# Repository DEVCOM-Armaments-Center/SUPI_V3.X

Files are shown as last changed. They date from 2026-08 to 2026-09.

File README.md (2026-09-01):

# sUPI — Small Universal Payload Interface

**Technical Data Package, Version 3.3**

> **DISTRIBUTION STATEMENT A. APPROVED FOR PUBLIC RELEASE; DISTRIBUTION IS UNLIMITED.**

---

## Overview

sUPI is an interchangeable mechanical and electrical interface for attaching payloads to uncrewed
systems, primarily small UAS. It is a one-to-one peripheral interface: one platform, one payload, no
network.

sUPI was developed under U.S. Army Special Operations Command and has since been transitioned to
DEVCOM Armaments Center. The **CLIK Lite** adaptation in Appendix A of the Picatinny Common
Lethality Integration Kit (CLIK) Design Standard is modeled on sUPI. CLIK Lite exists for platforms
constrained in size, weight, and power — Short Range Reconnaissance and Purpose Built Attritable
System aircraft — where the full CLIK rail-and-network interface does not fit.

The standard is not redistributed here; request the current revision from the design activity.

sUPI is a **reference design**, intended to evolve. See `MFR_Reference_Design.md` for how to submit
recommendations.

### The Two Halves

| Half | Mounts to | Role |
| --- | --- | --- |
| **Platform side** | The vehicle | Gates and monitors payload power, switches USB, hosts the interface MCU |
| **Payload side** | The payload | Regulates platform battery to payload rails, carries the payload ID device |

Start with [`sUPI_Platform_Brief.md`](sUPI_Platform_Brief.md) or
[`sUPI_Payload_Brief.md`](sUPI_Payload_Brief.md) depending on which side you are integrating.

### Circuit Cards

| Card | Project | Assembly | Layers | Notes |
| --- | --- | --- | --- | --- |
| Platform | `PB-F-0213` | `PB-F-0210` A.6 (`100064667`) | 8 | The only platform-side card |
| Payload — Fusion | `PB-F-0212` | `PB-F-0209` A.3 (`100068622-001`) | 4 | Full-capability payload card |
| Payload — Medium R2 | `PB-F-0230` | `PB-F-0230` A.6 | 2 | Compact option, adds USB-to-UART |

---

## Electrical Interface

### Platform → Platform-Side Card

| Signal | Range |
| --- | --- |
| `VBATT` / `VBATT_RET` | 13 – 25.2 VDC (4S–6S pack) |
| `GPIO` | Typically PWM, ±5 VDC |
| `USB` | 0 – 3.3 VDC |

### Payload-Side Card → Payload

| Signal | Range |
| --- | --- |
| `VBATT` / `VBATT_RET` | 13 – 25.2 VDC, passed through |
| `V1` | Regulated **3.3 or 5 VDC** — set by solder bridge |
| `V2` | Regulated **5, 7.4, or 12 VDC** — set by solder bridge |
| `GPIO` | Typically PWM, ±3.3 VDC |
| `USB` | 0 – 3.3 VDC |

> **V1 and V2 are hardware-selected.** The rails are set by solder-bridge placement
> at build time. Verify the bridges match the payload before first power-on.

Both cards use solder pads for field wiring: 18–22 AWG for power, 24–30 AWG for signals.

### Board Markings

- **Platform pads:** `VBATT`, `GND`, `GPIO 0`, `GPIO 1`, `+USB−`, `AUX`
- **Platform jumpers:** `DETECT PAYLOAD`, `SELECT`, `FORCE ON`, `LO BATT CUTOFF`
- **Payload pads:** `VBATT`, `GND`, `V1`, `V1 OK`, `V2`, `V2 OK`, `USB DP`, `USB DM`, `GPIO 0`, `GPIO 1`
- **Payload selectors:** `V1SEL` (`3V3` / `5V`), `V2SEL` (`5V` / `7V4` / `12V`)

`FORCE ON` overrides the detect gate — confirm its state before flight.

### Mating Connection

A **9-contact, 0.100"-pitch right-angle spring-pin interface.** The payload side carries the spring
pins (Mill-Max 829 series); the platform side carries the mating targets (Mill-Max 399 series).
Power crosses on separate, larger single-pin contacts.

---

## Platform Card — `PB-F-0210` A.6

8-layer FR4, 0.5 oz outer / 1 oz inner copper, 0.0586 in finished thickness, ENIG per IPC-4552,
green mask. Controlled impedance: 90 Ω ±10 % differential on layer 5, referenced to layers 4 and 6.
Fabrication and inspection per MIL-PRF-31032/1 Type 3.

| Function | Device |
| --- | --- |
| Interface MCU | STM32C011F6 (Arm Cortex-M0+) |
| Payload power switch | MPQ5069, 7 mΩ protection switch with current monitor |
| Current sense | ACS711, ±15 A bidirectional Hall-effect with overcurrent fault output |
| Ideal-diode / reverse-polarity control | NCV68261 driving an NTTFS2D1N04HL N-channel MOSFET |
| Undervoltage supervisor | LTC2965 |
| Supply supervisor | MAX821, 2.78 V |
| Detect / enable logic | SN74LVC1G08 AND gate, SN74AUP2G04 inverter |
| Logic 3.3 V rail | NCP730 LDO, 150 mA |
| USB routing | TC7USB40MU dual SPDT, MAX20336 DPST |
| Transient protection | SMF26A 26 V TVS on `VBATT`, SMF3.3 on signals, PESD5V0C2UM on USB |

---

## Payload Cards

Two payload-side cards are released. Both present the same interface to the platform and both carry
the DS2431 1-Wire EEPROM that the platform MCU reads to identify an attached payload, so a payload
built to this interface inherits its identity device from the card.

### Fusion Payload — `PB-F-0209` A.3

The full-capability card. 4-layer FR4, 1 oz copper, 0.0442 in finished thickness, ENIG, green mask.
Controlled impedance 100 Ω ±10 % differential. Fabrication per MIL-PRF-31032/1 Type 3.

| Function | Device |
| --- | --- |
| V1 / V2 regulation | MAX25254, dual 36 V input / 0.8–14 V output synchronous buck, XEL4030 0.47 µH inductors |
| Payload ID / detect | DS2431 1-Wire EEPROM, 1 kbit |
| Input protection | NCV68261 + NTTFS2D1N04HL N-channel MOSFET, DMP610DL P-channel blocking FET |
| Logic 3.3 V rail | NCP730 LDO, 150 mA |
| Supply supervisor | MAX821, 2.78 V |
| USB routing | TC7USB40MU dual SPDT, MAX20336 DPST |
| Transient protection | SMF26A 26 V TVS on `VBATT`, SMF3.3 on signals, PESD5V0C2UM on USB |

### Medium R2 Payload — `PB-F-0230` A.6

A compact alternative for payloads that do not need the dual selectable rails. 2-layer 370HR FR4,
1 oz copper, ENIG, green mask, vias unfilled, no board-manufacturer markings, assembly serial
number silkscreened. Assembly to IPC J-STD-001 Class 3 and IPC-A-610 Class 3.

**Tested against all sUPI v3.X releases.**

| Function | Device |
| --- | --- |
| Regulation | MCP16361, 48 V 2 MHz buck, 2.2 µH inductor |
| Payload power switch | NCP380, fixed current-limiting power distribution switch |
| Supply supervisor | TPS389030 |
| Payload ID / detect | DS2431 1-Wire EEPROM, 1 kbit |
| **USB-to-UART bridge** | **FT232RN** — converts the interface USB link to a serial port on the payload |
| Wire-to-board connectors | 2× JST SM04B-SRSS-TB, 4-position 1.25 mm |
| Status indication | 2× red 625 nm LEDs |
| Mating contacts | 9-contact right-angle spring-pin header |
| Transient protection | SMF26A 26 V TVS, P4FL3.3A on signals, SS3060HE Schottky |

The USB-to-UART bridge is the substantive difference: a payload using the Medium card gets a serial
interface without implementing USB itself.

**Variant.** One variant assembly is released, `PB-F-0230` A.4. It is identical to A.6 except that
`R6` and `R7` — two 0 Ω links — are not populated. Check which assembly you have before assuming a
link is present.

---

## Mechanical Interface

Both halves mount with **M3 × 0.5 mm thread, 8 mm long, black-oxide stainless steel Phillips
flat-head screws.**

| Half | Screws | Controlling drawing |
| --- | --- | --- |
| Platform side | 3X M3 | `19200_13122518` |
| Payload side | 4X M3 | `19200_13122514` |

Two accepted installation methods, either half:

1. **Direct mount** — drill and tap the sUPI hole pattern into the host structure.
2. **Adapter** — fabricate an adapter carrying the sUPI hole pattern on one face and mating to an
   existing interface on the other. Preferred where the host structure cannot be modified.

The payload-side pattern carries a CG reference callout. Position the interface so the center of
gravity lands as close to that point as the installation allows.

### Part Tree

Assembly **13122513**, one each of:

| Part No. | Nomenclature | Material | Process / Finish |
| --- | --- | --- | --- |
| `13122514` | V-Mount Base | 6061-T6 per ASTM B209, or polymer powder bed fusion | Bead blast; hard anodize per MIL-A-8625F Type III Class 2, black, sealed |
| `13122515` | Short Button | 6061-T6 per ASTM B209 | Bead blast; hard anodize per MIL-A-8625F Type III Class 2, black, sealed |
| `13122516` | Small Button Cover | PA12 or PA6 | Polymer powder bed fusion (MJF, SLS, or SAF); depowder, media blast, optional black dye |
| `13122517` | Connector Cover | 6061-T6 per ASTM B209, or polymer powder bed fusion | Bead blast; hard anodize per MIL-A-8625F Type III Class 2, black, sealed |
| `13122518` | V-Mount | 6061-T6 per ASTM B209 | Mask/plug threaded holes, then bead blast and hard anodize per MIL-A-8625F Type III Class 2, black, sealed |

Threaded and clearance features:

- `13122514` — 4× M3 clearance, 90° countersunk; 2× M2 × 0.4 tapped
- `13122517` — 2× M2 × 0.4 clearance
- `13122518` — 3× M3 clearance, 90° countersunk; 3× M1.6 × 0.35 tapped, through

Dimensions are in inches; interpret per ANSI/ASME Y14.5M-2009. **The drawings are the authority** —
each detail sheet names a design model required to complete the product definition, and
undimensioned features are taken from that model. Do not machine from the PDFs alone.

---

## Before You Fabricate Boards

| Note | Direction |
| --- | --- |
| [`MFR_DNP.md`](sUPI%20Electrical/MFR_DNP.md) | Do not populate platform `U3`, `R1`–`R4`, `C2`, `JP1` — the undervoltage cutoff is still in development and can block power to the payload |
| [`MFR_Rework.md`](sUPI%20Electrical/MFR_Rework.md) | Remove platform `U11` and `U12` and bridge pin 2 to pin 4 on each footprint. The bridge is the workaround; removal alone leaves the net open |
| [`MFR_Capacitors.md`](sUPI%20Electrical/MFR_Capacitors.md) | Superseded — its alternates are already in the released BOMs and no Murata parts remain. Build from the BOM. |

All three components named by the do-not-populate and rework notes are still present in the released
platform BOM, so both notes remain live direction.

With that direction applied, the platform card has **no undervoltage supervision and no supply
supervisor**, and its detect/enable gate is strapped to a permanent pass-through. If your
application depends on brownout protection or supervised power sequencing, treat that as an open
engineering item.

The Medium R2 assembly carries its own do-not-populate list on the assembly drawing. For the base
A.6 assembly that list is empty; for the A.4 variant it is `R6`, `R7`.

---

## Firmware

`supi_firmware.hex` is the platform MCU image: 20,440 bytes, load address `0x08000000`, targeting
the STM32C011 (Arm Cortex-M0+). Intel HEX format.

---

## Revision History

See [`CHANGELOG.md`](CHANGELOG.md). Known documentation defects are listed in
[`KNOWN_ISSUES.md`](KNOWN_ISSUES.md).

v3.3 is a manufacturability and fit release on the mechanical side — it removes special tooling from
the machining plan and takes slop out of the mating stack. On the electrical side it adds the
Medium R2 payload card and re-releases all three boards with updated component sourcing.

**v3.3 hardware is physically marked.** Check the engraved version number before mating
mixed-vintage halves: earlier parts have looser fit, and earlier `13122515` buttons have the taller
profile that was prone to bending.

---

## Package Contents

```
.
├── CHANGELOG.md                     Mechanical design change history, v3.1 → v3.3
├── KNOWN_ISSUES.md                  Errata — read before fabricating or machining
├── MFR_Reference_Design.md          Scope of the reference design; how to submit feedback
├── sUPI_Platform_Brief.md           Platform-side integration brief
├── sUPI_Payload_Brief.md            Payload-side integration brief
├── assets/                          Figures for the briefs and changelog
│
├── sUPI Mechanicals/
│   ├── 19200_13122513_v3-3.pdf      Assembly drawing
│   ├── 19200_1312251[4-8]_v3-3.pdf  Detail drawings
│   └── 19200_*_v3-3.stp             Solid models (STEP)
│
├── sUPI Electrical/
│   ├── MFR_DNP.md                   Do-not-populate direction
│   ├── MFR_Rework.md                Platform rework work instructions
│   ├── MFR_Capacitors.md            Capacitor sourcing history
│   ├── Platform/PB-F-0213 …/        Altium project: SRC (schematics, PCB), FAB, ASM
│   └── Payload/
│       ├── PB-F-0212 …/             Fusion payload: SRC, FAB, ASM
│       └── PB-F-0230 …/             Medium R2: SRC, FAB, ASM (base and variant)
│
└── sUPI Firmware/
    └── supi_firmware.hex            Platform MCU image
```

Each board's `FAB-` folder carries the fabrication drawing, GerberX2, IPC2581, ODB++, and NC Drill
data. Each `ASM-` folder carries the assembly drawing and the bill of materials with pick-and-place.

### Where to Start

| You are | Read, in order |
| --- | --- |
| **Platform integrator** | Platform brief → assembly drawing → platform schematics |
| **Payload integrator** | Payload brief → assembly drawing → pick a payload card → its schematics |
| **Fabricating boards** | `MFR_*.md` notes → fabrication drawing → Gerbers / ODB++ → BOM |
| **Machining parts** | Detail drawing + its matching STEP model |
| **Bringing up firmware** | Platform schematics, MCU section → `supi_firmware.hex` |
| **Writing a compliant payload** | Picatinny CLIK Design Standard, Appendix A (request from the design activity), then the payload brief |

---

## Conventions

- **Mechanical part numbers** are 8-digit design-activity numbers, prefixed in filenames with CAGE
  code `19200` and suffixed with the TDP version (`_v3-3`).
- **Circuit card part numbers** are `PB-F-####`. Project folders carry the project number; the
  fabrication and assembly folders inside carry their own numbers and an `A.n` revision.
- **Dimensions** are in inches unless otherwise specified; mechanical tolerances per
  ANSI/ASME Y14.5M-2009, board drawings per ASME Y14.5M-1994 and IPC-2221/2222.
- **Mechanical files:** `.pdf` released drawing, `.stp` neutral solid model.
- **Electrical files:** `.PDF` fabrication and assembly drawings, `.SchDoc` / `.PcbDoc` Altium
  source, GerberX2, `.cvg` IPC2581, ODB++ archives, NC Drill, `.xlsx` BOM and pick-and-place.
- **Packaging and marking** per MIL-STD-2073-1 Method 10 and MIL-STD-130.

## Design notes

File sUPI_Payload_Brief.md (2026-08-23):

# Small Universal Payload Interface (sUPI) — Payload Side Brief

**sUPI v3.3**

> **DISTRIBUTION STATEMENT A. APPROVED FOR PUBLIC RELEASE; DISTRIBUTION IS UNLIMITED.**

---

## Overview

The sUPI interface provides an interchangeable interface to connect payloads to UxS platforms such
as drones. The interface is a subset of the Picatinny Common Lethality Interface Kit (CLIK) Design
Standard. The interface supports a detect mechanism in which the payload signals are controlled by
the platform's interface board. The payload interface board provides power to the payload and
connectivity for USB and GPIOs passed through the physical / electrical interface.

---

## Electrical Interface for Payload

The sUPI payload side electronics board has solder pads for connecting wires to the payload
interfaces. Connections should be made with 18–22 AWG wire for power (`VBATT`, `VBATT_RET`) and
24–30 AWG for signals, as indicated in the wiring diagram (Figure 1).

The payload board will provide regulated power based upon solder bridge placement over the `V1SEL`
and `V2SEL` selections.

| Signal | Range |
| --- | --- |
| `VBATT` | Platform battery, 13 to 25.2 VDC |
| `VBATT_RET` | Battery return |
| `V1` | Regulated power, 3.3 or 5 VDC |
| `V2` | Regulated power, 5, 7.4 or 12 VDC |
| `GPIO` | Typically PWM, ±5 VDC |
| `USB` | 0 to 3.3 VDC |

### Rail Selection

`V1` and `V2` are set by solder bridge at build time; there is no runtime negotiation. Verify the
bridges match the payload's requirements before first power-on.

| Selector | Options |
| --- | --- |
| `V1SEL` | `3V3` or `5V` |
| `V2SEL` | `5V`, `7V4` (7.4 V), or `12V` |

### Solder Pads

The payload board silkscreen labels its wiring pads directly: `VBATT`, `GND`, `V1`, `V1 OK`, `V2`,
`V2 OK`, `USB DP`, `USB DM`, `GPIO 0`, `GPIO 1`.

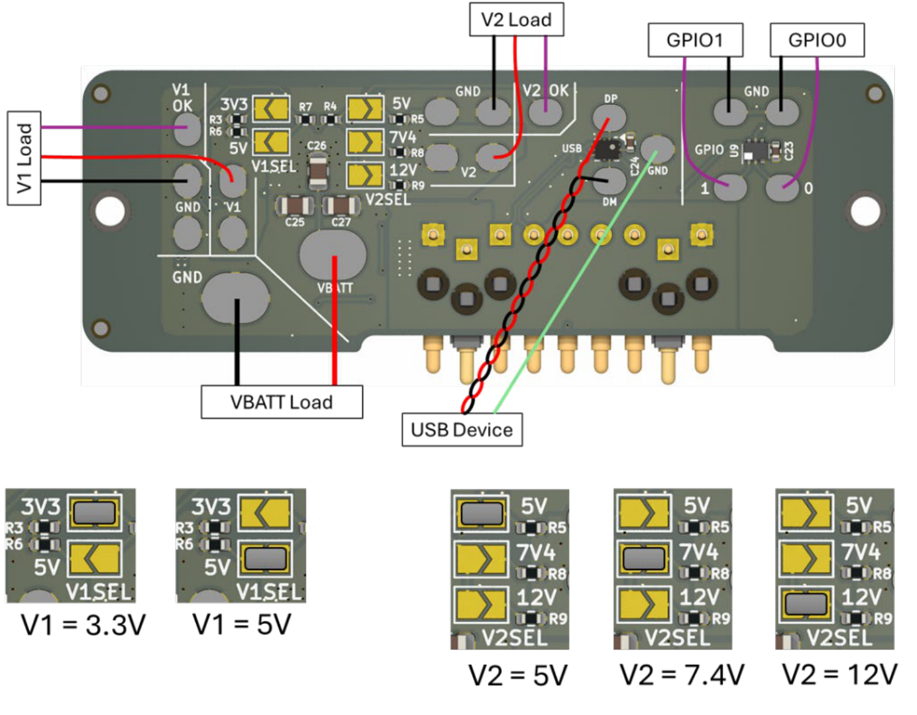
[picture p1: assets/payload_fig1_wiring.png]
Figure 1 — Payload side wiring and rail selection. Board pads at top; V1SEL and V2SEL solder bridge options below.


**Figure 1.** Payload side wiring diagram and rail selection. Lower panels show the valid `V1SEL`
and `V2SEL` solder bridge placements.

---

## Mechanical Interface for Payload

The sUPI Payload Side is intended to be mounted to a payload via **4X M3 × 0.5 mm thread, 8 mm
long, black-oxide stainless steel Phillips flat head screws** (e.g. McMaster PN 91698A304). The
mounting hole pattern is shown in Figure 2.

Existing payloads should be modified in one of the following ways to install a sUPI Payload Side
interface:

- **Drill and tap 4X holes** into the payload as shown in Figure 2, in the desired location for
  mounting the sUPI payload side. For a UAV platform, it is recommended that the vehicle CG align as
  closely as possible with the point indicated in Figure 2.
- **Create a custom adapter** that includes the sUPI Payload Side hole pattern and enables mounting
  to an existing mounting interface on a payload.

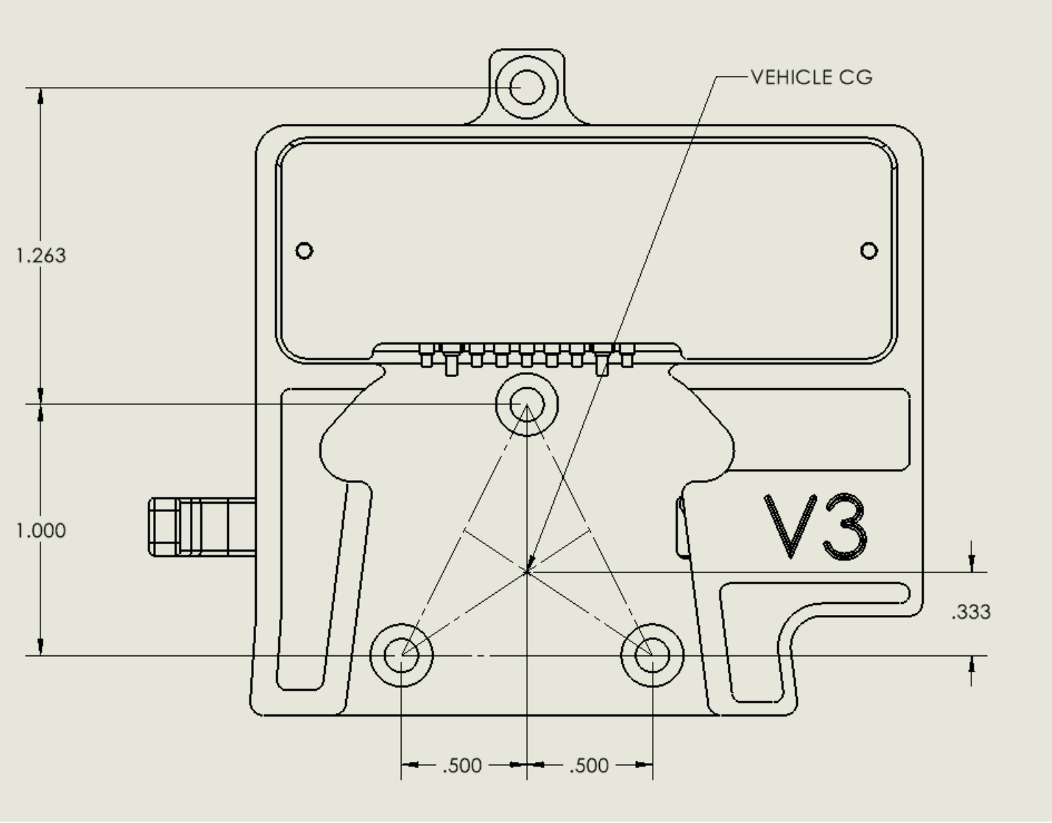
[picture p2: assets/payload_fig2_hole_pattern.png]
Figure 2 — Payload side mounting hole pattern, four M3 holes, with the vehicle CG reference point marked


**Figure 2.** Payload side mounting hole pattern — 4X M3, viewed from the mounting face. Dimensions
in inches. The `VEHICLE CG` callout marks the recommended center-of-gravity reference point. The two
smaller holes are M2 board-mounting features, not host mounting points.

Refer to drawing `19200_13122514` for controlling dimensions and tolerances.

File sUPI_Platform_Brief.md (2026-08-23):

# Small Universal Payload Interface (sUPI) — Platform Side Brief

**sUPI v3.3**

> **DISTRIBUTION STATEMENT A. APPROVED FOR PUBLIC RELEASE; DISTRIBUTION IS UNLIMITED.**

---

## Overview

The sUPI interface provides an interchangeable interface to connect payloads to UxS platforms such
as drones. The interface is a subset of the Picatinny Common Lethality Interface Kit (CLIK) Design
Standard. The interface supports a detect mechanism in which the payload signals are controlled by
the platform's interface board. The payload interface board provides power to the payload and
connectivity for USB and GPIOs passed through the physical / electrical interface.

---

## Electrical Interface for Platform

The sUPI platform side electronics board has solder pads for connecting wires to platform avionics.
Connections should be made with 18–22 AWG wire for power (`VBATT`, `VBATT_RET`) and 24–30 AWG for
signals, as indicated in the wiring diagram (Figure 1).

The platform will need to provide the following to the sUPI interface board:

| Signal | Range |
| --- | --- |
| `VBATT` | Platform battery, 13 to 25.2 VDC |
| `VBATT_RET` | Battery return |
| `GPIO` | Typically PWM, ±5 VDC |
| `USB` | 0 to 3.3 VDC |

The 13 to 25.2 VDC range corresponds to a 4S–6S lithium-polymer pack.

### Solder Pads and Jumpers

The platform board silkscreen labels its wiring pads and configuration jumpers directly:

- **Wiring pads:** `VBATT`, `GND`, `GPIO 0`, `GPIO 1`, `+USB−`, `AUX`
- **Configuration jumpers:** `DETECT PAYLOAD`, `SELECT`, `FORCE ON`, `LO BATT CUTOFF`

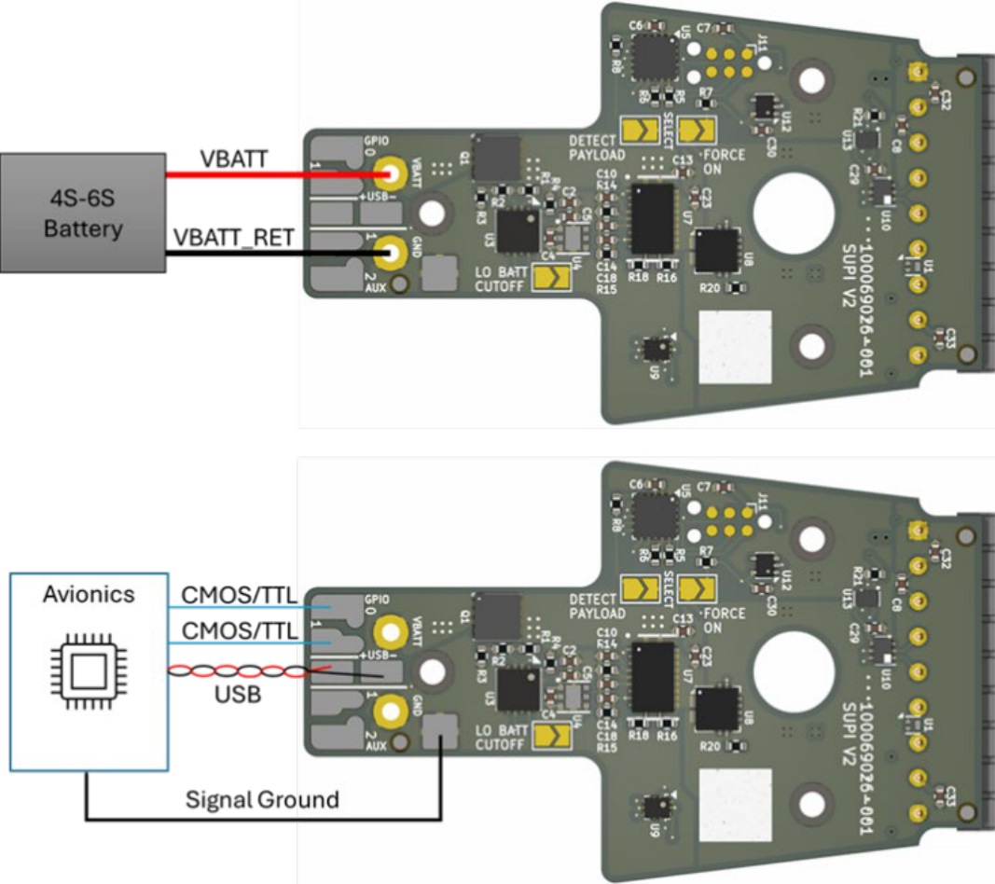
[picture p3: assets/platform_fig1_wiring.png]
Figure 1 — Platform side wiring. Top: battery connection to VBATT and GND. Bottom: avionics connections to GPIO, USB, and ground.


**Figure 1.** Platform side wiring diagram. Battery to `VBATT` / `GND`; avionics to `GPIO`, `+USB−`,
and ground.

---

## Mechanical Interface for Platform

The sUPI Platform Side is intended to be mounted to a platform via **3X M3 × 0.5 mm thread, 8 mm
long, black-oxide stainless steel Phillips flat head screws** (e.g. McMaster PN 91698A304). The
mounting hole pattern is shown in Figure 2.

Platforms should be modified in one of the following ways to install a sUPI Platform Side
interface:

- **Drill and tap 3X holes** into the platform as shown in Figure 2, in the desired location for
  mounting the sUPI Platform Side.
- **Create a custom adapter** that includes the sUPI platform side hole pattern and enables mounting
  to an existing mounting interface on a platform.

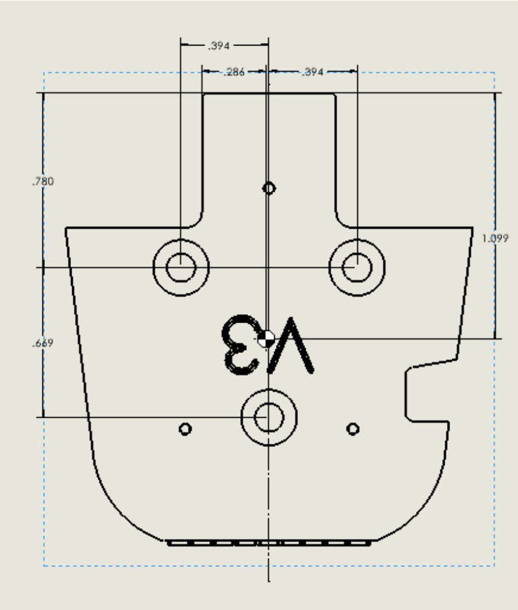
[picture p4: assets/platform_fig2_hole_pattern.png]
Figure 2 — Platform side mounting hole pattern, three M3 holes


**Figure 2.** Platform side mounting hole pattern — 3X M3, viewed from the mounting face.
Dimensions in inches. The three smaller holes are M1.6 board-mounting features, not host mounting
points.

Refer to drawing `19200_13122518` for controlling dimensions and tolerances.

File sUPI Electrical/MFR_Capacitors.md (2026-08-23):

# sUPI Electrical Interfaces — Capacitors

**DEPARTMENT OF THE ARMY**
U.S. Army Combat Capabilities Development Command, Armaments Center
Picatinny Arsenal, New Jersey 07806-5000

| | |
| --- | --- |
| **Office Symbol** | FCDD-ACE-P |
| **Date** | 30 March 2026 |
| **Subject** | sUPI Electrical Interfaces Capacitors |
| **Applies to** | Payload card `PB-F-0209`, platform card `PB-F-0210` |

> **DISTRIBUTION STATEMENT A. APPROVED FOR PUBLIC RELEASE; DISTRIBUTION IS UNLIMITED.**

> ### Superseded — build from the BOM
>
> The alternate part numbers below are **already in the released v3.3 bills of material.** No Murata
> parts remain on any of the three circuit cards, and several passive positions are multi-sourced
> beyond what this note lists. Build from the released BOM.

---

## Background

Note Murata's business statement regarding the use of their products for weapon systems:
<https://www.murata.com/en-us/support/militaryrestriction>

To reduce burden, the following were identified as possible alternatives. Values, dielectrics,
voltage ratings, and package sizes are unchanged from the BOMs as they stood at the time.

---

## Payload

| Ref | Qty | Value | Description | Alternate MPN | Manufacturer |
| --- | --- | --- | --- | --- | --- |
| `C1`, `C6` | 2 | 4.7 µF 50 V | CAP CER 4.7UF 50V X7R 0805 | `C2012X7R1H475K125AC` | TDK |
| `C2` | 1 | 2.2 µF 35 V | CAP CER 2.2UF 35V X5R 0402 | `C1005X5R1V225K050BC` | TDK |
| `C3` | 1 | 10 µF 50 V | CAP CER 10UF 50V X5R 0805 | `CL21A106KBYQNNE` | Samsung |
| `C4`, `C7`, `C10`, `C11`, `C21`, `C22`, `C23`, `C24` | 8 | 0.1 µF 50 V | CAP CER 0.1UF 50V X7R 0402 | `CGA2B3X7R1H104M050BB` | TDK |
| `C5`, `C9` | 2 | 10 µF 6.3 V | CAP CER 10UF 6.3V X5R 0402 | `GMC04X5R106M6R3NT` | CAL-Chip Electronics |
| `C8` | 1 | 10000 pF 50 V | CAP CER 10000PF 50V X7R 0402 | `CGA2B3X7R1H103K050BB` | TDK |
| `C12`, `C13` | 2 | 10 pF 50 V | CAP CER 10PF 50V C0G/NP0 0402 | `04025U100F4T2A` | Kyocera AVX |
| `C14`–`C19` | 6 | 22 µF 25 V | CAP CER 22UF 25V X5R 0805 | `C2012X5R1V226M125AC` | TDK |

## Platform

| Ref | Qty | Value | Description | Alternate MPN | Manufacturer |
| --- | --- | --- | --- | --- | --- |
| `C1`, `C2`, `C6`, `C7`, `C13`, `C18`, `C23`, `C27`–`C33` | 14 | 0.1 µF 50 V | CAP CER 0.1UF 50V X7R 0402 | `C1005X7R1H104K050BB` | TDK |
| `C3`, `C11`, `C12` | 3 | 10 µF 50 V | CAP CER 10UF 50V X5R 0805 | `C0805B106K050T` | Holy Stone Enterprise Co |
| `C4`, `C14` | 2 | 10000 pF 50 V | CAP CER 10000PF 50V X7R 0402 | `CC0402KRX7R9BB103` | YAGEO |
| `C5`, `C9` | 2 | 10 µF 6.3 V | CAP CER 10UF 6.3V X5R 0402 | `CL05A106MP5NUNC` | Samsung |
| `C8` | 1 | 4700 pF 50 V | CAP CER 4700PF 50V X7R 0402 | `C0402C472K5RACTU` | Kemet |
| `C10` | 1 | 0.33 µF 10 V | CAP CER 0.33UF 10V X5R 0402 | `CGA2B1X7S1C334M050BC` | TDK |
| `C24` | 1 | 4.7 µF 50 V | CAP CER 4.7UF 50V X7R 0805 | `CGA4J1X7R1H475K125AC` | TDK |

---

## Notes on the Substitutions

- Two positions were already TDK and unchanged: payload `C25`–`C27` and platform
  `C15`–`C22`, both 22 µF 35 V `C2012X5R1V226M125AC` (TDK).
- Platform `C10` was a `GRT`-series part (automotive, soft-termination); the alternate is an `X7S`
  dielectric rather than the original `X5R`. The released BOM adopted the `X7S` part at 16 V.

---

**Respectfully submitted,**

Robert Barone Jr, PMP \
Special Project APO \
U.S. Army Combat Capabilities Development Command, Armaments Center \
Picatinny Arsenal, NJ 07806 \
W: 520-684-1640 \

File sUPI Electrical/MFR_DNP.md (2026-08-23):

# sUPI Electrical Interfaces — Do Not Populate

**DEPARTMENT OF THE ARMY**
U.S. Army Combat Capabilities Development Command, Armaments Center
Picatinny Arsenal, New Jersey 07806-5000

| | |
| --- | --- |
| **Office Symbol** | FCDD-ACE-P |
| **Date** | 30 March 2026 |
| **Subject** | sUPI Electrical Interfaces Do Not Populate |
| **Applies to** | Platform card `PB-F-0210` (assembly `100064667`) |

> **DISTRIBUTION STATEMENT A. APPROVED FOR PUBLIC RELEASE; DISTRIBUTION IS UNLIMITED.**

---

## Direction

The low-battery / undervoltage cutoff feature of the sUPI reference design is under development and
in its current form can prevent power being supplied to sUPI payloads.

Unless the feature is specifically required, **do not populate** the following components on the
**platform** board. Omitting them is also a cost saving.

| Reference | Device | Function |
| --- | --- | --- |
| `U3` | LTC2965HDD | Undervoltage supervisor |
| `R1` | 787 kΩ, 1%, 0402 | Undervoltage threshold divider |
| `R2` | 12.4 kΩ, 0.1%, 0402 | Undervoltage threshold divider |
| `R3` | 200 kΩ, 0.1%, 0402 | Undervoltage threshold divider |
| `R4` | 1 kΩ, 1%, 0402 | Supervisor support |
| `C2` | 0.1 µF, 50 V, 0402 | Supervisor decoupling |
| `JP1` | — | Low-battery cutoff jumper |

**Effect:** the platform board is built without undervoltage lockout, so payload power continues to
be supplied as the battery falls. If your application depends on brownout protection, implement it
in platform avionics upstream of this interface.

---

**Respectfully submitted,**

Robert Barone Jr, PMP \
Special Project APO \
U.S. Army Combat Capabilities Development Command, Armaments Center \
Picatinny Arsenal, NJ 07806 \
W: 520-684-1640 \

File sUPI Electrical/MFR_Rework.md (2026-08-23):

# sUPI Electrical Interfaces — Platform Rework

**DEPARTMENT OF THE ARMY**
U.S. Army Combat Capabilities Development Command, Armaments Center
Picatinny Arsenal, New Jersey 07806-5000

| | |
| --- | --- |
| **Office Symbol** | FCDD-ACE-P |
| **Date** | 30 March 2026 |
| **Subject** | sUPI Electrical Interfaces Platform Rework |
| **Applies to** | Platform card `PB-F-0210` (assembly `100064667`) |

> **DISTRIBUTION STATEMENT A. APPROVED FOR PUBLIC RELEASE; DISTRIBUTION IS UNLIMITED.**

---

## Problem

During platform testing, current draw and voltage drops during certain high-demand maneuvers
resulted in intermittent issues with some of the logic gates on the platform board.

## Direction

The short-term workaround is to remove `U12` and `U11` from the platform board **and bridge across
each footprint**, so the removed device is bypassed rather than left open.

> **The memo body calls this a "do not populate." The work instructions require a jumper in both
> positions.** Follow the work instructions.

| Reference | Device | Function | Action |
| --- | --- | --- | --- |
| `U12` | SN74LVC1G08DRLR | Single AND gate, low-voltage CMOS | Remove; wire pin 2 to pin 4 |
| `U11` | MAX821UUS+T | Supply supervisor, 2.78 V, SOT143-4 | Remove; wire pin 2 to pin 4, no connection to pin 1 or 3 |

---

### `U12` Rework

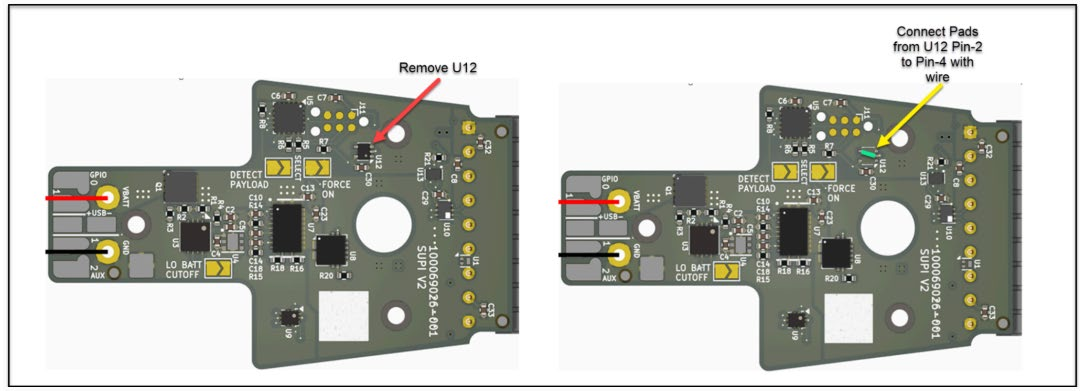
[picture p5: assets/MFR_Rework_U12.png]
U12 rework — remove U12, then connect pads from U12 pin 2 to pin 4 with wire


1. Remove `U12`.
2. Connect the pads from `U12` pin 2 to pin 4 with wire.

### `U11` Rework

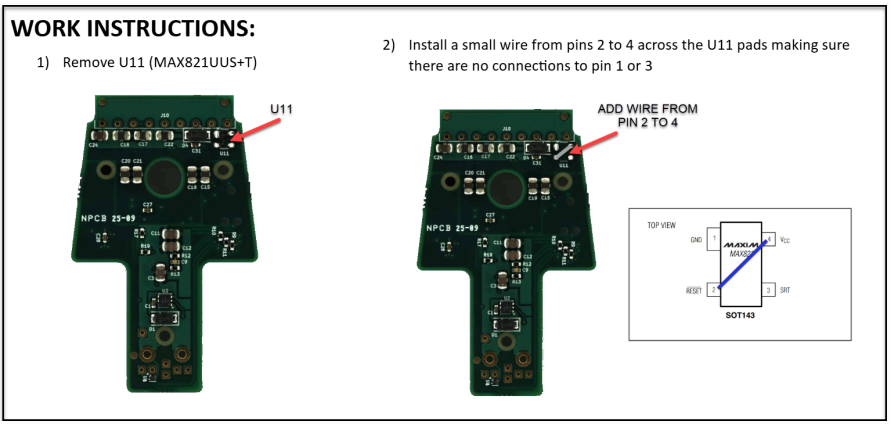
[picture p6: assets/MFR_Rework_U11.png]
U11 work instructions — remove U11, then install a wire from pin 2 to pin 4 across the U11 pads


1. Remove `U11` (MAX821UUS+T).
2. Install a small wire from pins 2 to 4 across the `U11` pads, clear of pins 1 and 3.

> **The boards photographed above are silkscreened `SUPI V2`.** Verify designator locations against
> the v3.3 fabrication drawing before reworking current hardware.

---

## Combined Effect

Applied together with the do-not-populate direction, the platform board ships without **both** its
undervoltage supervisor (`U3`) and its supply supervisor (`U11`), and with its detect/enable AND
gate (`U12`) bypassed to a permanent pass-through. Provide brownout protection and supply
supervision in platform avionics if the application requires them.

---

**Respectfully submitted,**

Robert Barone Jr, PMP \
Special Project APO \
U.S. Army Combat Capabilities Development Command, Armaments Center \
Picatinny Arsenal, NJ 07806 \
W: 520-684-1640 \

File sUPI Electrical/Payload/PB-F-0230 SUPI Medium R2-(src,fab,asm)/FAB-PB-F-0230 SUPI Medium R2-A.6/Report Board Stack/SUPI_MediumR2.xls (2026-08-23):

Board Stack Report
Stack Up |  | Layer Stack
Layer | Board Layer Stack | Name | Material | Thickness | Constant
1 |  | Top Overlay |  | 0mil
2 |  | Top Solder | Solder Resist | 0.4mil | 3.5
3 |  | Top Layer |  | 1.4mil
4 |  | Dielectric1 | 370HR FR-4 | 59mil | 4.8
5 |  | Bottom Layer |  | 1.4mil
6 |  | Bottom Solder | Solder Resist | 0.4mil | 3.5
7 |  | Bottom Overlay |  | 0mil
 | Height : 62.6mil

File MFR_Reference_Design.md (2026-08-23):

# sUPI Interfaces — Reference Design Scope and Feedback

**DEPARTMENT OF THE ARMY**
U.S. Army Combat Capabilities Development Command, Armaments Center
Picatinny Arsenal, New Jersey 07806-5000

| | |
| --- | --- |
| **Office Symbol** | FCDD-ACE-P |
| **Date** | 19 August 2026 |
| **Subject** | sUPI Interfaces |

> **DISTRIBUTION STATEMENT A. APPROVED FOR PUBLIC RELEASE; DISTRIBUTION IS UNLIMITED.**

---

## Scope

The small Universal Payload Interface (sUPI) is a **reference design** to create a baseline for a
lethality interface between payloads and platforms. The intent is for the design to evolve as
technologies evolve.

## Submitting Recommendations

Recommendations for improvements should be submitted to **PM CCS**, **PM UAS**, **PM SWAR**, and
**DEVCOM AC** at the current point in time. Refer to your government point of contact to ensure
feedback reaches the appropriate POC.

## Ongoing Work

There are currently science and technology efforts focused on testing the limits of sUPI and the
Common Lethality Integration Kit (CLIK) Design Specification. Considerations for forward and
backward compatibility will be taken into account before revisions are made to the specifications.

sUPI v3.3 shows some of those considerations with the **sUPI medium payload interface card**. The
sUPI medium has been tested with all sUPI v3.X releases.

---

**Respectfully submitted,**

Robert Barone Jr, PMP \
Special Project APO \
U.S. Army Combat Capabilities Development Command, Armaments Center \
Picatinny Arsenal, NJ 07806 \
W: 520-684-1640 \

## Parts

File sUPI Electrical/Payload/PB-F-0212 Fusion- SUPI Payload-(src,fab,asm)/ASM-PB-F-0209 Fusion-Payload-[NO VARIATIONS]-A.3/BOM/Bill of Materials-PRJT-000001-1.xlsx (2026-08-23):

Bill of Materials
Assembly Part Number: |  |  |  |  | Barcode |  | *-REV<Parameter VersionControl_ProjFolderRevNumber not found>*
Qty: | 1 | Revision: |  | <Parameter VersionControl_ProjFolderRevNumber not found> | Date: |  | 6/4/2026
FIND NO | Barcode | REFERENCE DESIGNATION | QTY | DESCRIPTION | PART NUMBER | Footprint | Need | Leader Qty | Order | Receive | PRF# | Status | Supplier 1 | Supplier Part Number 1 | Manufacturing Notes
1 | *1* | C1, C6 | 2 | CAP 0805 4.7UF 50V 10% X7R | CGA4J1X7R1H475K125AE | CAP-0805-A | 2 | 100 | 102 |  |  | NEED | DigiKey | 445-181410-6-ND
 | ** | C2 | 1 | CAP 0402 2.2UF 35V 10% X5R | C1005X5R1V225K050BC | CAP-0402-A | 1 | 100 | 101 |  |  | NEED | DigiKey | 445-9028-6-ND
3 | *3* | C3 | 1 | CAP 0805 10UF 50V 10% X5R | C2012X5R1H106K125AC | CAP-0805-A | 1 | 100 | 101 |  |  | NEED | DigiKey | 445-C2012X5R1H106K125ACDKR-ND
 | ** | C4, C7, C8, C10, C11, C21, C22, C23, C24 | 9 | CAP 0402 0.1UF 50V 10% X5R | CC0402KRX5R9BB104 | CAP-0402-A | 9 | 100 | 109 |  |  | NEED | DigiKey | 311-3342-1-ND
5 | *5* | C5, C9 | 2 | Cap 0402 10uF 10V 20% X5R | CC0402MRX5R6BB106 | CAP-0402-A | 2 | 100 | 102 |  |  | NEED | DigiKey | 13-CC0402MRX5R6BB106DKR-ND
 | ** | C12, C13 | 2 | Cap Ceramic 10pF 50V C0G 2% Pad SMD 0402 125°C T/R | CC0402GRNPO9BN100 | CAP-0402-A | 2 | 100 | 102 |  |  | NEED | Newark | CC0402GRNPO9BN100
8 | *8* | C14, C15, C16, C17, C18, C19 | 6 | Cap 0805 22uF 25V 20% X5R | 08053D226MAT2A | CAP-0805-A | 6 | 100 | 106 |  |  | NEED | Mouser | 581-08053D226MAT2A
9 | *9* | C20 | 1 | CAP 0402 4700PF 50V 10% X7R | C0402C472K5RACAUTO | CAP-0402-A | 1 | 100 | 101 |  |  | NEED
 | ** | C25, C26, C27 | 3 | CAP 0805 22UF 35V 20% | C2012X5R1V226M125AC | CAP-0805-A | 3 | 100 | 103 |  |  | NEED | Mouser | 810-C2012X5R1V226MAC
 | ** | D1 | 1 | SMF Series 200 W 26 V Uni-Directional Surface Mount TVS Diode - SOD-123F | SMF26A | DI-SOD123F-A | 1 |  | 1 |  |  | NEED | DigiKey | F5824CT-ND
 | ** | D2 | 1 | ESD protection diodes / TVS diodes; LITTELFUSE; SMF3.3; 6.8 V; 30 A; 3.3 V; 3.4 V - 4.3 V | SMF3.3 | DI-SOD123F-A | 1 |  | 1 |  |  | NEED | DigiKey | F7701DKR-ND
14 | *14* | JP1, JP2 | 2 |  |  | SolderJumper-2_P1.3mm_Open_TrianglePad1.0x1.5mm | 2 |  | 2 |  |  | NEED
15 | *15* | JP3, JP4, JP5 | 3 |  |  | SolderJumper-2_P1.3mm_Open_TrianglePad1.0x1.5mm | 3 |  | 3 |  |  | NEED
 | ** | L1, L2 | 2 | General Purpose Inductor, 0.47uH, 20%, 1 Element, Composite-Core, SMD, 1616 | XEL4030-471MEC | IND-1616-A | 2 |  | 2 |  |  | NEED | Coilcraft Direct | XEL4030-471MEC
 | ** | L3 | 1 | Ferrite Bead, Aec-Q200, 0806, 1A Rohs Compliant: Yes |Tdk MDF2016BSS270CTD25 | MDF2016BSS270CTD25 | IND-0806-A | 1 |  | 1 |  |  | NEED | Mouser | 810-MDF2016BSS270CTD
18 | *18* | NT1, NT2 | 2 |  |  | NetTie segment - 10 mils horizontal | 2 |  | 2 |  |  | NEED
 | ** | P1, P5 | 2 | Conn Spring Loaded Connector HDR 1 POS Solder RA Thru-Hole 1.14mm MidStroke | 829-22-001-20-001101 | 829-22-001-20-001101-Footprint-1 | 2 | 5 | 7 |  |  | NEED | Mouser | 575-8292200120
20 | *20* | P2, P4 | 2 |  | 829-22-001-20-002101 | 829-22-001-20-002101 | 2 |  | 2 |  |  | NEED | Mouser | 575-8292200120002101
21 | *21* | P3 | 1 |  | 829-22-005-20-001101 | 829-22-005-20-001101 | 1 |  | 1 |  |  | NEED | Mouser | 575-8292200520
22 | *22* | P6, P7, P8, P9, P10, P11, P12, P13, P14, P15, P17, P21, P23, P24 | 14 |  |  | Hand_Solder_Pad_100x80_mil | 14 |  | 14 |  |  | NEED
23 | *23* | P16, P22 | 2 |  |  | Hand_Solder_Pad_200x150_mil | 2 |  | 2 |  |  | NEED
 | ** | P18, P19, P20 | 3 |  |  | Hand_Solder_Pad_100x80_mil | 3 |  | 3 |  |  | NEED
 | ** | Q1 | 1 | Transistor MOSFET N-Channel 40V 150A 8-Pin PQFN T/R | NTTFS2D1N04HLTWG | IC-8PQFN-A | 1 |  | 1 |  |  | NEED | DigiKey | 488-NTTFS2D1N04HLTWGCT-ND
 | ** | Q2 | 1 | Trans Mosfet P-ch 60V 0.18A 3-PIN SOT-23 T/r | DMP610DL-13 | IC-SOT23-3-A | 1 |  | 1 |  |  | NEED | DigiKey | 31-DMP610DL-13DKR-ND
26 | *26* | R1, R2, R13, R14 | 4 | Res 0402 100K 1/10W 1% Thick Flim | CRCW0402100KFKED | RES-0402-C | 4 | 100 | 104 |  |  | NEED | DigiKey | 541-100KLDKR-ND
 | ** | R3 | 1 | RES 0402 34.4K 1/16W 1% | RN73R1ETTP3442F25 | RES-0402-A | 1 | 100 | 101 |  |  | NEED
 | ** | R4, R7 | 2 | RES 0402 11K 1/10W 1% | RK73H1ETTP1102F | RES-0402-C | 2 | 100 | 102 |  |  | NEED | DigiKey | 2019-RK73H1ETTP1102FCT-ND
 | ** | R5, R6 | 2 | RES 0402 57.6K 1/10W 1% | ERJ-2RKF5762X | RES-0402-A | 2 | 100 | 102 |  |  | NEED | DigiKey | P57.6KLCT-ND
 | ** | R8 | 1 | RES 0402 90.9K 1/10W 1% | ERJ-2RKF9092X | RES-0402-A | 1 | 100 | 101 |  |  | NEED | DigiKey | P90.9KLDKR-ND
31 | *31* | R9 | 1 | Res 0402 154K 1/10W 1% Thick Flim | ERJ-2RKF1543X | RES-0402-A | 1 | 100 | 101 |  |  | NEED | Mouser | 667-ERJ-2RKF1543X
32 | *32* | R10, R11 | 2 | Res 0402 100 Ohm 0.1W 1% Thick Film | ERJ-U02F1000X | RES-0402-B | 2 | 100 | 102 |  |  | NEED | DigiKey | 10-ERJ-U02F1000XCT-ND
 | ** | R12 | 1 | Res Thick Film 2512 1K Ohm 1% 1W ±100ppm/C Pad SMD T/R Automotive AEC-Q200 | CRCW25121K00FKEH | RES-2512-C | 1 | 100 | 101 |  |  | NEED | Mouser | 71-CRCW25121K00FKEH
 | ** | U1 | 1 | Extremely low capacitance unidirectional ESD protection diode array | PESD5V0C2UMYL | IC-SOT883-2-B | 1 |  | 1 |  |  | NEED | Newark | PESD5V0C2UMYL
 | ** | U2 | 1 | LDO Regulator, 150 mA, 38 V, 1 uA IQ, with PG 3V3 HZ, WDFN6 2x2 | NCP730BMT330TBG | IC-WDFN6-B | 1 |  | 1 |  |  | NEED | Newark | NCP730BMT330TBG
 | ** | U3 | 1 | Dual 36V Input Voltage, 8A Synchronous Buck Converters with Multiphase Capability and ASIL B Safety Level | MAX25254AFDE/VY+T | IC-FC2QFN23-A | 1 |  | 1 |  |  | NEED | DigiKey | 175-MAX25254AFDE/VY+TCT-ND
 | ** | U4 | 1 | IC EEPROM 1KBIT 1-WIRE 6TDFN | DS2431Q+T&R | IC-TDFN3X3-B | 1 |  | 1 |  |  | NEED | DigiKey | DS2431Q+T&RCT-ND
 | ** | U5 | 1 | OR Controller N-Channel Single 2.4Ohm Automotive 6-Pin WDFNW EP T/R | NCV68261MTWAITBG | IC-WDFN6-C | 1 |  | 1 |  |  | NEED | Mouser | 863-NCV68261MTWAITBG
 | ** | U6 | 1 | 4-Pin, µP Voltage Monitors with Pin-Selectable Power-On Reset Timeout Delay | MAX821UUS+T | IC-SOT143-4-A | 1 |  | 1 |  |  | NEED | DigiKey | MAX821UUS+TCT-ND
 | ** | U7 | 1 | IC INVERTER 2CH 2-INP 6SON Inverter IC 2 Channel 6-SON (1.45x1) | SN74AUP2G04DRYR | IC-SON6-A | 1 |  | 1 |  |  | NEED | DigiKey | 296-27311-1-ND
 | ** | U8 | 1 | USB Interface, 1: 2 Multiplexer/Demultiplexer Switch, USB 2.0, 2.3 V, 4.3 V, UQFN-B, 10 Pins | TC7USB40MU,LF(S2E | IC-UQFN10-A | 1 |  | 1 |  |  | NEED | DigiKey | 264-TC7USB40MU,LF(S2ECT-ND
 | ** | U9 | 1 | Industry's Smallest DPST Can Switch ±5.5V Signals with a Single VCC as Low as 1.6V | MAX20336AEFT+T | IC-FC2QFN-A | 1 |  | 1 |  |  | NEED | Mouser | 700-MAX20336AEFT+T
4 | *4* |  |  |  |  |  | 0 |  | 0 |  |  | READY
5 | *5* |  |  |  |  |  | 0 |  | 0 |  |  | READY
6 | *6* |  |  |  |  |  | 0 |  | 0 |  |  | READY
7 | *7* |  |  |  |  |  | 0 |  | 0 |  |  | READY
8 | *8* |  |  |  |  |  | 0 |  | 0 |  |  | READY
9 | *9* |  |  |  |  |  | 0 |  | 0 |  |  | READY
10 | *10* |  |  |  |  |  | 0 |  | 0 |  |  | READY
11 | *11* |  |  |  |  |  | 0 |  | 0 |  |  | READY
12 | *12* |  |  |  |  |  | 0 |  | 0 |  |  | READY
13 | *13* |  |  |  |  |  | 0 |  | 0 |  |  | READY
14 | *14* |  |  |  |  |  | 0 |  | 0 |  |  | READY
15 | *15* |  |  |  |  |  | 0 |  | 0 |  |  | READY
16 | *16* |  |  |  |  |  | 0 |  | 0 |  |  | READY
17 | *17* |  |  |  |  |  | 0 |  | 0 |  |  | READY
18 | *18* |  |  |  |  |  | 0 |  | 0 |  |  | READY
19 | *19* |  |  |  |  |  | 0 |  | 0 |  |  | READY
20 | *20* |  |  |  |  |  | 0 |  | 0 |  |  | READY
21 | *21* |  |  |  |  |  | 0 |  | 0 |  |  | READY
22 | *22* |  |  |  |  |  | 0 |  | 0 |  |  | READY
23 | *23* |  |  |  |  |  | 0 |  | 0 |  |  | READY
24 | *24* |  |  |  |  |  | 0 |  | 0 |  |  | READY
25 | *25* |  |  |  |  |  | 0 |  | 0 |  |  | READY
26 | *26* |  |  |  |  |  | 0 |  | 0 |  |  | READY
27 | *27* |  |  |  |  |  | 0 |  | 0 |  |  | READY
28 | *28* |  |  |  |  |  | 0 |  | 0 |  |  | READY
29 | *29* |  |  |  |  |  | 0 |  | 0 |  |  | READY
30 | *30* |  |  |  |  |  | 0 |  | 0 |  |  | READY
31 | *31* |  |  |  |  |  | 0 |  | 0 |  |  | READY
32 | *32* |  |  |  |  |  | 0 |  | 0 |  |  | READY
33 | *33* |  |  |  |  |  | 0 |  | 0 |  |  | READY
34 | *34* |  |  |  |  |  | 0 |  | 0 |  |  | READY
35 | *35* |  |  |  |  |  | 0 |  | 0 |  |  | READY
36 | *36* |  |  |  |  |  | 0 |  | 0 |  |  | READY
37 | *37* |  |  |  |  |  | 0 |  | 0 |  |  | READY
38 | *38* |  |  |  |  |  | 0 |  | 0 |  |  | READY
39 | *39* |  |  |  |  |  | 0 |  | 0 |  |  | READY
40 | *40* |  |  |  |  |  | 0 |  | 0 |  |  | READY
41 | *41* |  |  |  |  |  | 0 |  | 0 |  |  | READY
42 | *42* |  |  |  |  |  | 0 |  | 0 |  |  | READY
43 | *43* |  |  |  |  |  | 0 |  | 0 |  |  | READY
44 | *44* |  |  |  |  |  | 0 |  | 0 |  |  | READY
45 | *45* |  |  |  |  |  | 0 |  | 0 |  |  | READY
46 | *46* |  |  |  |  |  | 0 |  | 0 |  |  | READY
47 | *47* |  |  |  |  |  | 0 |  | 0 |  |  | READY
48 | *48* |  |  |  |  |  | 0 |  | 0 |  |  | READY
49 | *49* |  |  |  |  |  | 0 |  | 0 |  |  | READY
50 | *50* |  |  |  |  |  | 0 |  | 0 |  |  | READY
51 | *51* |  |  |  |  |  | 0 |  | 0 |  |  | READY
52 | *52* |  |  |  |  |  | 0 |  | 0 |  |  | READY
53 | *53* |  |  |  |  |  | 0 |  | 0 |  |  | READY
54 | *54* |  |  |  |  |  | 0 |  | 0 |  |  | READY
55 | *55* |  |  |  |  |  | 0 |  | 0 |  |  | READY
56 | *56* |  |  |  |  |  | 0 |  | 0 |  |  | READY
57 | *57* |  |  |  |  |  | 0 |  | 0 |  |  | READY
58 | *58* |  |  |  |  |  | 0 |  | 0 |  |  | READY
59 | *59* |  |  |  |  |  | 0 |  | 0 |  |  | READY
60 | *60* |  |  |  |  |  | 0 |  | 0 |  |  | READY
61 | *61* |  |  |  |  |  | 0 |  | 0 |  |  | READY
62 | *62* |  |  |  |  |  | 0 |  | 0 |  |  | READY
63 | *63* |  |  |  |  |  | 0 |  | 0 |  |  | READY
64 | *64* |  |  |  |  |  | 0 |  | 0 |  |  | READY
65 | *65* |  |  |  |  |  | 0 |  | 0 |  |  | READY
66 | *66* |  |  |  |  |  | 0 |  | 0 |  |  | READY
67 | *67* |  |  |  |  |  | 0 |  | 0 |  |  | READY
68 | *68* |  |  |  |  |  | 0 |  | 0 |  |  | READY
69 | *69* |  |  |  |  |  | 0 |  | 0 |  |  | READY
70 | *70* |  |  |  |  |  | 0 |  | 0 |  |  | READY
71 | *71* |  |  |  |  |  | 0 |  | 0 |  |  | READY
72 | *72* |  |  |  |  |  | 0 |  | 0 |  |  | READY
73 | *73* |  |  |  |  |  | 0 |  | 0 |  |  | READY
74 | *74* |  |  |  |  |  | 0 |  | 0 |  |  | READY
75 | *75* |  |  |  |  |  | 0 |  | 0 |  |  | READY
76 | *76* |  |  |  |  |  | 0 |  | 0 |  |  | READY
77 | *77* |  |  |  |  |  | 0 |  | 0 |  |  | READY
78 | *78* |  |  |  |  |  | 0 |  | 0 |  |  | READY
79 | *79* |  |  |  |  |  | 0 |  | 0 |  |  | READY
80 | *80* |  |  |  |  |  | 0 |  | 0 |  |  | READY
81 | *81* |  |  |  |  |  | 0 |  | 0 |  |  | READY
82 | *82* |  |  |  |  |  | 0 |  | 0 |  |  | READY
83 | *83* |  |  |  |  |  | 0 |  | 0 |  |  | READY
84 | *84* |  |  |  |  |  | 0 |  | 0 |  |  | READY
85 | *85* |  |  |  |  |  | 0 |  | 0 |  |  | READY
86 | *86* |  |  |  |  |  | 0 |  | 0 |  |  | READY

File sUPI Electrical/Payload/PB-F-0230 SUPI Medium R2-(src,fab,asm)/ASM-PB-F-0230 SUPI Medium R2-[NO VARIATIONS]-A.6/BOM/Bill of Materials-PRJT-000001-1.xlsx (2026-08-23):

Bill of Materials
Assembly Part Number: |  |  |  |  | Barcode |  | *-REV<Parameter VersionControl_ProjFolderRevNumber not found>*
Qty: | 1 | Revision: |  | <Parameter VersionControl_ProjFolderRevNumber not found> | Date: |  | 6/16/2026
FIND NO | Barcode | REFERENCE DESIGNATION | QTY | DESCRIPTION | PART NUMBER | Footprint | Need | Leader Qty | Order | Receive | PRF# | Status | Supplier 1 | Supplier Part Number 1 | Manufacturing Notes
1 | *1* | C1 | 1 | CAP 0402 4700PF 50V 10% X7R | C0402C472K5RACTU | CAP-0402-A | 1 | 100 | 101 |  |  | NEED | DigiKey | 399-C0402C472K5RACTUDKR-ND
2 | *2* | C2 | 1 | CAP 0805 0.33uF 50V 10% X7R CER | C0805C334K5RACTU | CAP-0805-A | 1 | 100 | 101 |  |  | NEED | Mouser | 80-C0805C334K5R
3 | *3* | C3, C4 | 2 | CAP 0805 10UF 50V 10% X5R | CC0805KKX5R9BB106 | CAP-0805-A | 2 | 100 | 102 |  |  | NEED | DigiKey | 311-3499-2-ND
4 | *4* | C5, C6 | 2 | CAP 0805 22UF 16V 20% X5R | C2012X5R1C226M125AC | CAP-0805-C | 2 | 100 | 102 |  |  | NEED | Mouser | 810-C2012X5R1C226M
5 | *5* | C7, C8, C9, C10, C11, C12, C13, C17 | 8 | Multilayer Ceramic Capacitor, 0.1 uF, 25 V, ± 10%, X7R, 0402 [1005 Metric] | CL05B104KA5NNNC | CAP-0402-A | 8 | 100 | 108 |  |  | NEED | Mouser | 187-CL05B104KA5NNNC
6 | *6* | C14 | 1 | Cap Ceramic 4.7uF 6.3V JB 10% SMD 0402 85°C Punched Paper T/R | CL05A475KQ5NRNC | CAP-0402-A | 1 | 100 | 101 |  |  | NEED
7 | *7* | C15, C16 | 2 | CAP 0402 47pF 50V 5% C0G/NP0 | LD025A470JAB2A | CAP-0402-A | 2 | 100 | 102 |  |  | NEED | DigiKey | 478-10955-1-ND
8 | *8* | D1 | 1 | SMF Series 200 W 26 V Uni-Directional Surface Mount TVS Diode - SOD-123F | SMF26A | DI-SOD123F-A | 1 |  | 1 |  |  | NEED | Mouser | 637-SMF26A
9 | *9* | D2 | 1 | TVS Diodes & ESD Suppressors; P4FL3.3A_R1_00001; PANJIT; 3.3 V; 5.2 V | P4FL3.3A_R1_00001 | DI-SOD123F-A | 1 |  | 1 |  |  | NEED | DigiKey | 3757-P4FL3.3A_R1_00001DKR-ND
11 | *11* | D3 | 1 | DIODE SCHOTTKY 60V 3A SOD123HE | SS3060HE_R1_00001 | DI-SOD123HE-A | 1 |  | 1 |  |  | NEED | DigiKey | 3757-SS3060HE_R1_00001CT-ND
12 | *12* | D4, D5 | 2 | Red 625nm LED Indication - Discrete 2.2V 0805 | APT2012SECK/J3-PRV | LED-0805-G-A | 2 |  | 2 |  |  | NEED | DigiKey | 754-1791-1-ND
13 | *13* | J1, J2 | 2 | Conn Shrouded Header (4 Sides) HDR 4 POS 1.25mm Solder RA Side Entry SMD T/R | SM04B-SRSS-TB | SM04B-SRSS-TB | 2 |  | 2 |  |  | NEED | DigiKey | 455-SM04B-SRSS-TBDKR-ND
14 | *14* | L1 | 1 | Ferrite Bead, Aec-Q200, 0806, 1A Rohs Compliant: Yes |Tdk MDF2016BSS270CTD25 | MDF2016BSS270CTD25 | IND-0806-A | 1 |  | 1 |  |  | NEED | Mouser | 810-MDF2016BSS270CTD
15 | *15* | L2 | 1 | FIXED IND 2.2UH 3A 72 MOHM SMD | 5-2176797-4 | IND-1210-A | 1 |  | 1 |  |  | NEED | DigiKey | 1712-5-2176797-4DKR-ND
16 | *16* | P5 | 1 | Board Connector, 9 Contact(s), 1 Row(s), Male, Right Angle, Solder Terminal | 829-22-009-20-001101 | 829-22-009-20-001101 | 1 | 5 | 6 |  |  | NEED
17 | *17* | R1 | 1 | Res 0402 100 Ohm 0.1W 1% Thick Film | ERJ-2RKF1000X | RES-0402-B | 1 | 100 | 101 |  |  | NEED | DigiKey | P100LCT-ND
18 | *18* | R2 | 1 | Res 0402 52.3K 1/10W 1% Thick Flim | ERJ2RKF5232X | RES-0402-C | 1 | 100 | 101 |  |  | NEED | DigiKey | P52.3KLCT-ND
19 | *19* | R3 | 1 | Res 0402 113K 1/10W 1% Thick Flim | ERJ-2RKF1133X | RES-0402-C | 1 | 100 | 101 |  |  | NEED | DigiKey | P113KLCT-ND
20 | *20* | R4, R5, R8, R15 | 4 | RES 0402 10K 1/10W 1% | RK73H1ETTPD1002F | RES-0402-A | 4 | 100 | 104 |  |  | NEED | DigiKey | 2019-RK73H1ETTPD1002FDKR-ND
21 | *21* | R6, R7 | 2 | Res 0402 0 Ohm 1/16W 5% Thick Film | RC0402JR-070RL | RES-0402-A | 2 | 100 | 102 |  |  | NEED | Mouser | 603-RC0402JR-070RL
22 | *22* | R13, R14 | 2 | RES 0402 499 OHM 1/10W 1% | RK73H1ETTP4990F | RES-0402-A | 2 | 100 | 102 |  |  | NEED | DigiKey | 2019-RK73H1ETTP4990FDKR-ND
23 | *23* | U1 | 1 | IC EEPROM 1KBIT 1-WIRE 6TDFN | DS2431Q+T&R | IC-TDFN3X3-B | 1 |  | 1 |  |  | NEED | Newark | DS2431Q+T&R
24 | *24* | U2 | 1 | IC BUCK CONVERTER 48V 2MHZ | MCP16361T-E/NMX | MCP16361T-E/NMX | 1 |  | 1 |  |  | NEED | DigiKey | 150-MCP16361T-E/NMXCT-ND
25 | *25* | U3 | 1 | Power Distribution Switch, Current-Limiting (Fixed and Adjustable) Adjustable, Enable H | NCP380HMUAJAATBG | IC-WDFN6-A | 1 |  | 1 |  |  | NEED | DigiKey | NCP380HMUAJAATBGOSCT-ND
26 | *26* | U4 | 1 | Supervisor Open Drain or Open Collector 1 Channel 6-WSON (1.5x1.5) | TPS389030DSER | IC-WSON6-A | 1 |  | 1 |  |  | NEED | DigiKey | 296-51976-1-ND
27 | *27* | U6 | 1 | USB Bridge, USB to UART USB 2.0 UART Interface 32-QFN (5x5) | FT232RNQ-TRAY | IC-QFN32-A | 1 |  | 1 |  |  | NEED
4 | *4* |  |  |  |  |  | 0 |  | 0 |  |  | READY
5 | *5* |  |  |  |  |  | 0 |  | 0 |  |  | READY
6 | *6* |  |  |  |  |  | 0 |  | 0 |  |  | READY
7 | *7* |  |  |  |  |  | 0 |  | 0 |  |  | READY
8 | *8* |  |  |  |  |  | 0 |  | 0 |  |  | READY
9 | *9* |  |  |  |  |  | 0 |  | 0 |  |  | READY
10 | *10* |  |  |  |  |  | 0 |  | 0 |  |  | READY
11 | *11* |  |  |  |  |  | 0 |  | 0 |  |  | READY
12 | *12* |  |  |  |  |  | 0 |  | 0 |  |  | READY
13 | *13* |  |  |  |  |  | 0 |  | 0 |  |  | READY
14 | *14* |  |  |  |  |  | 0 |  | 0 |  |  | READY
15 | *15* |  |  |  |  |  | 0 |  | 0 |  |  | READY
16 | *16* |  |  |  |  |  | 0 |  | 0 |  |  | READY
17 | *17* |  |  |  |  |  | 0 |  | 0 |  |  | READY
18 | *18* |  |  |  |  |  | 0 |  | 0 |  |  | READY
19 | *19* |  |  |  |  |  | 0 |  | 0 |  |  | READY
20 | *20* |  |  |  |  |  | 0 |  | 0 |  |  | READY
21 | *21* |  |  |  |  |  | 0 |  | 0 |  |  | READY
22 | *22* |  |  |  |  |  | 0 |  | 0 |  |  | READY
23 | *23* |  |  |  |  |  | 0 |  | 0 |  |  | READY
24 | *24* |  |  |  |  |  | 0 |  | 0 |  |  | READY
25 | *25* |  |  |  |  |  | 0 |  | 0 |  |  | READY
26 | *26* |  |  |  |  |  | 0 |  | 0 |  |  | READY
27 | *27* |  |  |  |  |  | 0 |  | 0 |  |  | READY
28 | *28* |  |  |  |  |  | 0 |  | 0 |  |  | READY
29 | *29* |  |  |  |  |  | 0 |  | 0 |  |  | READY
30 | *30* |  |  |  |  |  | 0 |  | 0 |  |  | READY
31 | *31* |  |  |  |  |  | 0 |  | 0 |  |  | READY
32 | *32* |  |  |  |  |  | 0 |  | 0 |  |  | READY
33 | *33* |  |  |  |  |  | 0 |  | 0 |  |  | READY
34 | *34* |  |  |  |  |  | 0 |  | 0 |  |  | READY
35 | *35* |  |  |  |  |  | 0 |  | 0 |  |  | READY
36 | *36* |  |  |  |  |  | 0 |  | 0 |  |  | READY
37 | *37* |  |  |  |  |  | 0 |  | 0 |  |  | READY
38 | *38* |  |  |  |  |  | 0 |  | 0 |  |  | READY
39 | *39* |  |  |  |  |  | 0 |  | 0 |  |  | READY
40 | *40* |  |  |  |  |  | 0 |  | 0 |  |  | READY
41 | *41* |  |  |  |  |  | 0 |  | 0 |  |  | READY
42 | *42* |  |  |  |  |  | 0 |  | 0 |  |  | READY
43 | *43* |  |  |  |  |  | 0 |  | 0 |  |  | READY
44 | *44* |  |  |  |  |  | 0 |  | 0 |  |  | READY
45 | *45* |  |  |  |  |  | 0 |  | 0 |  |  | READY
46 | *46* |  |  |  |  |  | 0 |  | 0 |  |  | READY
47 | *47* |  |  |  |  |  | 0 |  | 0 |  |  | READY
48 | *48* |  |  |  |  |  | 0 |  | 0 |  |  | READY
49 | *49* |  |  |  |  |  | 0 |  | 0 |  |  | READY
50 | *50* |  |  |  |  |  | 0 |  | 0 |  |  | READY
51 | *51* |  |  |  |  |  | 0 |  | 0 |  |  | READY
52 | *52* |  |  |  |  |  | 0 |  | 0 |  |  | READY
53 | *53* |  |  |  |  |  | 0 |  | 0 |  |  | READY
54 | *54* |  |  |  |  |  | 0 |  | 0 |  |  | READY
55 | *55* |  |  |  |  |  | 0 |  | 0 |  |  | READY
56 | *56* |  |  |  |  |  | 0 |  | 0 |  |  | READY
57 | *57* |  |  |  |  |  | 0 |  | 0 |  |  | READY
58 | *58* |  |  |  |  |  | 0 |  | 0 |  |  | READY
59 | *59* |  |  |  |  |  | 0 |  | 0 |  |  | READY
60 | *60* |  |  |  |  |  | 0 |  | 0 |  |  | READY
61 | *61* |  |  |  |  |  | 0 |  | 0 |  |  | READY
62 | *62* |  |  |  |  |  | 0 |  | 0 |  |  | READY
63 | *63* |  |  |  |  |  | 0 |  | 0 |  |  | READY
64 | *64* |  |  |  |  |  | 0 |  | 0 |  |  | READY
65 | *65* |  |  |  |  |  | 0 |  | 0 |  |  | READY
66 | *66* |  |  |  |  |  | 0 |  | 0 |  |  | READY
67 | *67* |  |  |  |  |  | 0 |  | 0 |  |  | READY
68 | *68* |  |  |  |  |  | 0 |  | 0 |  |  | READY
69 | *69* |  |  |  |  |  | 0 |  | 0 |  |  | READY
70 | *70* |  |  |  |  |  | 0 |  | 0 |  |  | READY
71 | *71* |  |  |  |  |  | 0 |  | 0 |  |  | READY
72 | *72* |  |  |  |  |  | 0 |  | 0 |  |  | READY
73 | *73* |  |  |  |  |  | 0 |  | 0 |  |  | READY
74 | *74* |  |  |  |  |  | 0 |  | 0 |  |  | READY
75 | *75* |  |  |  |  |  | 0 |  | 0 |  |  | READY
76 | *76* |  |  |  |  |  | 0 |  | 0 |  |  | READY
77 | *77* |  |  |  |  |  | 0 |  | 0 |  |  | READY
78 | *78* |  |  |  |  |  | 0 |  | 0 |  |  | READY
79 | *79* |  |  |  |  |  | 0 |  | 0 |  |  | READY
80 | *80* |  |  |  |  |  | 0 |  | 0 |  |  | READY
81 | *81* |  |  |  |  |  | 0 |  | 0 |  |  | READY
82 | *82* |  |  |  |  |  | 0 |  | 0 |  |  | READY
83 | *83* |  |  |  |  |  | 0 |  | 0 |  |  | READY
84 | *84* |  |  |  |  |  | 0 |  | 0 |  |  | READY
85 | *85* |  |  |  |  |  | 0 |  | 0 |  |  | READY
86 | *86* |  |  |  |  |  | 0 |  | 0 |  |  | READY

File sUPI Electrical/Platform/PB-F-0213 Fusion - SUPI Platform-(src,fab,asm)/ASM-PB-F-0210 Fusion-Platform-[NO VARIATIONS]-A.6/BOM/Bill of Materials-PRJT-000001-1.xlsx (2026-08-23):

Bill of Materials
Assembly Part Number: |  |  |  |  | Barcode |  | *-REV<Parameter VersionControl_ProjFolderRevNumber not found>*
Qty: | 1 | Revision: |  | <Parameter VersionControl_ProjFolderRevNumber not found> | Date: |  | 5/28/2026
FIND NO | Barcode | REFERENCE DESIGNATION | QTY | DESCRIPTION | PART NUMBER | Footprint | Need | Leader Qty | Order | Receive | PRF# | Status | Supplier 1 | Supplier Part Number 1 | Manufacturing Notes
37 | *37* |  | 1 | LDO Regulator, 150 mA, 38 V, 1 uA IQ, with PG 3V3 HZ, WDFN6 2x2 | NCP730BMT330TBG | IC-WDFN6-B | 1 |  | 1 |  |  | NEED | Newark | NCP730BMT330TBG
1 | *1* | C1, C2, C6, C7, C13, C18, C23, C27, C28, C29, C30, C31, C32, C33 | 14 | Cap 0402 100nF 10% X7R | C1005X7R1H104K050BB | CAP-0402-A | 14 | 100 | 114 |  |  | NEED | Mouser | 810-C1005X7R1H104K
2 | *2* | C3, C11, C12 | 3 | CAP 0805 10UF 50V 10% X5R | C0805B106K050T | CAP-0805-A | 3 | 100 | 103 |  |  | NEED | DigiKey | 4587-C0805B106K050TDKR-ND
3 | *3* | C4, C14 | 2 | 0402 10 nF 50 V ±10 % Tolerance X7R SMT Multilayer Ceramic Capacitor | CC0402KRX7R9BB103 | CAP-0402-A | 2 | 100 | 102 |  |  | NEED | Newark | CC0402KRX7R9BB103
4 | *4* | C5, C9 | 2 | Cap 0402 10uF 10V 20% X5R | CC0402MRX5R6BB106 | CAP-0402-A | 2 | 100 | 102 |  |  | NEED | DigiKey | 13-CC0402MRX5R6BB106DKR-ND
5 | *5* | C8 | 1 | CAP 0402 4700PF 50V 10% X7R | C0402C472K5RACAUTO | CAP-0402-A | 1 | 100 | 101 |  |  | NEED
6 | *6* | C10 | 1 | Cap 0402 0.33uF 16V 10% X7S | CGA2B1X7S1C334M050BC | CAP-0402-A | 1 | 100 | 101 |  |  | NEED | DigiKey | 445-CGA2B1X7S1C334M050BCCT-ND
7 | *7* | C15, C16, C17, C19, C20, C21, C22 | 7 | CAP 0805 22uF 35V 20% X5R | C2012X5R1V226M125AC | CAP-0805-A | 7 | 25 | 32 |  |  | NEED | Newark | C2012X5R1V226M125AC
8 | *8* | C24 | 1 | CAP 0805 4.7UF 50V 10% X7R | C2012X7R1H475K125AC | CAP-0805-A | 1 | 100 | 101 |  |  | NEED | Mouser | 810-C2012X7R475K125C
9 | *9* | D1 | 1 | SMF Series 200 W 26 V Uni-Directional Surface Mount TVS Diode - SOD-123F | SMF26A | DI-SOD123F-A | 1 |  | 1 |  |  | NEED | DigiKey | F5824CT-ND
10 | *10* | D4 | 1 | ESD protection diodes / TVS diodes; LITTELFUSE; SMF3.3; 6.8 V; 30 A; 3.3 V; 3.4 V - 4.3 V | SMF3.3 | DI-SOD123F-A | 1 |  | 1 |  |  | NEED | DigiKey | F7701DKR-ND
12 | *12* | J1 | 1 |  |  | PTH_18AWG | 1 |  | 1 |  |  | NEED
 | ** | J2 | 1 |  |  | PTH_18AWG | 1 |  | 1 |  |  | NEED
 | ** | J3, J4, J5 | 3 |  |  | PTH_24AWG_offset_rectangular | 3 |  | 3 |  |  | NEED
13 | *13* | J6, J7, J8, J9 | 4 |  |  | PTH_24AWG_offset_rectangular | 4 |  | 4 |  |  | NEED
14 | *14* | J10 | 1 |  | 399-10-109-10-007000 | 399-10-109-10-007000 | 1 |  | 1 |  |  | NEED | Mouser | 575-3991010910007000
15 | *15* | J11 | 1 |  |  | Tag-Connect_TC2030-IDC-NL_2x03_P1.27mm_Vertical | 1 |  | 1 |  |  | NEED
16 | *16* | JP1, JP2 | 2 |  |  | SolderJumper-2_P1.3mm_Open_TrianglePad1.0x1.5mm | 2 |  | 2 |  |  | NEED
17 | *17* | JP3 | 1 |  |  | SolderJumper-2_P1.3mm_Open_TrianglePad1.0x1.5mm | 1 |  | 1 |  |  | NEED
19 | *19* | Q1 | 1 | Transistor MOSFET N-Channel 40V 150A 8-Pin PQFN T/R | NTTFS2D1N04HLTWG | IC-8PQFN-A | 1 |  | 1 |  |  | NEED | DigiKey | 488-NTTFS2D1N04HLTWGCT-ND
20 | *20* | R1 | 1 | RES 0402 787K 1% 1/10W | ERJ-2RKF7873X | RES-0402-A | 1 | 100 | 101 |  |  | NEED | DigiKey | P787KLCT-ND
21 | *21* | R2 | 1 | RES 0402 12.4K 1% 1/16W | CRCW040212K4FKTD | RES-0402-A | 1 | 100 | 101 |  |  | NEED | DigiKey | 541-CRCW040212K4FKTDCT-ND
22 | *22* | R3 | 1 | Res Thick Film 0402 200K Ohm 1% 1/16W ±100ppm/°C Molded SMD SMD Paper Tape on Plastic Reel | AC0402FR-07200KL | RES-0402-C | 1 | 100 | 101 |  |  | NEED | DigiKey | YAG3452DKR-ND
23 | *23* | R4 | 1 | RES 0402 1K 1/10W 1% | ERJ-U02F1001X | RES-0402-A | 1 | 100 | 101 |  |  | NEED | DigiKey | 10-ERJ-U02F1001XDKR-ND
24 | *24* | R5, R6 | 2 | RES 0402 200 OHM 1/10W 1% | RK73H1ETTP2000F | RES-0402-A | 2 | 100 | 102 |  |  | NEED | DigiKey | 2019-RK73H1ETTP2000FCT-ND
25 | *25* | R7, R8 | 2 | Res 0402 2K Ohm 1/10W 1% Thick Flim | ERJ-2RKF2001X | RES-0402-B | 2 | 100 | 102 |  |  | NEED | DigiKey | P2.00KLCT-ND
26 | *26* | R9 | 1 | Res 0402 100 Ohm 0.1W 1% Thick Film | ERJ-U02F1000X | RES-0402-B | 1 | 100 | 101 |  |  | NEED | DigiKey | 10-ERJ-U02F1000XCT-ND
27 | *27* | R10, R11 | 2 | RES 0402 499 OHM 1/10W 1% | RK73H1ETTP4990F | RES-0402-A | 2 | 100 | 102 |  |  | NEED | DigiKey | 2019-RK73H1ETTP4990FDKR-ND
28 | *28* | R12 | 1 | Res 0402 20k 1/16W 1% Thick Film | RC0402FR-0720KL | RES-0402-A | 1 | 100 | 101 |  |  | NEED | Mouser | 603-RC0402FR-0720KL
29 | *29* | R13 | 1 | Res 0402 1.00M 0.1W 1% Thick Film | ERJ-2RKF1004X | RES-0402-C | 1 | 100 | 101 |  |  | NEED | DigiKey | P1.00MLCT-ND
30 | *30* | R14, R15, R20 | 3 | RES 0402 10K 1/10W 1% | RK73H1ETTPB1002F | RES-0402-A | 3 | 100 | 103 |  |  | NEED | Mouser | 660-RK73H1ETTPB1002F
31 | *31* | R16 | 1 | RES 0402 22.1K 1/10W 1% | RK73H1ETTP2212F | RES-0402-A | 1 | 100 | 101 |  |  | NEED | DigiKey | 2019-RK73H1ETTP2212FCT-ND
32 | *32* | R17 | 1 | RES 0402 1.07K 1/10W 1% | ERJ-2RKF1071X | RES-0402-A | 1 | 100 | 101 |  |  | NEED
33 | *33* | R18, R19, R21 | 3 | Res 0402 100K 1/10W 1% Thick Flim | CRCW0402100KFKED | RES-0402-C | 3 | 100 | 103 |  |  | NEED | Mouser | 71-CRCW0402-100K-E3
34 | *34* | U1, U6 | 2 | Extremely low capacitance unidirectional ESD protection diode array | PESD5V0C2UMYL | IC-SOT883-2-B | 2 |  | 2 |  |  | NEED | Newark | PESD5V0C2UMYL
35 | *35* | U2 | 1 | OR Controller N-Channel Single 2.4Ohm Automotive 6-Pin WDFNW EP T/R | NCV68261MTWAITBG | IC-WDFN6-C | 1 |  | 1 |  |  | NEED | Newark | NCV68261MTWAITBG
36 | *36* | U3 | 1 | IC SUPERVISOR 1 CHANNEL 8DFN Supervisor Open Drain or Open Collector 1 Channel 8-DFN (3x3) | LTC2965HDD#PBF | IC-DFN8-3x3-A | 1 |  | 1 |  |  | NEED | DigiKey | LTC2965HDD#PBF-ND
38 | *38* | U5 | 1 | RISC Microcontroller, 32-Bit, FLASH, CORTEX-M4F CPU, 180MHz, CMOS, PBGA216 | STM32C011F6U6TR | IC-UFQFPN20-A | 1 |  | 1 |  |  | NEED
39 | *39* | U7 | 1 | 7mΩ Protection Switch with Current Monitor for Automotive Battery Systems AEC-Q100 Qualified | MPQ5069GQV-AEC1-Z | IC-QFN22-3X5-A | 1 |  | 1 |  |  | NEED
40 | *40* | U8 | 1 | Linear Current Sensor with Overcurrent Fault Output with <100 V Isolation, QFN-12, RoHS | ACS711KEXLT-15AB-T | QFN127P600-8N | 1 |  | 1 |  |  | NEED
41 | *41* | U9 | 1 | USB Interface, 1: 2 Multiplexer/Demultiplexer Switch, USB 2.0, 2.3 V, 4.3 V, UQFN-B, 10 Pins | TC7USB40MU,LF(S2E | IC-UQFN10-A | 1 |  | 1 |  |  | NEED | DigiKey | 264-TC7USB40MU,LF(S2ECT-ND
42 | *42* | U10 | 1 | Industry's Smallest DPST Can Switch ±5.5V Signals with a Single VCC as Low as 1.6V | MAX20336AEFT+T | IC-FC2QFN-A | 1 |  | 1 |  |  | NEED | Mouser | 700-MAX20336AEFT+T
43 | *43* | U11 | 1 | 4-Pin, µP Voltage Monitors with Pin-Selectable Power-On Reset Timeout Delay | MAX821UUS+T | IC-SOT143-4-A | 1 |  | 1 |  |  | NEED | DigiKey | MAX821UUS+TCT-ND
44 | *44* | U12 | 1 | 1-ch, 2-input 1.65-V to 5.5-V 32 mA drive strength AND gate 5-SOT-5X3 -40 to 125 | SN74LVC1G08DRLR | IC-SOT553-A | 1 |  | 1 |  |  | NEED | DigiKey | 296-18011-1-ND
45 | *45* | U13 | 1 | IC INVERTER 2CH 2-INP 6SON Inverter IC 2 Channel 6-SON (1.45x1) | SN74AUP2G04DRYR | IC-SON6-A | 1 |  | 1 |  |  | NEED | DigiKey | 296-27311-1-ND
4 | *4* |  |  |  |  |  | 0 |  | 0 |  |  | READY
5 | *5* |  |  |  |  |  | 0 |  | 0 |  |  | READY
6 | *6* |  |  |  |  |  | 0 |  | 0 |  |  | READY
7 | *7* |  |  |  |  |  | 0 |  | 0 |  |  | READY
8 | *8* |  |  |  |  |  | 0 |  | 0 |  |  | READY
9 | *9* |  |  |  |  |  | 0 |  | 0 |  |  | READY
10 | *10* |  |  |  |  |  | 0 |  | 0 |  |  | READY
11 | *11* |  |  |  |  |  | 0 |  | 0 |  |  | READY
12 | *12* |  |  |  |  |  | 0 |  | 0 |  |  | READY
13 | *13* |  |  |  |  |  | 0 |  | 0 |  |  | READY
14 | *14* |  |  |  |  |  | 0 |  | 0 |  |  | READY
15 | *15* |  |  |  |  |  | 0 |  | 0 |  |  | READY
16 | *16* |  |  |  |  |  | 0 |  | 0 |  |  | READY
17 | *17* |  |  |  |  |  | 0 |  | 0 |  |  | READY
18 | *18* |  |  |  |  |  | 0 |  | 0 |  |  | READY
19 | *19* |  |  |  |  |  | 0 |  | 0 |  |  | READY
20 | *20* |  |  |  |  |  | 0 |  | 0 |  |  | READY
21 | *21* |  |  |  |  |  | 0 |  | 0 |  |  | READY
22 | *22* |  |  |  |  |  | 0 |  | 0 |  |  | READY
23 | *23* |  |  |  |  |  | 0 |  | 0 |  |  | READY
24 | *24* |  |  |  |  |  | 0 |  | 0 |  |  | READY
25 | *25* |  |  |  |  |  | 0 |  | 0 |  |  | READY
26 | *26* |  |  |  |  |  | 0 |  | 0 |  |  | READY
27 | *27* |  |  |  |  |  | 0 |  | 0 |  |  | READY
28 | *28* |  |  |  |  |  | 0 |  | 0 |  |  | READY
29 | *29* |  |  |  |  |  | 0 |  | 0 |  |  | READY
30 | *30* |  |  |  |  |  | 0 |  | 0 |  |  | READY
31 | *31* |  |  |  |  |  | 0 |  | 0 |  |  | READY
32 | *32* |  |  |  |  |  | 0 |  | 0 |  |  | READY
33 | *33* |  |  |  |  |  | 0 |  | 0 |  |  | READY
34 | *34* |  |  |  |  |  | 0 |  | 0 |  |  | READY
35 | *35* |  |  |  |  |  | 0 |  | 0 |  |  | READY
36 | *36* |  |  |  |  |  | 0 |  | 0 |  |  | READY
37 | *37* |  |  |  |  |  | 0 |  | 0 |  |  | READY
38 | *38* |  |  |  |  |  | 0 |  | 0 |  |  | READY
39 | *39* |  |  |  |  |  | 0 |  | 0 |  |  | READY
40 | *40* |  |  |  |  |  | 0 |  | 0 |  |  | READY
41 | *41* |  |  |  |  |  | 0 |  | 0 |  |  | READY
42 | *42* |  |  |  |  |  | 0 |  | 0 |  |  | READY
43 | *43* |  |  |  |  |  | 0 |  | 0 |  |  | READY
44 | *44* |  |  |  |  |  | 0 |  | 0 |  |  | READY
45 | *45* |  |  |  |  |  | 0 |  | 0 |  |  | READY
46 | *46* |  |  |  |  |  | 0 |  | 0 |  |  | READY
47 | *47* |  |  |  |  |  | 0 |  | 0 |  |  | READY
48 | *48* |  |  |  |  |  | 0 |  | 0 |  |  | READY
49 | *49* |  |  |  |  |  | 0 |  | 0 |  |  | READY
50 | *50* |  |  |  |  |  | 0 |  | 0 |  |  | READY
51 | *51* |  |  |  |  |  | 0 |  | 0 |  |  | READY
52 | *52* |  |  |  |  |  | 0 |  | 0 |  |  | READY
53 | *53* |  |  |  |  |  | 0 |  | 0 |  |  | READY
54 | *54* |  |  |  |  |  | 0 |  | 0 |  |  | READY
55 | *55* |  |  |  |  |  | 0 |  | 0 |  |  | READY
56 | *56* |  |  |  |  |  | 0 |  | 0 |  |  | READY
57 | *57* |  |  |  |  |  | 0 |  | 0 |  |  | READY
58 | *58* |  |  |  |  |  | 0 |  | 0 |  |  | READY
59 | *59* |  |  |  |  |  | 0 |  | 0 |  |  | READY
60 | *60* |  |  |  |  |  | 0 |  | 0 |  |  | READY
61 | *61* |  |  |  |  |  | 0 |  | 0 |  |  | READY
62 | *62* |  |  |  |  |  | 0 |  | 0 |  |  | READY
63 | *63* |  |  |  |  |  | 0 |  | 0 |  |  | READY
64 | *64* |  |  |  |  |  | 0 |  | 0 |  |  | READY
65 | *65* |  |  |  |  |  | 0 |  | 0 |  |  | READY
66 | *66* |  |  |  |  |  | 0 |  | 0 |  |  | READY
67 | *67* |  |  |  |  |  | 0 |  | 0 |  |  | READY
68 | *68* |  |  |  |  |  | 0 |  | 0 |  |  | READY
69 | *69* |  |  |  |  |  | 0 |  | 0 |  |  | READY
70 | *70* |  |  |  |  |  | 0 |  | 0 |  |  | READY
71 | *71* |  |  |  |  |  | 0 |  | 0 |  |  | READY
72 | *72* |  |  |  |  |  | 0 |  | 0 |  |  | READY
73 | *73* |  |  |  |  |  | 0 |  | 0 |  |  | READY
74 | *74* |  |  |  |  |  | 0 |  | 0 |  |  | READY
75 | *75* |  |  |  |  |  | 0 |  | 0 |  |  | READY
76 | *76* |  |  |  |  |  | 0 |  | 0 |  |  | READY
77 | *77* |  |  |  |  |  | 0 |  | 0 |  |  | READY
78 | *78* |  |  |  |  |  | 0 |  | 0 |  |  | READY
79 | *79* |  |  |  |  |  | 0 |  | 0 |  |  | READY
80 | *80* |  |  |  |  |  | 0 |  | 0 |  |  | READY
81 | *81* |  |  |  |  |  | 0 |  | 0 |  |  | READY
82 | *82* |  |  |  |  |  | 0 |  | 0 |  |  | READY
83 | *83* |  |  |  |  |  | 0 |  | 0 |  |  | READY
84 | *84* |  |  |  |  |  | 0 |  | 0 |  |  | READY
85 | *85* |  |  |  |  |  | 0 |  | 0 |  |  | READY
86 | *86* |  |  |  |  |  | 0 |  | 0 |  |  | READY

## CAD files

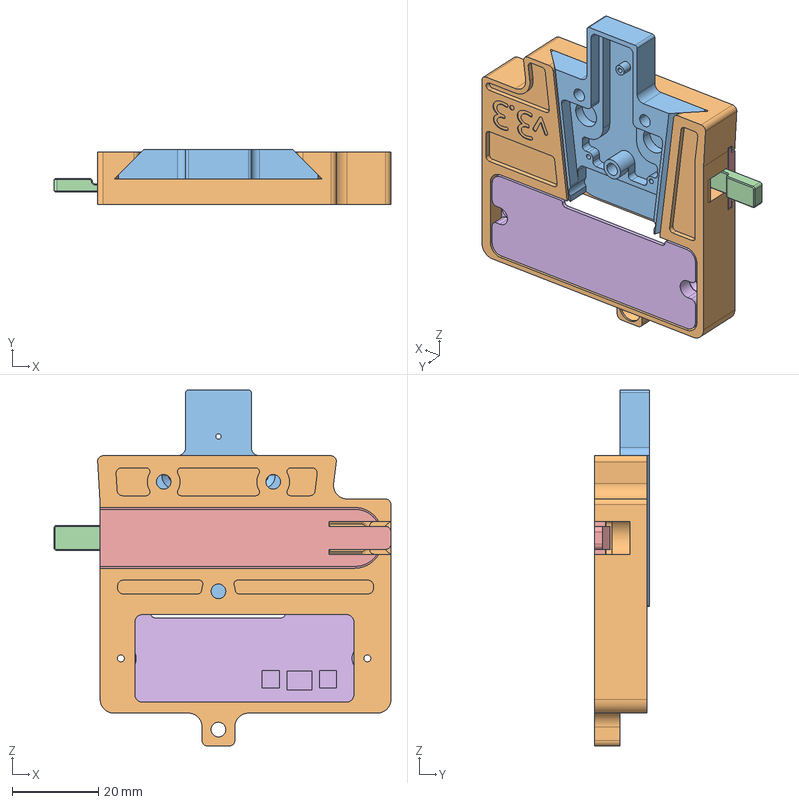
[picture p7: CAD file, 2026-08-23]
sUPI Mechanicals/19200_13122513_asm_v3-3.stp
78.1 x 12.7 x 82.5 mm

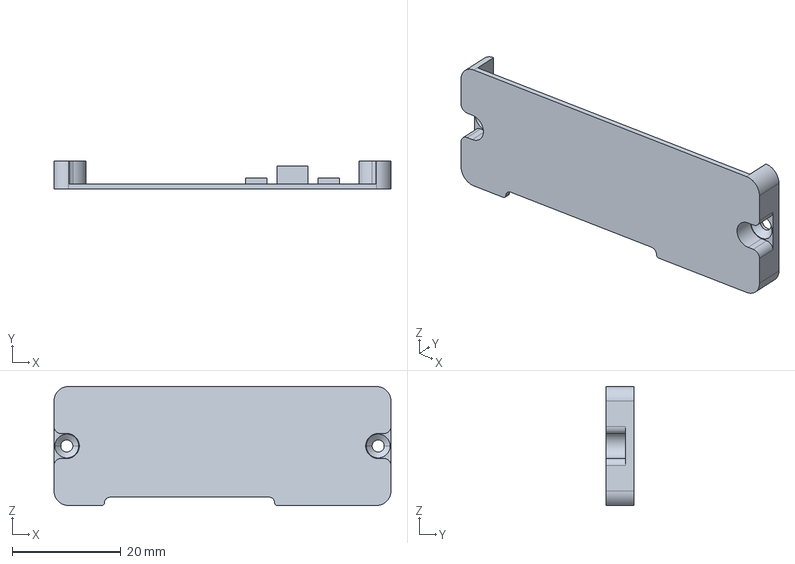
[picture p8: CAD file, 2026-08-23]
sUPI Mechanicals/19200_13122517_v3-3.stp
61.8 x 5.18 x 21.8 mm

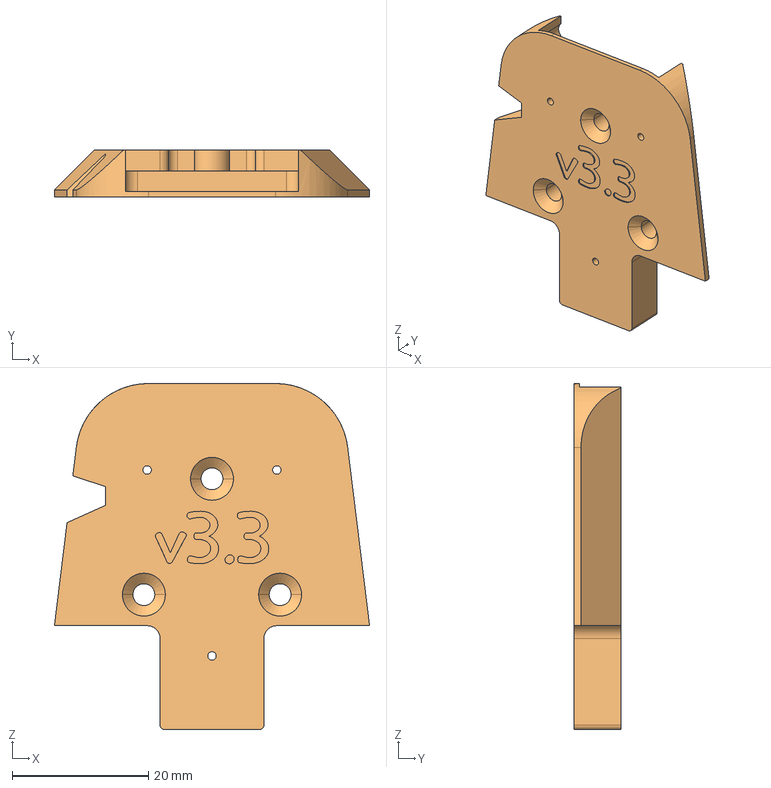
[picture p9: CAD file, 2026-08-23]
sUPI Mechanicals/19200_13122518_v3-3.stp
46.3 x 6.86 x 50.8 mm

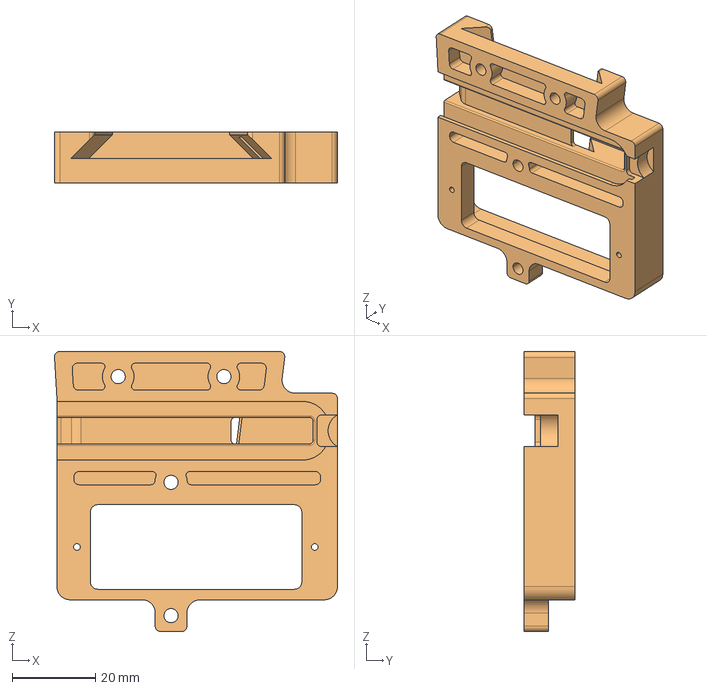
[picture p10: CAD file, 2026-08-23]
sUPI Mechanicals/19200_13122514_v3-3.stp
68.0 x 12.2 x 67.3 mm

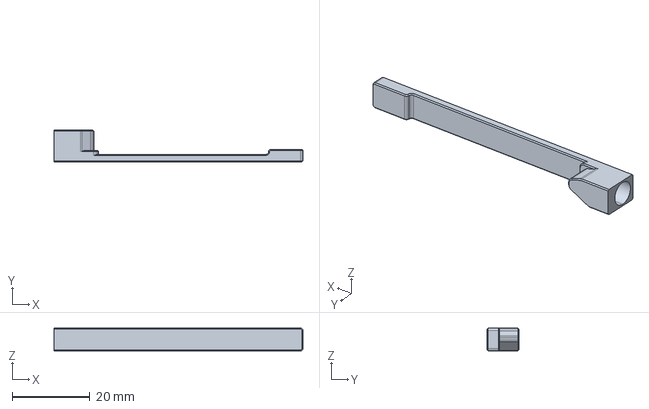
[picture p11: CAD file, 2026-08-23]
sUPI Mechanicals/19200_13122515_v3-3.stp
64.0 x 8.10 x 5.84 mm

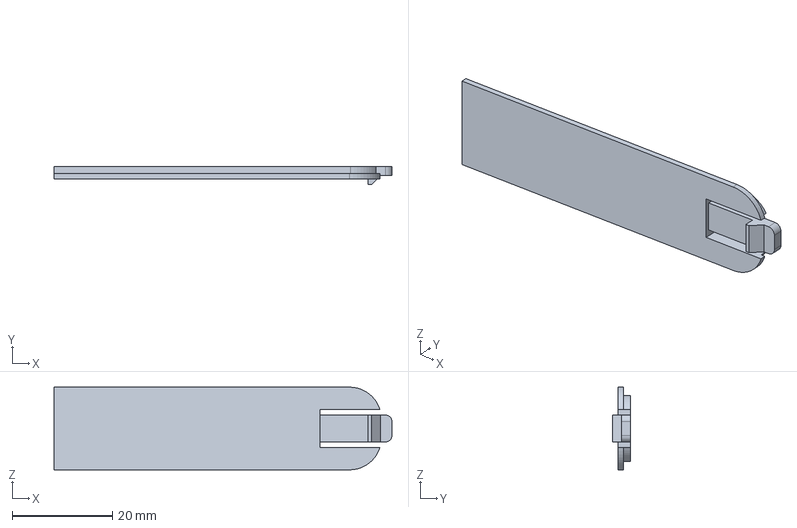
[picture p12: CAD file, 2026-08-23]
sUPI Mechanicals/19200_13122516_v3-3.stp
67.4 x 3.62 x 16.5 mm

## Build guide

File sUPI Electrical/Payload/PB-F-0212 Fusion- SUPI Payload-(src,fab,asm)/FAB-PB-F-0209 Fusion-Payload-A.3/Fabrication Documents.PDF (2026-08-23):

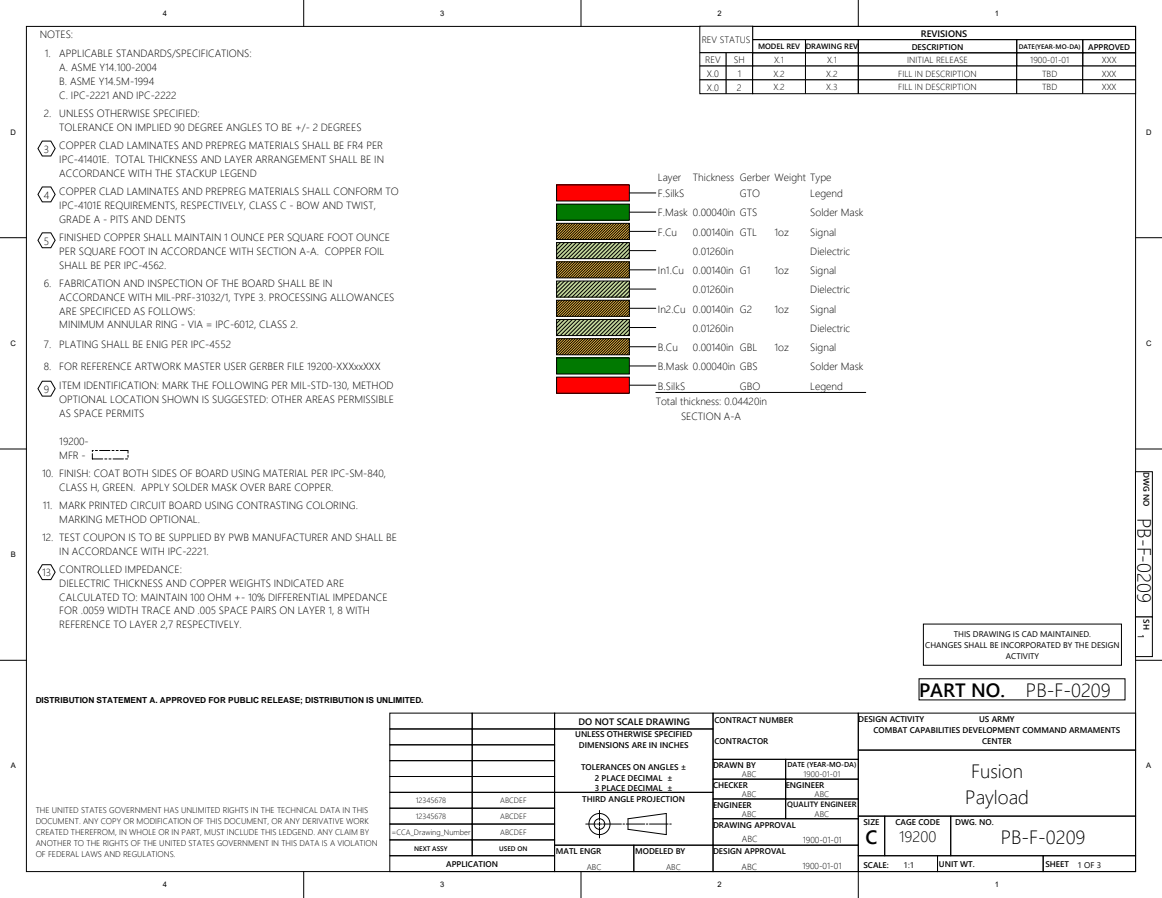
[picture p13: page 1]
F.SilkS; GTO; Legend; F.Mask 0.00040in GTS; Solder Mask; F.Cu 0.00140in GTL; Signal; Dielectric; B.Cu 0.00140in GBL; B.Mask 0.00040in GBS; B.SilkS; GBO; ABC; MATL ENGR; MODELED BY; DRAWN BY; DRAWING APPROVAL; DESIGN APPROVAL; CONTRACT NUMBER; CONTRACTOR; CHECKER; ENGINEER; DATE (YEAR-MO-DA); QUALITY ENGINEER; 1900-01-01 ENGINEER ABC; ABCDEF; THIRD ANGLE PROJECTION; APPLICATION; DRAWING REV; DESCRIPTION; DATE(YEAR-MO-DA) APPROVED; REVISIONS; =CCA_Drawing_Number; ACTIVITY; CAGE CODE; SIZE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

NOTES:
APPLICABLE STANDARDS/SPECIFICATIONS:
A. ASME Y14.100-2004
B. ASME Y14.5M-1994
C. IPC-2221 AND IPC-2222
UNLESS OTHERWISE SPECIFIED:
TOLERANCE ON IMPLIED 90 DEGREE ANGLES TO BE +/- 2 DEGREES
COPPER CLAD LAMINATES AND PREPREG MATERIALS SHALL BE FR4 PER
IPC-41401E. TOTAL THICKNESS AND LAYER ARRANGEMENT SHALL BE IN
ACCORDANCE WITH THE STACKUP LEGEND
COPPER CLAD LAMINATES AND PREPREG MATERIALS SHALL CONFORM TO
IPC-4101E REQUIREMENTS, RESPECTIVELY, CLASS C - BOW AND TWIST,
GRADE A - PITS AND DENTS
FINISHED COPPER SHALL MAINTAIN 1 OUNCE PER SQUARE FOOT OUNCE
PER SQUARE FOOT IN ACCORDANCE WITH SECTION A-A. COPPER FOIL
SHALL BE PER IPC-4562.
FABRICATION AND INSPECTION OF THE BOARD SHALL BE IN
ACCORDANCE WITH MIL-PRF-31032/1, TYPE 3. PROCESSING ALLOWANCES
ARE SPECIFICED AS FOLLOWS:
MINIMUM ANNULAR RING - VIA = IPC-6012, CLASS 2.
7. PLATING SHALL BE ENIG PER IPC-4552
8. FOR REFERENCE ARTWORK MASTER USER GERBER FILE 19200-XXXxxXXX
ITEM IDENTIFICATION: MARK THE FOLLOWING PER MIL-STD-130, METHOD
OPTIONAL LOCATION SHOWN IS SUGGESTED: OTHER AREAS PERMISSIBLE
AS SPACE PERMITS

FILL IN DESCRIPTION

Layer Thickness Gerber Weight Type
Total thickness: 0.04420in
SECTION A-A

MFR -
FINISH: COAT BOTH SIDES OF BOARD USING MATERIAL PER IPC-SM-840,
CLASS H, GREEN. APPLY SOLDER MASK OVER BARE COPPER.
MARK PRINTED CIRCUIT BOARD USING CONTRASTING COLORING.
MARKING METHOD OPTIONAL.
TEST COUPON IS TO BE SUPPLIED BY PWB MANUFACTURER AND SHALL BE
IN ACCORDANCE WITH IPC-2221.
CONTROLLED IMPEDANCE:
DIELECTRIC THICKNESS AND COPPER WEIGHTS INDICATED ARE
CALCULATED TO: MAINTAIN 100 OHM +- 10% DIFFERENTIAL IMPEDANCE
FOR .0059 WIDTH TRACE AND .005 SPACE PAIRS ON LAYER 1, 8 WITH
REFERENCE TO LAYER 2,7 RESPECTIVELY.

1 DWG NO PB-F-0209 SH

THIS DRAWING IS CAD MAINTAINED.
CHANGES SHALL BE INCORPORATED BY THE DESIGN
PART NO. PB-F-0209

DISTRIBUTION STATEMENT A. APPROVED FOR PUBLIC RELEASE; DISTRIBUTION IS UNLIMITED.

UNLESS OTHERWISE SPECIFIED
DIMENSIONS ARE IN INCHES

DESIGN ACTIVITY
COMBAT CAPABILITIES DEVELOPMENT COMMAND ARMAMENTS

TOLERANCES ON ANGLES ±
2 PLACE DECIMAL ±
3 PLACE DECIMAL ±

THE UNITED STATES GOVERNMENT HAS UNLIMITED RIGHTS IN THE TECHNICAL DATA IN THIS
DOCUMENT. ANY COPY OR MODIFICATION OF THIS DOCUMENT, OR ANY DERIVATIVE WORK
CREATED THEREFROM, IN WHOLE OR IN PART, MUST INCLUDE THIS LEDGEND. ANY CLAIM BY
ANOTHER TO THE RIGHTS OF THE UNITED STATES GOVERNMENT IN THIS DATA IS A VIOLATION
OF FEDERAL LAWS AND REGULATIONS.

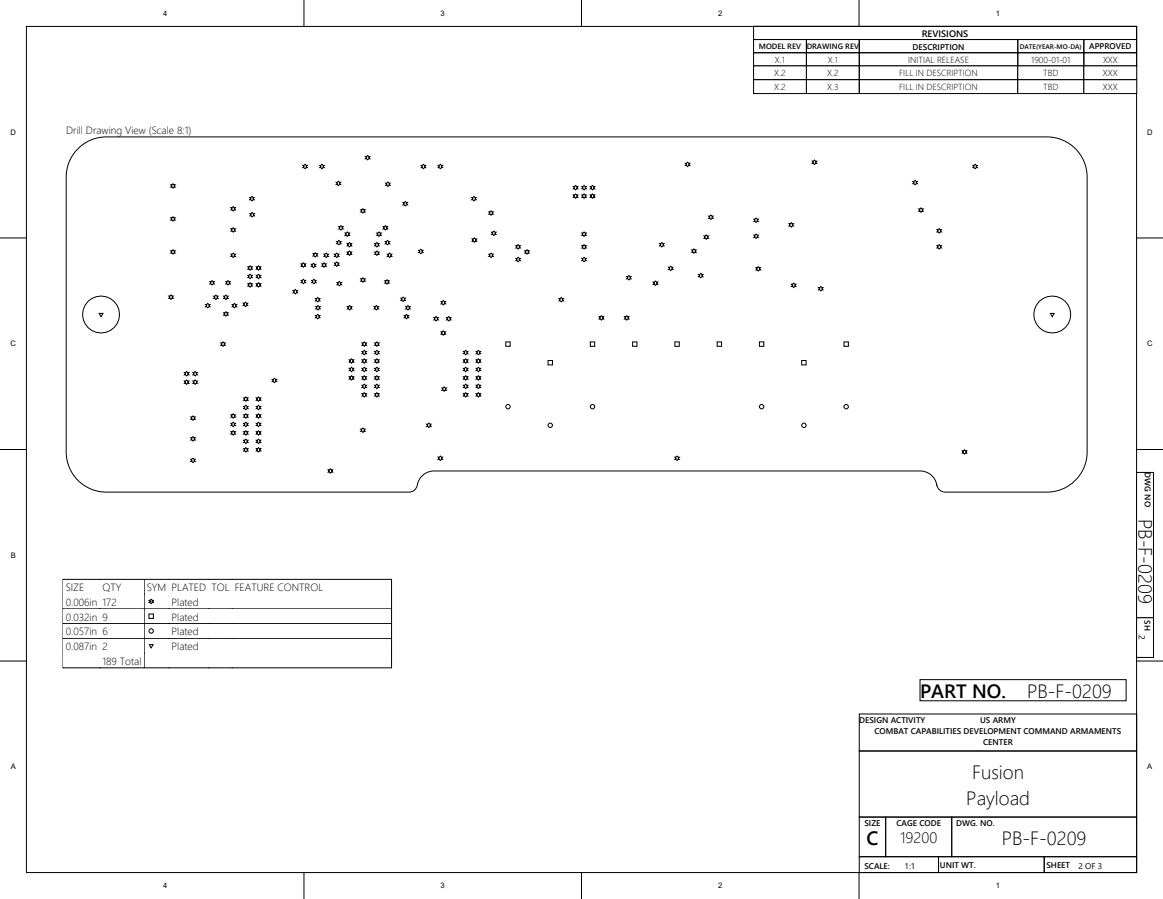
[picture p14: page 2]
DWG. NO.; US ARMY; CENTER Fusion Payload; SIZE; CAGE CODE; TBD; XXX

FILL IN DESCRIPTION

Drill Drawing View (Scale 8:1)

2 DWG NO PB-F-0209 SH

SIZE | QTY | SYM | PLATED | TOL | FEATURE CONTROL
0.006in | 172 | | Plated
0.032in | 9 | | | | Plated
0.057in | 6 | | | | Plated
0.087in | 2 | | | | Plated
189 Total

PART NO. PB-F-0209

DESIGN ACTIVITY
COMBAT CAPABILITIES DEVELOPMENT COMMAND ARMAMENTS

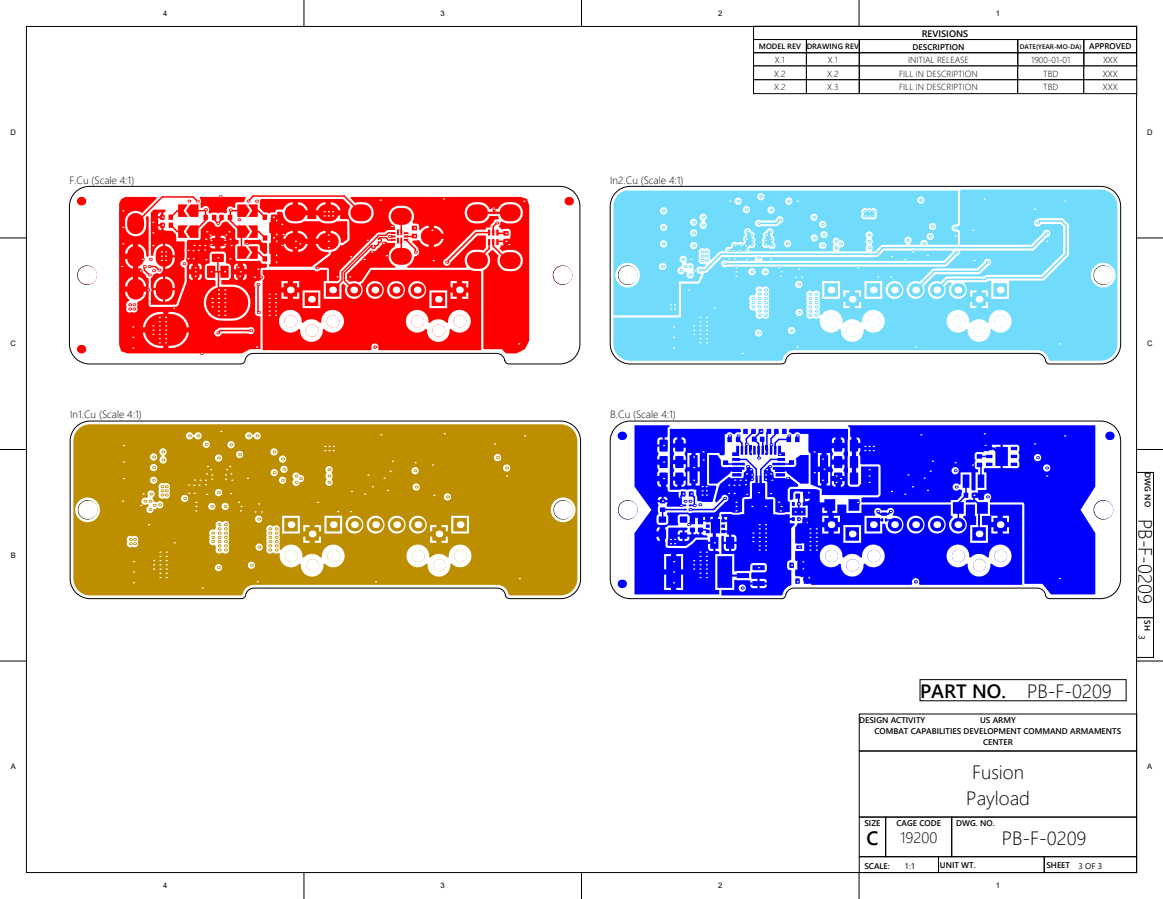
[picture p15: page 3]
B.Cu (Scale 4:1); F.Cu (Scale 4:1); In2.Cu (Scale 4:1); In1.Cu (Scale 4:1); DWG. NO.; US ARMY; CENTER Fusion Payload; SIZE; CAGE CODE; TBD; XXX

FILL IN DESCRIPTION

3 DWG NO PB-F-0209 SH

PART NO. PB-F-0209

DESIGN ACTIVITY
COMBAT CAPABILITIES DEVELOPMENT COMMAND ARMAMENTS

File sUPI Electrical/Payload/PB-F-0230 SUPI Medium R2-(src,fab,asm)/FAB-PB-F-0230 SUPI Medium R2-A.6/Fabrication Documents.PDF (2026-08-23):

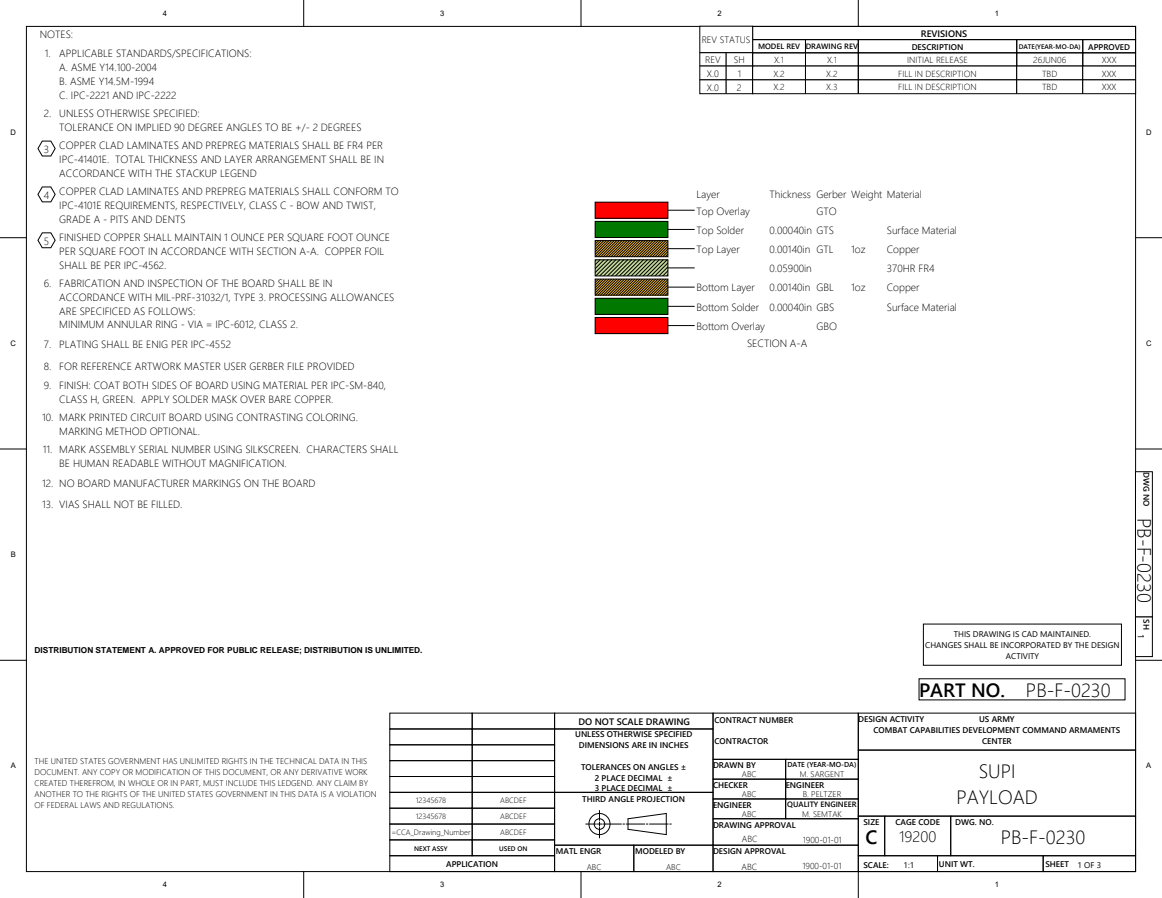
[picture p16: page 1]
Layer; Thickness Gerber Weight Material; Top Overlay; GTO; Top Solder; 0.00040in GTS; Surface Material; Top Layer; 0.00140in GTL; Copper; Bottom Layer 0.00140in GBL; Bottom Solder 0.00040in GBS; Bottom Overlay; GBO; SECTION A-A; ABC; MATL ENGR; MODELED BY; DRAWN BY; DRAWING APPROVAL; DESIGN APPROVAL; CONTRACT NUMBER; CONTRACTOR; CHECKER; ENGINEER; DATE (YEAR-MO-DA); QUALITY ENGINEER; M. SARGENT ENGINEER B. PELTZER; M. SEMTAK; ABCDEF; THIRD ANGLE PROJECTION; APPLICATION; 26JUN06; DRAWING REV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

NOTES:
APPLICABLE STANDARDS/SPECIFICATIONS:
A. ASME Y14.100-2004
B. ASME Y14.5M-1994
C. IPC-2221 AND IPC-2222
UNLESS OTHERWISE SPECIFIED:
TOLERANCE ON IMPLIED 90 DEGREE ANGLES TO BE +/- 2 DEGREES
COPPER CLAD LAMINATES AND PREPREG MATERIALS SHALL BE FR4 PER
IPC-41401E. TOTAL THICKNESS AND LAYER ARRANGEMENT SHALL BE IN
ACCORDANCE WITH THE STACKUP LEGEND
COPPER CLAD LAMINATES AND PREPREG MATERIALS SHALL CONFORM TO
IPC-4101E REQUIREMENTS, RESPECTIVELY, CLASS C - BOW AND TWIST,
GRADE A - PITS AND DENTS
FINISHED COPPER SHALL MAINTAIN 1 OUNCE PER SQUARE FOOT OUNCE
PER SQUARE FOOT IN ACCORDANCE WITH SECTION A-A. COPPER FOIL
SHALL BE PER IPC-4562.
FABRICATION AND INSPECTION OF THE BOARD SHALL BE IN
ACCORDANCE WITH MIL-PRF-31032/1, TYPE 3. PROCESSING ALLOWANCES
ARE SPECIFICED AS FOLLOWS:
MINIMUM ANNULAR RING - VIA = IPC-6012, CLASS 2.
7. PLATING SHALL BE ENIG PER IPC-4552
8. FOR REFERENCE ARTWORK MASTER USER GERBER FILE PROVIDED
FINISH: COAT BOTH SIDES OF BOARD USING MATERIAL PER IPC-SM-840,
CLASS H, GREEN. APPLY SOLDER MASK OVER BARE COPPER.
MARK PRINTED CIRCUIT BOARD USING CONTRASTING COLORING.
MARKING METHOD OPTIONAL.
MARK ASSEMBLY SERIAL NUMBER USING SILKSCREEN. CHARACTERS SHALL
BE HUMAN READABLE WITHOUT MAGNIFICATION.
12. NO BOARD MANUFACTURER MARKINGS ON THE BOARD
13. VIAS SHALL NOT BE FILLED.

FILL IN DESCRIPTION

1 DWG NO PB-F-0230 SH

THIS DRAWING IS CAD MAINTAINED.
CHANGES SHALL BE INCORPORATED BY THE DESIGN
PART NO. PB-F-0230

DISTRIBUTION STATEMENT A. APPROVED FOR PUBLIC RELEASE; DISTRIBUTION IS UNLIMITED.

UNLESS OTHERWISE SPECIFIED
DIMENSIONS ARE IN INCHES

DESIGN ACTIVITY
COMBAT CAPABILITIES DEVELOPMENT COMMAND ARMAMENTS

THE UNITED STATES GOVERNMENT HAS UNLIMITED RIGHTS IN THE TECHNICAL DATA IN THIS
DOCUMENT. ANY COPY OR MODIFICATION OF THIS DOCUMENT, OR ANY DERIVATIVE WORK
CREATED THEREFROM, IN WHOLE OR IN PART, MUST INCLUDE THIS LEDGEND. ANY CLAIM BY
ANOTHER TO THE RIGHTS OF THE UNITED STATES GOVERNMENT IN THIS DATA IS A VIOLATION
OF FEDERAL LAWS AND REGULATIONS.

TOLERANCES ON ANGLES ±
2 PLACE DECIMAL ±
3 PLACE DECIMAL ±

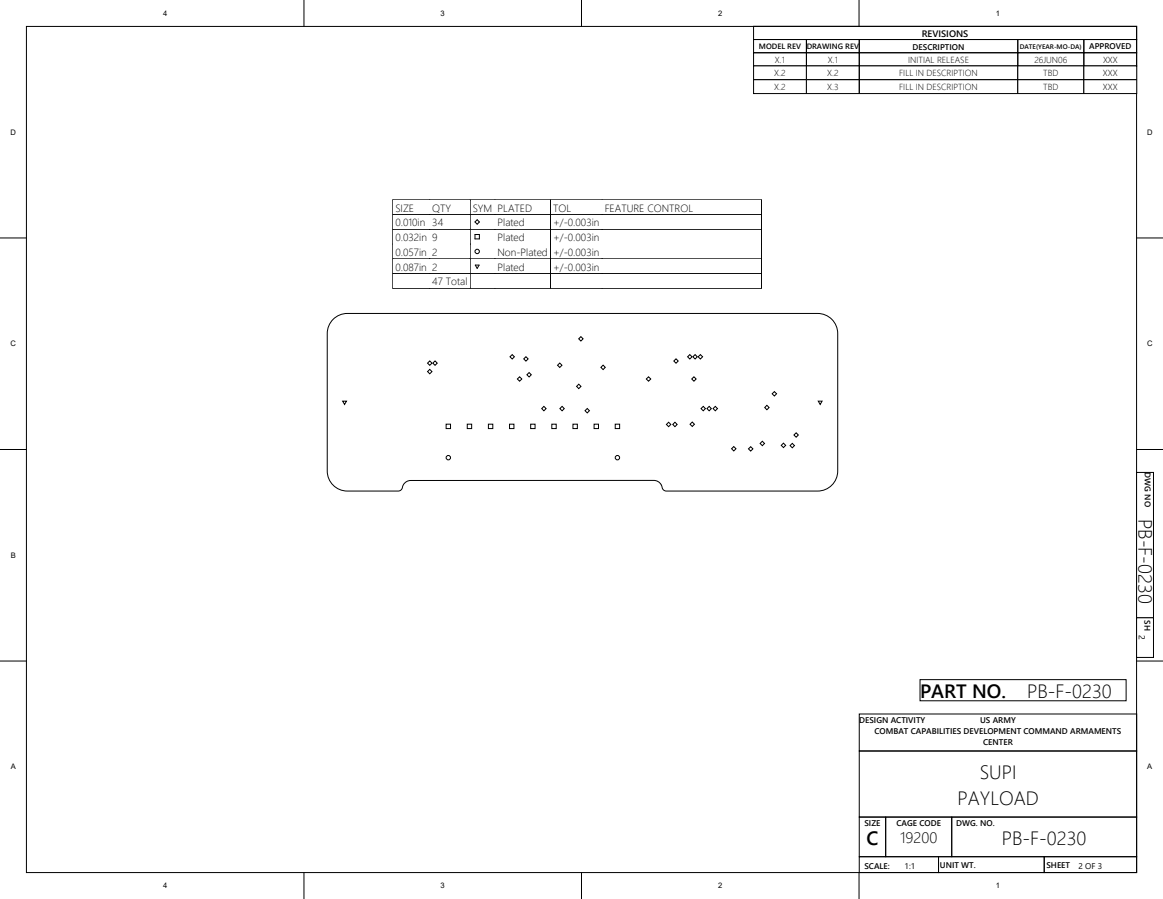
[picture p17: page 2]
DWG. NO.; US ARMY; CENTER SUPI PAYLOAD; SIZE; CAGE CODE; TBD; XXX

FILL IN DESCRIPTION

SIZE | QTY | SYM | PLATED | TOL | FEATURE CONTROL
0.010in | 34 | | Plated | +/-0.003in
0.032in | 9 | | | | Plated | +/-0.003in
0.057in | 2 | | | | Non-Plated | +/-0.003in
0.087in | 2 | | | | Plated | +/-0.003in
47 Total

2 DWG NO PB-F-0230 SH

PART NO. PB-F-0230

DESIGN ACTIVITY
COMBAT CAPABILITIES DEVELOPMENT COMMAND ARMAMENTS

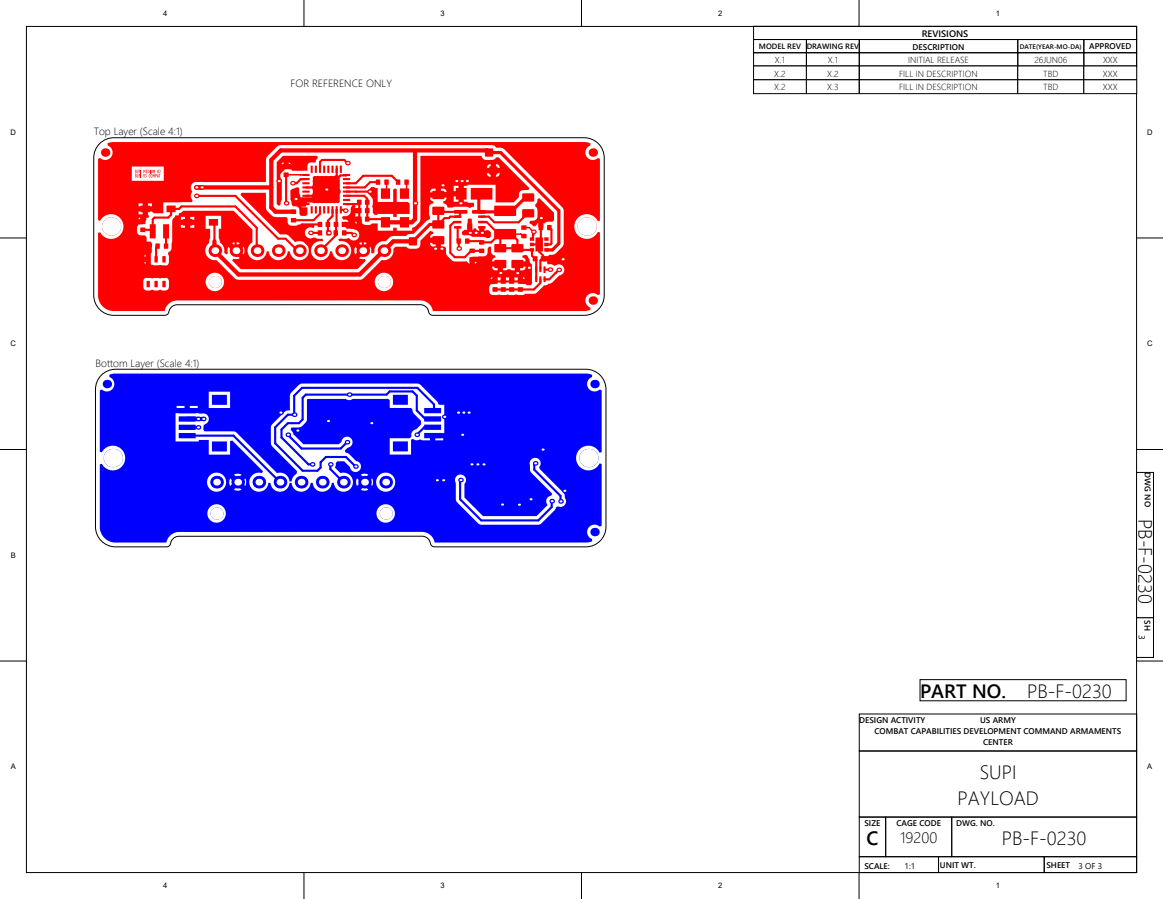
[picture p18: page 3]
DWG. NO.; US ARMY; CENTER SUPI PAYLOAD; SIZE; CAGE CODE; TBD; XXX

FOR REFERENCE ONLY

FILL IN DESCRIPTION

Top Layer (Scale 4:1)

Bottom Layer (Scale 4:1)

3 DWG NO PB-F-0230 SH

PART NO. PB-F-0230

DESIGN ACTIVITY
COMBAT CAPABILITIES DEVELOPMENT COMMAND ARMAMENTS

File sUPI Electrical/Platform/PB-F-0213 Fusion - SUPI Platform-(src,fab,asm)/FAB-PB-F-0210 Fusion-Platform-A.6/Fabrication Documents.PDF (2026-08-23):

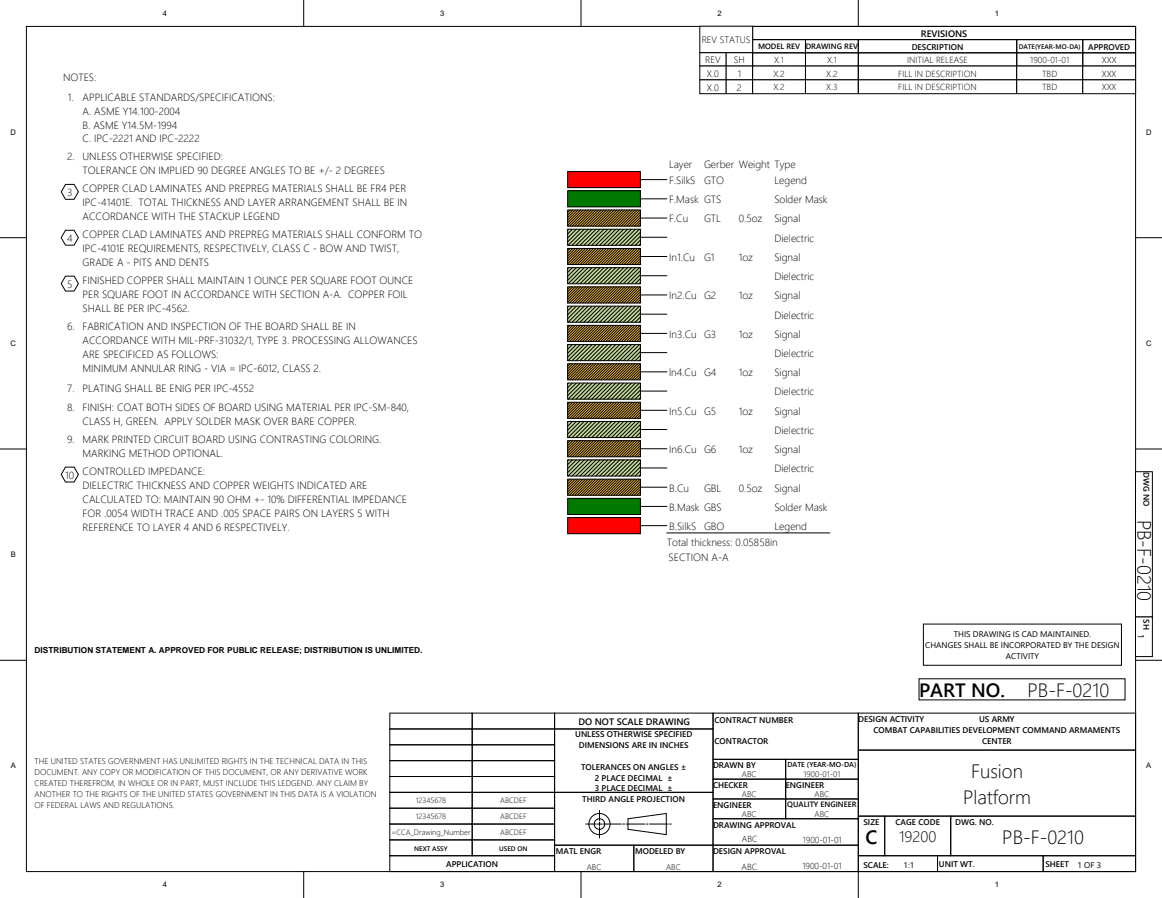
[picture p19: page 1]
F.SilkS GTO; Legend; F.Mask GTS; Solder Mask; F.Cu GTL; 0.5oz Signal; Dielectric; Signal; B.Cu GBL; B.Mask GBS; B.SilkS GBO; Total thickness: 0.05858in SECTION A-A; ABC; MATL ENGR; MODELED BY; DRAWN BY; DRAWING APPROVAL; DESIGN APPROVAL; CONTRACT NUMBER; CONTRACTOR; CHECKER; ENGINEER; DATE (YEAR-MO-DA); QUALITY ENGINEER; 1900-01-01 ENGINEER ABC; ABCDEF; THIRD ANGLE PROJECTION; APPLICATION; DRAWING REV; DESCRIPTION; DATE(YEAR-MO-DA) APPROVED; REVISIONS; =CCA_Drawing_Number; ACTIVITY; CAGE CODE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

FILL IN DESCRIPTION

NOTES:
APPLICABLE STANDARDS/SPECIFICATIONS:
A. ASME Y14.100-2004
B. ASME Y14.5M-1994
C. IPC-2221 AND IPC-2222
UNLESS OTHERWISE SPECIFIED:
TOLERANCE ON IMPLIED 90 DEGREE ANGLES TO BE +/- 2 DEGREES
COPPER CLAD LAMINATES AND PREPREG MATERIALS SHALL BE FR4 PER
IPC-41401E. TOTAL THICKNESS AND LAYER ARRANGEMENT SHALL BE IN
ACCORDANCE WITH THE STACKUP LEGEND
COPPER CLAD LAMINATES AND PREPREG MATERIALS SHALL CONFORM TO
IPC-4101E REQUIREMENTS, RESPECTIVELY, CLASS C - BOW AND TWIST,
GRADE A - PITS AND DENTS
FINISHED COPPER SHALL MAINTAIN 1 OUNCE PER SQUARE FOOT OUNCE
PER SQUARE FOOT IN ACCORDANCE WITH SECTION A-A. COPPER FOIL
SHALL BE PER IPC-4562.
FABRICATION AND INSPECTION OF THE BOARD SHALL BE IN
ACCORDANCE WITH MIL-PRF-31032/1, TYPE 3. PROCESSING ALLOWANCES
ARE SPECIFICED AS FOLLOWS:
MINIMUM ANNULAR RING - VIA = IPC-6012, CLASS 2.
7. PLATING SHALL BE ENIG PER IPC-4552
FINISH: COAT BOTH SIDES OF BOARD USING MATERIAL PER IPC-SM-840,
CLASS H, GREEN. APPLY SOLDER MASK OVER BARE COPPER.
MARK PRINTED CIRCUIT BOARD USING CONTRASTING COLORING.
MARKING METHOD OPTIONAL.
CONTROLLED IMPEDANCE:
DIELECTRIC THICKNESS AND COPPER WEIGHTS INDICATED ARE
CALCULATED TO: MAINTAIN 90 OHM +- 10% DIFFERENTIAL IMPEDANCE
FOR .0054 WIDTH TRACE AND .005 SPACE PAIRS ON LAYERS 5 WITH
REFERENCE TO LAYER 4 AND 6 RESPECTIVELY.

Layer Gerber Weight Type

1 DWG NO PB-F-0210 SH

THIS DRAWING IS CAD MAINTAINED.
CHANGES SHALL BE INCORPORATED BY THE DESIGN
PART NO. PB-F-0210

DISTRIBUTION STATEMENT A. APPROVED FOR PUBLIC RELEASE; DISTRIBUTION IS UNLIMITED.

UNLESS OTHERWISE SPECIFIED
DIMENSIONS ARE IN INCHES

DESIGN ACTIVITY
COMBAT CAPABILITIES DEVELOPMENT COMMAND ARMAMENTS

THE UNITED STATES GOVERNMENT HAS UNLIMITED RIGHTS IN THE TECHNICAL DATA IN THIS
DOCUMENT. ANY COPY OR MODIFICATION OF THIS DOCUMENT, OR ANY DERIVATIVE WORK
CREATED THEREFROM, IN WHOLE OR IN PART, MUST INCLUDE THIS LEDGEND. ANY CLAIM BY
ANOTHER TO THE RIGHTS OF THE UNITED STATES GOVERNMENT IN THIS DATA IS A VIOLATION
OF FEDERAL LAWS AND REGULATIONS.

TOLERANCES ON ANGLES ±
2 PLACE DECIMAL ±
3 PLACE DECIMAL ±

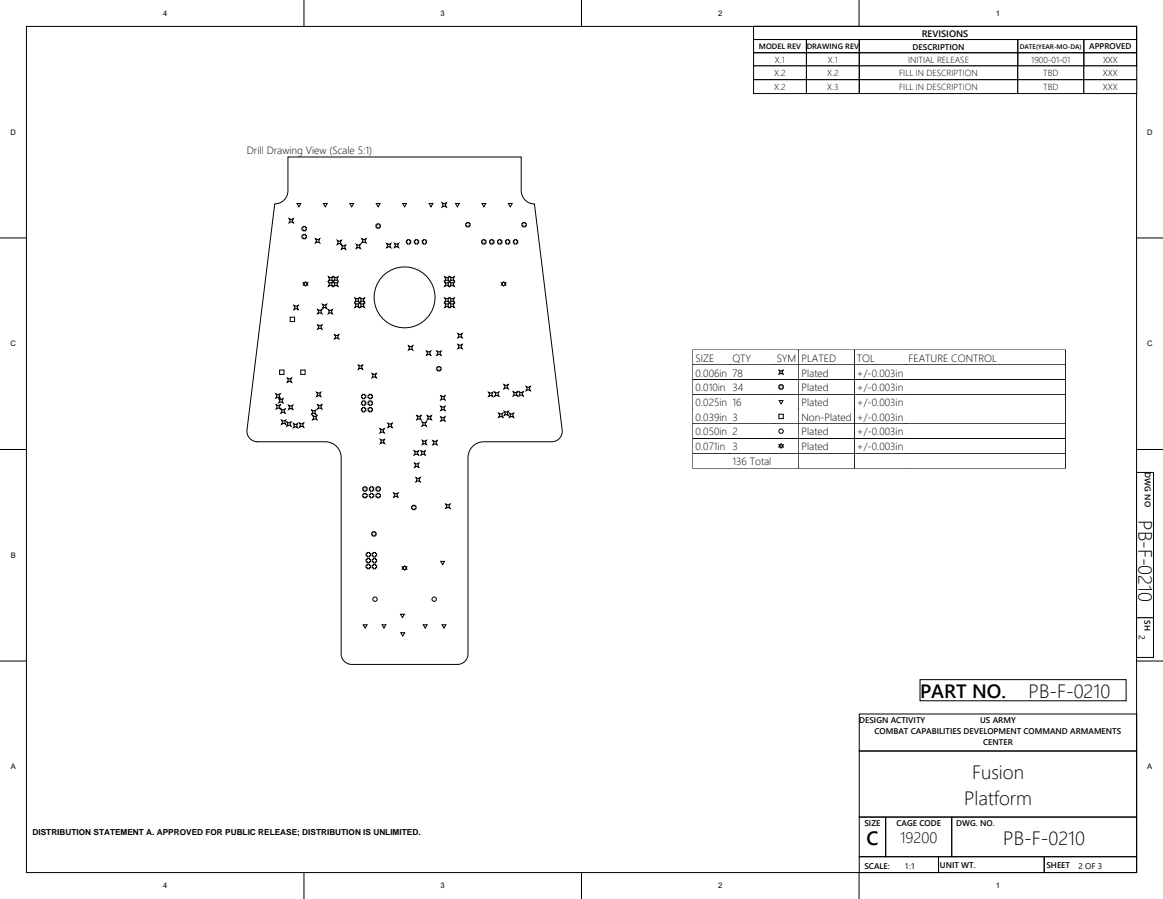
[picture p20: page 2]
DWG. NO.; US ARMY; CENTER Fusion Platform; SIZE; CAGE CODE; TBD; XXX

FILL IN DESCRIPTION

Drill Drawing View (Scale 5:1)

SIZE | QTY | SYM | PLATED | TOL | FEATURE CONTROL
0.006in | 78 | | Plated | +/-0.003in
0.010in | 34 | | Plated | +/-0.003in
0.025in | 16 | | Plated | +/-0.003in
0.039in | 3 | | | | Non-Plated | +/-0.003in
0.050in | 2 | | | | Plated | +/-0.003in
0.071in | 3 | | | | Plated | +/-0.003in
136 Total

2 DWG NO PB-F-0210 SH

PART NO. PB-F-0210

DESIGN ACTIVITY
COMBAT CAPABILITIES DEVELOPMENT COMMAND ARMAMENTS

DISTRIBUTION STATEMENT A. APPROVED FOR PUBLIC RELEASE; DISTRIBUTION IS UNLIMITED.

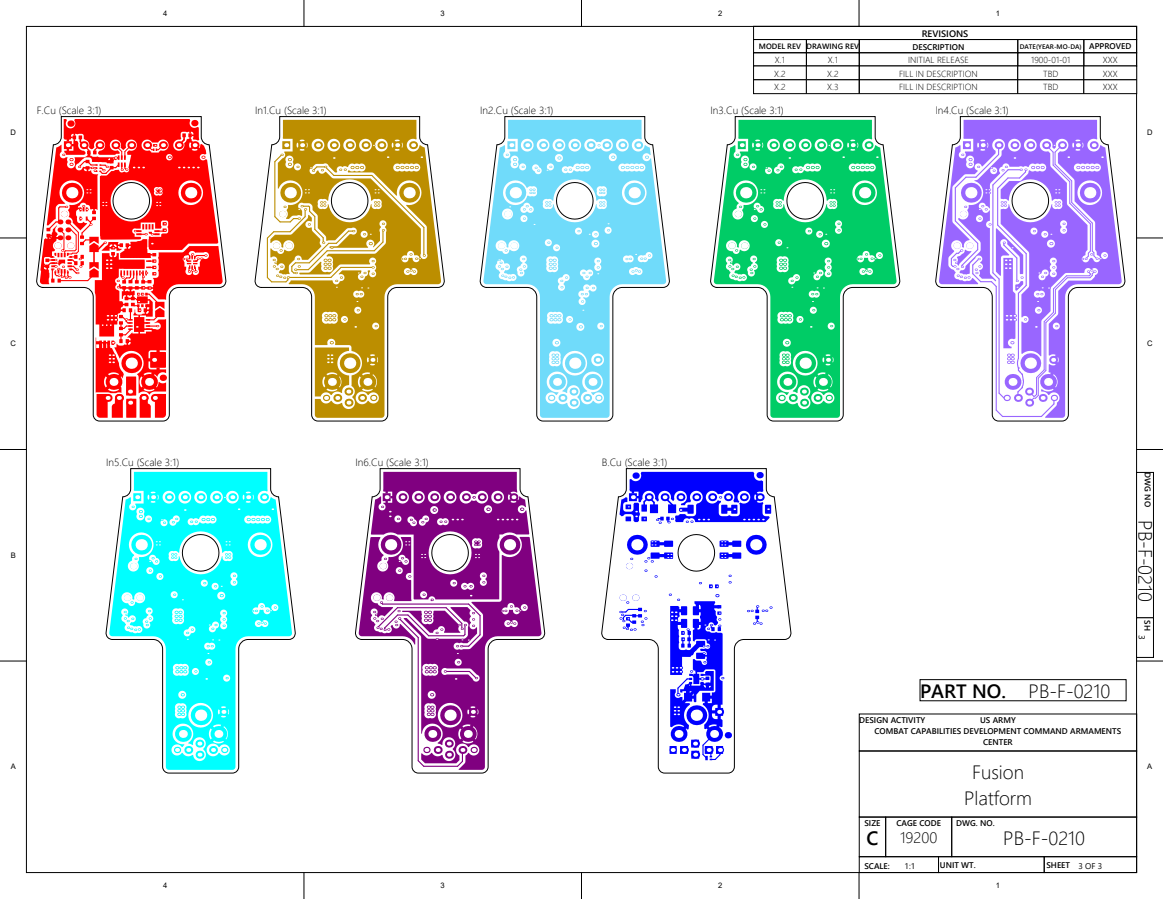
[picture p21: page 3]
B.Cu (Scale 3:1); F.Cu (Scale 3:1); In1.Cu (Scale 3:1); In2.Cu (Scale 3:1); In6.Cu (Scale 3:1); In3.Cu (Scale 3:1); ln4.Cu (Scale 3:1); In5.Cu (Scale 3:1); DWG. NO.; US ARMY; CENTER Fusion Platform; SIZE; CAGE CODE; TBD; XXX

FILL IN DESCRIPTION

3 DWG NO PB-F-0210 SH

PART NO. PB-F-0210

DESIGN ACTIVITY
COMBAT CAPABILITIES DEVELOPMENT COMMAND ARMAMENTS

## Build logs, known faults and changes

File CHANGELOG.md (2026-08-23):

# sUPI — Change Log

**Small Universal Payload Interface**

> **DISTRIBUTION STATEMENT A. APPROVED FOR PUBLIC RELEASE; DISTRIBUTION IS UNLIMITED.**

Design change history for the sUPI mechanical interface.

> **Scope.** This log covers the **mechanical** interface only. For electrical revision state, use
> each board's `A.n` assembly revision and the revision block on its fabrication drawing. The v3.3
> electrical release adds the Medium R2 payload card and re-releases all three cards with updated
> component sourcing.

---

## sUPI 3.1

| Part | Change |
| --- | --- |
| — | Initial DEVCOM AC baseline release. |

---

## sUPI 3.2

| Part | Change |
| --- | --- |
| `19200_13122514.prt` — V-Mount Base | Changed to be machinable without custom dovetail cutter. |

<table>
<tr><td align="center"><strong>Old</strong></td><td align="center"><strong>New</strong></td></tr>
<tr>
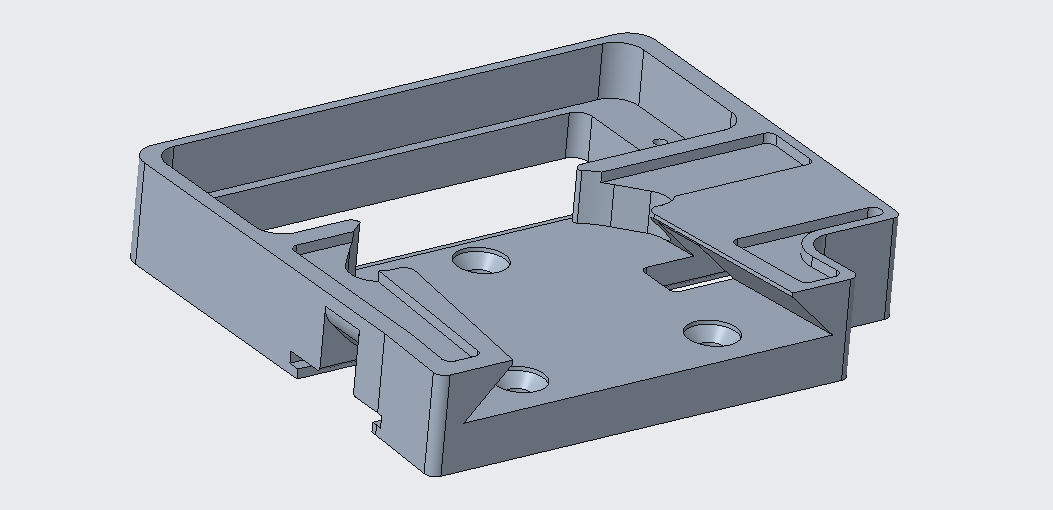
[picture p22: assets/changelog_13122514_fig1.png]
13122514 before the 3.2 change
<td></td>
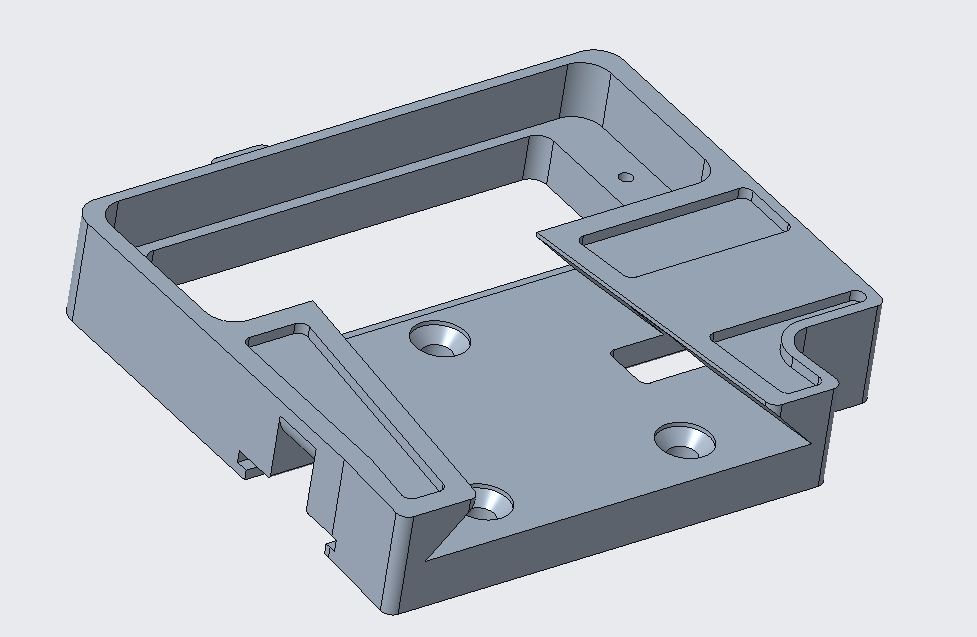
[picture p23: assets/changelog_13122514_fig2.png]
13122514 after the 3.2 change
<td></td>
</tr>
</table>

**`13122514` before and after the v3.2 change.**

---

## sUPI 3.3

Manufacturability and fit. Removes special tooling from the machining plan and takes slop out of the
mating stack. **No electrical interface changes.**

| Part | Change |
| --- | --- |
| `13122514` — V-Mount Base | Offset taper faces to eliminate play between parts. |
| `13122514` — V-Mount Base | Changed button cover slot to rounded interior to make it machinable. |
| `13122516` — Small Button Cover | Rounded button cover to match `13122514` slot round. |
| `13122515` — Short Button | Changed button geometry to make lower profile and eliminate bending. |
| `13122515` — Short Button | Changed button interfaces to eliminate play between parts. |
| Payload and platform interfaces | Added version number engraving. |

The engraving means **v3.3 hardware is physically marked.** Check the engraved version number
before mating mixed-vintage halves — earlier parts have looser fit, and earlier `13122515` buttons
have the taller profile that was prone to bending.

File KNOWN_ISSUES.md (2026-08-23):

# sUPI v3.3 — Known Issues

> **DISTRIBUTION STATEMENT A. APPROVED FOR PUBLIC RELEASE; DISTRIBUTION IS UNLIMITED.**

Errata for the v3.3 technical data package. Where a document contradicts itself, this file says
which source to trust. Report additions per `MFR_Reference_Design.md`.

---

## Read this before fabricating or machining

### Payload-side screw count

The payload brief specifies mounting via **3X** M3 screws, then directs the installer to drill and
tap **4X** holes in the same paragraph.

**Four is correct.** The hole-pattern figure shows four countersunk M3 clearance holes, and drawing
`19200_13122514` calls out 4X ⌀.134 THRU with a .248 × 90° countersink. `sUPI_Payload_Brief.md`
carries the corrected count. The platform side is genuinely 3X.

The same 3X/4X contradiction appears in Appendix A of the Picatinny CLIK Design Standard, which
inherited the text from this brief.

### Payload fabrication drawing — impedance note references layers that do not exist

`PB-F-0209` is a **4-layer** board. Note 13 on its fabrication drawing specifies controlled
impedance "on Layer 1, 8 with reference to Layer 2,7" — a callout carried from an 8-layer template.

**The 100 Ω ±10 % differential target is believed correct; the layer assignment is wrong.** Confirm
with the design activity before fabricating impedance-controlled boards.

### Mechanical drawings — stale design model in note 5

Note 5 on each detail drawing names a design model required to complete the product definition. Two
sheets name a superseded model:

| Drawing | Note 5 cites | Current model |
| --- | --- | --- |
| `19200_13122514` | `100051078` | **`100068609`** |
| `19200_13122517` | `100051078` | **`100068617`** |
| `19200_13122515` | `100064656` | correct |
| `19200_13122516` | `100051265` | correct |
| `19200_13122518` | `100064665` | correct |

Neither design model is included in this release — see
[Limits on modifying the design](#limits-on-modifying-the-design).

### Material and finish conflict on two parts

`19200_13122514` and `19200_13122517` both permit **6061-T6 aluminium or polymer powder bed fusion**
while specifying hard anodize per MIL-A-8625F, which is not applicable to polymer. `13122517`
additionally mandates additive manufacturing in note 2 while permitting aluminium in note 3.

Treat the finish requirement as conditional on choosing aluminium. Both sheets need a
material-conditional finish note.

### Bills of material are superseded by the manufacturing notes

`MFR_DNP.md` and `MFR_Rework.md` carry live direction that changes what gets populated on the
platform card. Read them before ordering assembly — see the README section *Before You Fabricate
Boards* for the effect on the delivered card. `MFR_Capacitors.md` is superseded; build from the BOM.

---

## Documentation defects

| Item | Detail |
| --- | --- |
| **Figures show V2 hardware** | The platform wiring figure shows a board silkscreened `SUPI V2` despite the actual board being V3, both hole-pattern figures are engraved `V3` rather than v3.3. |
| **Clipped figure** | The platform wiring figure is clipped in the source document — an internal caption reads `…und`, truncated from "Ground". |
| **BOM part description** | The platform BOM describes `U5` (`STM32C011F6U6TR`) as a "CORTEX-M4F CPU". The STM32C011 is **Arm Cortex-M0+**. Part number is correct; only the description is wrong. |
| **Stale project reference** | Two of the three Altium projects reference a `PCB2.PcbDoc` that is not part of the package. Opening either project reports a missing document; it is harmless and predates this release. |

---

## Limits on modifying the design

| | |
| --- | --- |
| **Mechanical parts can be manufactured, not revised.** | The release carries released drawings and STEP models. STEP is boundary-representation geometry, so revising a part requires the parametric source, which is held by the design activity along with the design models named in note 5. There is current effort to add the true design files to the repo. |
| **Circuit cards can be modified.** | The Altium projects are complete and editable: `.PrjPcb`, `.SchDoc`, `.PcbDoc`, `.SchLib`, `.BomDoc`, and the OutJob definitions that generate the fabrication and assembly outputs. A KiCad import reads these directly. |
| **The Picatinny CLIK Design Standard is held by the design activity.** | Request the current revision from them. The interface envelope summarised in the README is drawn from it. |

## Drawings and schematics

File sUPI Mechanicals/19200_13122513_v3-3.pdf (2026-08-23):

D
D

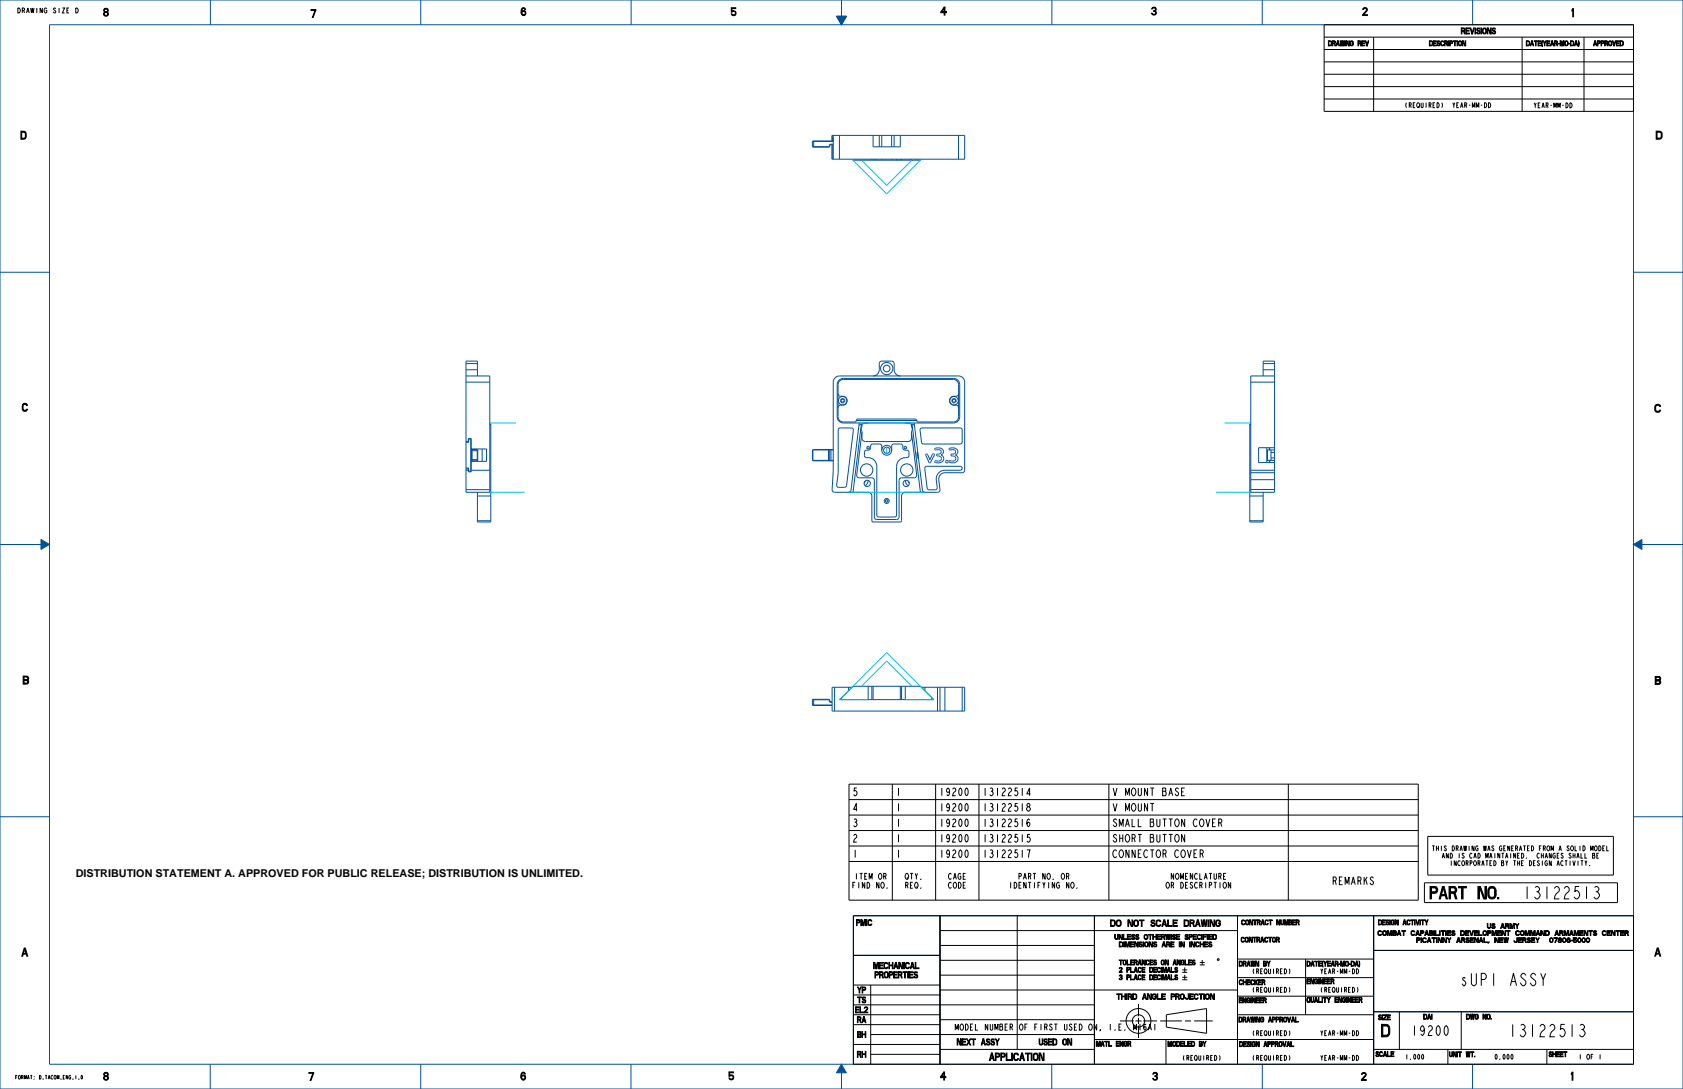
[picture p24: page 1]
DESIGN ACTIVITY; SIZE; DAI; SCALE; UNIT WT.; DRAWN; DATE(YEAR-MO-DA); CHECKER; ENGINEER; QUALITY; DRAWING APPROVAL; MATL ENGR; MODELED; DESIGN APPROVAL; CONTRACT; NUMBER; CONTRACTOR; SHEET; DRAWING SIZE D; PLACE; DECIMALS; FORMAT: D_TACOM_ENG_1_0; DWG NO.; SMALL BUTTON COVER; REVISIONS; DRAWING; REV; DESCRIPTION; APPROVED; (REQUIRED) YEAR-MM-DD; YEAR-MM-DD; sUPI ASSY; US ARMY; COMBAT; CAPABILITIES; DEVELOPMENT COMMAND; ARMAMENTS CENTER; PICATINNY ARSENAL,; NEW JERSEY 07806-5000; (REQUIRED)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

5 | 1 | 19200 | 13122514 | V MOUNT BASE
4 | 1 | 19200 | 13122518 | V MOUNT
2 | 1 | | 19200 | | 13122515 | | SHORT BUTTON
1 | | 1 | | 19200 | | 13122517 | | CONNECTOR COVER
ITEM OR FIND NO. | QTY. REQ. | CAGE CODE | PART NO. OR IDENTIFYING NO. | OR DESCRIPTION | REMARKS NOMENCLATURE

THIS DRAWING WAS GENERATED FROM A SOLID MODEL
INCORPORATED BY THE DESIGN ACTIVITY.
PART NO. 13122513

DISTRIBUTION STATEMENT A. APPROVED FOR PUBLIC RELEASE; DISTRIBUTION IS UNLIMITED.

DO NOT SCALE DRAWING
UNLESS OTHERWISE SPECIFIED
TOLERANCES ON ANGLES

(REQUIRED) | YEAR-MM-DD
(REQUIRED) | (REQUIRED)

YP
TS
EL2
RA

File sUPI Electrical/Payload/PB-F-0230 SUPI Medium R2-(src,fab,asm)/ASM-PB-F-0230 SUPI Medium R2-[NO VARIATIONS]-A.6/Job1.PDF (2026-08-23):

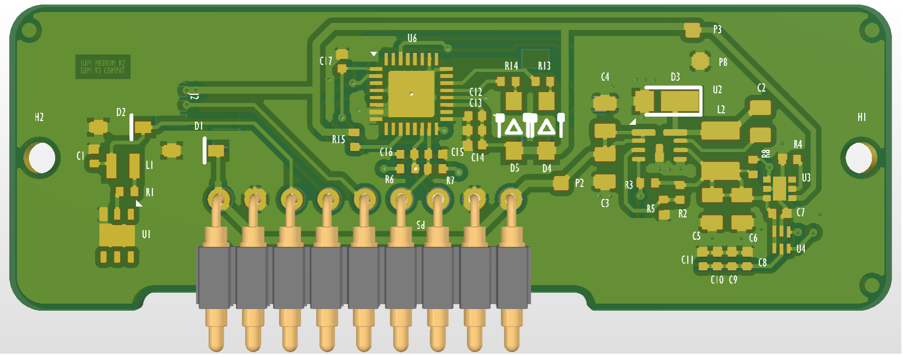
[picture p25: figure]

## 26JUN12

DRAWING REV | DESCRIPTION | DATE(YEAR-MO-DA) APPROVED

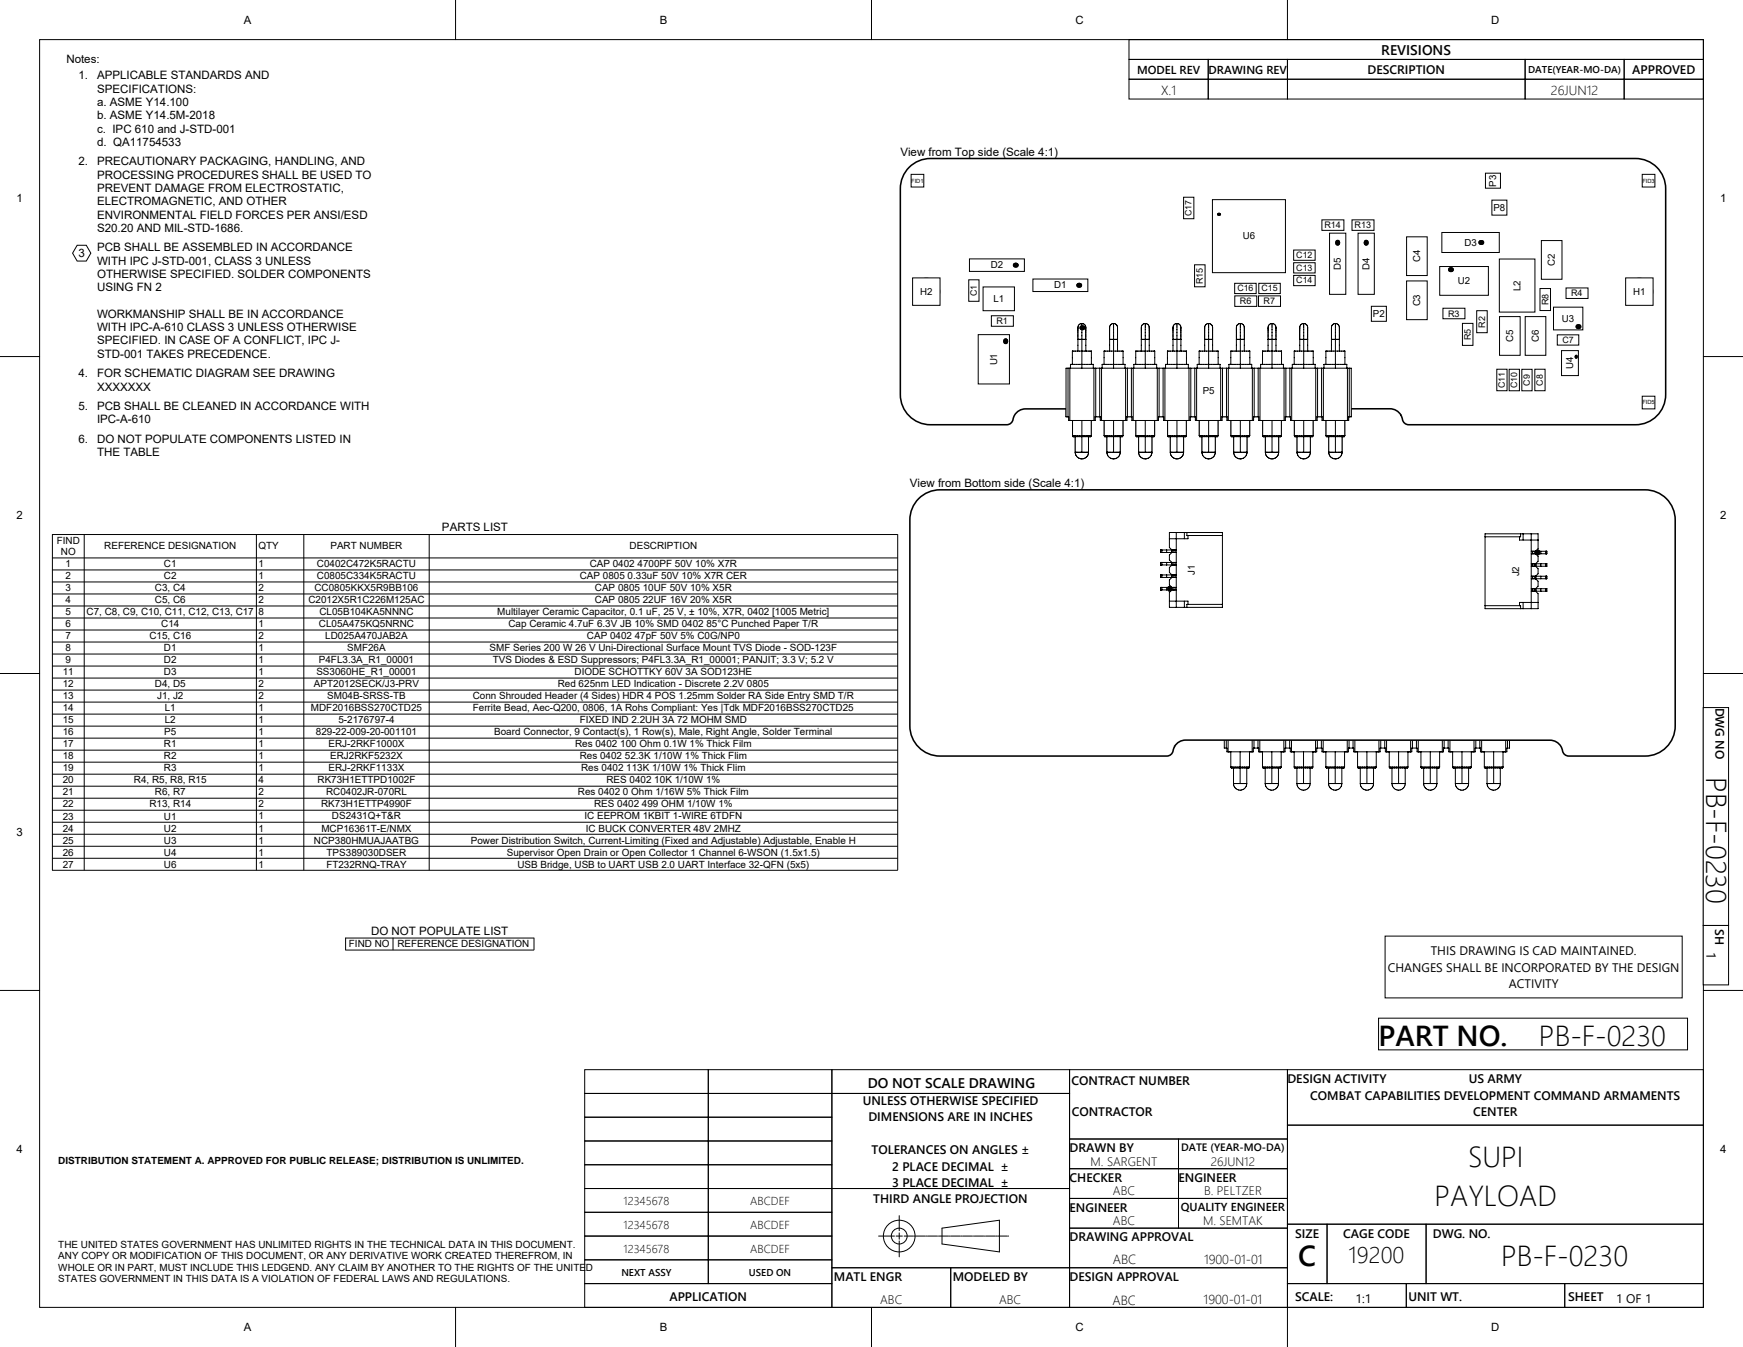
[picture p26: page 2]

Notes:
APPLICABLE STANDARDS AND
SPECIFICATIONS:
a. ASME Y14.100
b. ASME Y14.5M-2018
c. IPC 610 and J-STD-001
PRECAUTIONARY PACKAGING, HANDLING, AND
PROCESSING PROCEDURES SHALL BE USED TO
PREVENT DAMAGE FROM ELECTROSTATIC,
ELECTROMAGNETIC, AND OTHER
ENVIRONMENTAL FIELD FORCES PER ANSI/ESD
S20.20 AND MIL-STD-1686.
PCB SHALL BE ASSEMBLED IN ACCORDANCE
WITH IPC J-STD-001, CLASS 3 UNLESS
OTHERWISE SPECIFIED. SOLDER COMPONENTS
USING FN 2

View from Top side (Scale 4:1)

WORKMANSHIP SHALL BE IN ACCORDANCE
WITH IPC-A-610 CLASS 3 UNLESS OTHERWISE
SPECIFIED. IN CASE OF A CONFLICT, IPC J-
STD-001 TAKES PRECEDENCE.
FOR SCHEMATIC DIAGRAM SEE DRAWING
XXXXXXX
PCB SHALL BE CLEANED IN ACCORDANCE WITH
IPC-A-610
DO NOT POPULATE COMPONENTS LISTED IN
THE TABLE

View from Bottom side (Scale 4:1)

FIND NO | REFERENCE DESIGNATION | QTY | PART NUMBER | DESCRIPTION

1 | C1 | 1 | C0402C472K5RACTU | CAP 0402 4700PF 50V 10% X7R
2 | C2 | 1 | C0805C334K5RACTU | CAP 0805 0.33uF 50V 10% X7R CER
3 | C3, C4 | 2 | CC0805KKX5R9BB106 | CAP 0805 10UF 50V 10% X5R
4 | C5, C6 | 2 | C2012X5R1C226M125AC | CAP 0805 22UF 16V 20% X5R
5 | C7, C8, C9, C10, C11, C12, C13, C17 | 8 | CL05B104KA5NNNC | Multilayer Ceramic Capacitor, 0.1 uF, 25 V, ± 10%, X7R, 0402 [1005 Metric]
6 | C14 | 1 | CL05A475KQ5NRNC | Cap Ceramic 4.7uF 6.3V JB 10% SMD 0402 85°C Punched Paper T/R
7 | C15, C16 | 2 | LD025A470JAB2A | CAP 0402 47pF 50V 5% C0G/NP0
8 | D1 | 1 | SMF26A | SMF Series 200 W 26 V Uni-Directional Surface Mount TVS Diode - SOD-123F
9 | D2 | 1 | P4FL3.3A_R1_00001 | TVS Diodes & ESD Suppressors; P4FL3.3A_R1_00001; PANJIT; 3.3 V; 5.2 V
11 | D3 | 1 | SS3060HE_R1_00001 | DIODE SCHOTTKY 60V 3A SOD123HE
12 | D4, D5 | 2 | APT2012SECK/J3-PRV | Red 625nm LED Indication - Discrete 2.2V 0805
13 | J1, J2 | 2 | SM04B-SRSS-TB | Conn Shrouded Header (4 Sides) HDR 4 POS 1.25mm Solder RA Side Entry SMD T/R
14 | L1 | 1 | MDF2016BSS270CTD25 | Ferrite Bead, Aec-Q200, 0806, 1A Rohs Compliant: Yes |Tdk MDF2016BSS270CTD25
15 | L2 | 1 | 5-2176797-4 | FIXED IND 2.2UH 3A 72 MOHM SMD
16 | P5 | 1 | 829-22-009-20-001101 | Board Connector, 9 Contact(s), 1 Row(s), Male, Right Angle, Solder Terminal
17 | R1 | 1 | ERJ-2RKF1000X | Res 0402 100 Ohm 0.1W 1% Thick Film
18 | R2 | 1 | ERJ2RKF5232X | Res 0402 52.3K 1/10W 1% Thick Flim
19 | R3 | 1 | ERJ-2RKF1133X | Res 0402 113K 1/10W 1% Thick Flim
20 | R4, R5, R8, R15 | 4 | RK73H1ETTPD1002F | RES 0402 10K 1/10W 1%
21 | R6, R7 | 2 | RC0402JR-070RL | Res 0402 0 Ohm 1/16W 5% Thick Film
22 | R13, R14 | 2 | RK73H1ETTP4990F | RES 0402 499 OHM 1/10W 1%
23 | U1 | 1 | DS2431Q+T&R | IC EEPROM 1KBIT 1-WIRE 6TDFN
24 | U2 | 1 | MCP16361T-E/NMX | IC BUCK CONVERTER 48V 2MHZ
25 | U3 | 1 | NCP380HMUAJAATBG | Power Distribution Switch, Current-Limiting (Fixed and Adjustable) Adjustable, Enable H
26 | U4 | 1 | TPS389030DSER | Supervisor Open Drain or Open Collector 1 Channel 6-WSON (1.5x1.5)
27 | U6 | 1 | FT232RNQ-TRAY | USB Bridge, USB to UART USB 2.0 UART Interface 32-QFN (5x5)

1 DWG NO PB-F-0230 SH

DO NOT POPULATE LIST

THIS DRAWING IS CAD MAINTAINED.
CHANGES SHALL BE INCORPORATED BY THE DESIGN
PART NO. PB-F-0230

UNLESS OTHERWISE SPECIFIED
DIMENSIONS ARE IN INCHES

DESIGN ACTIVITY
COMBAT CAPABILITIES DEVELOPMENT COMMAND ARMAMENTS

DISTRIBUTION STATEMENT A. APPROVED FOR PUBLIC RELEASE; DISTRIBUTION IS UNLIMITED.

THE UNITED STATES GOVERNMENT HAS UNLIMITED RIGHTS IN THE TECHNICAL DATA IN THIS DOCUMENT.
ANY COPY OR MODIFICATION OF THIS DOCUMENT, OR ANY DERIVATIVE WORK CREATED THEREFROM, IN
WHOLE OR IN PART, MUST INCLUDE THIS LEDGEND. ANY CLAIM BY ANOTHER TO THE RIGHTS OF THE UNITED
STATES GOVERNMENT IN THIS DATA IS A VIOLATION OF FEDERAL LAWS AND REGULATIONS.

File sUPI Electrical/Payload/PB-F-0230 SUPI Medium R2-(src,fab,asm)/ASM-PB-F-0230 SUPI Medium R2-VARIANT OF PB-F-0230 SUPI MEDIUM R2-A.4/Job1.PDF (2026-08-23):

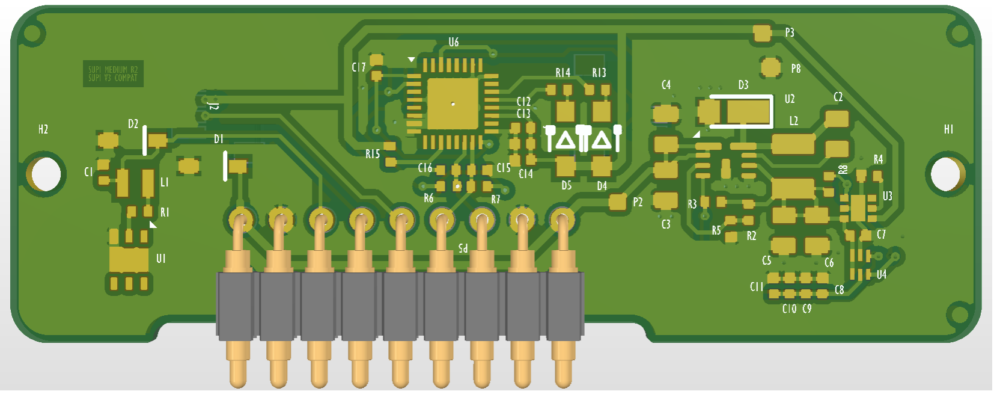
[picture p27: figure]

## 26JUN12

DRAWING REV | DESCRIPTION | DATE(YEAR-MO-DA) APPROVED

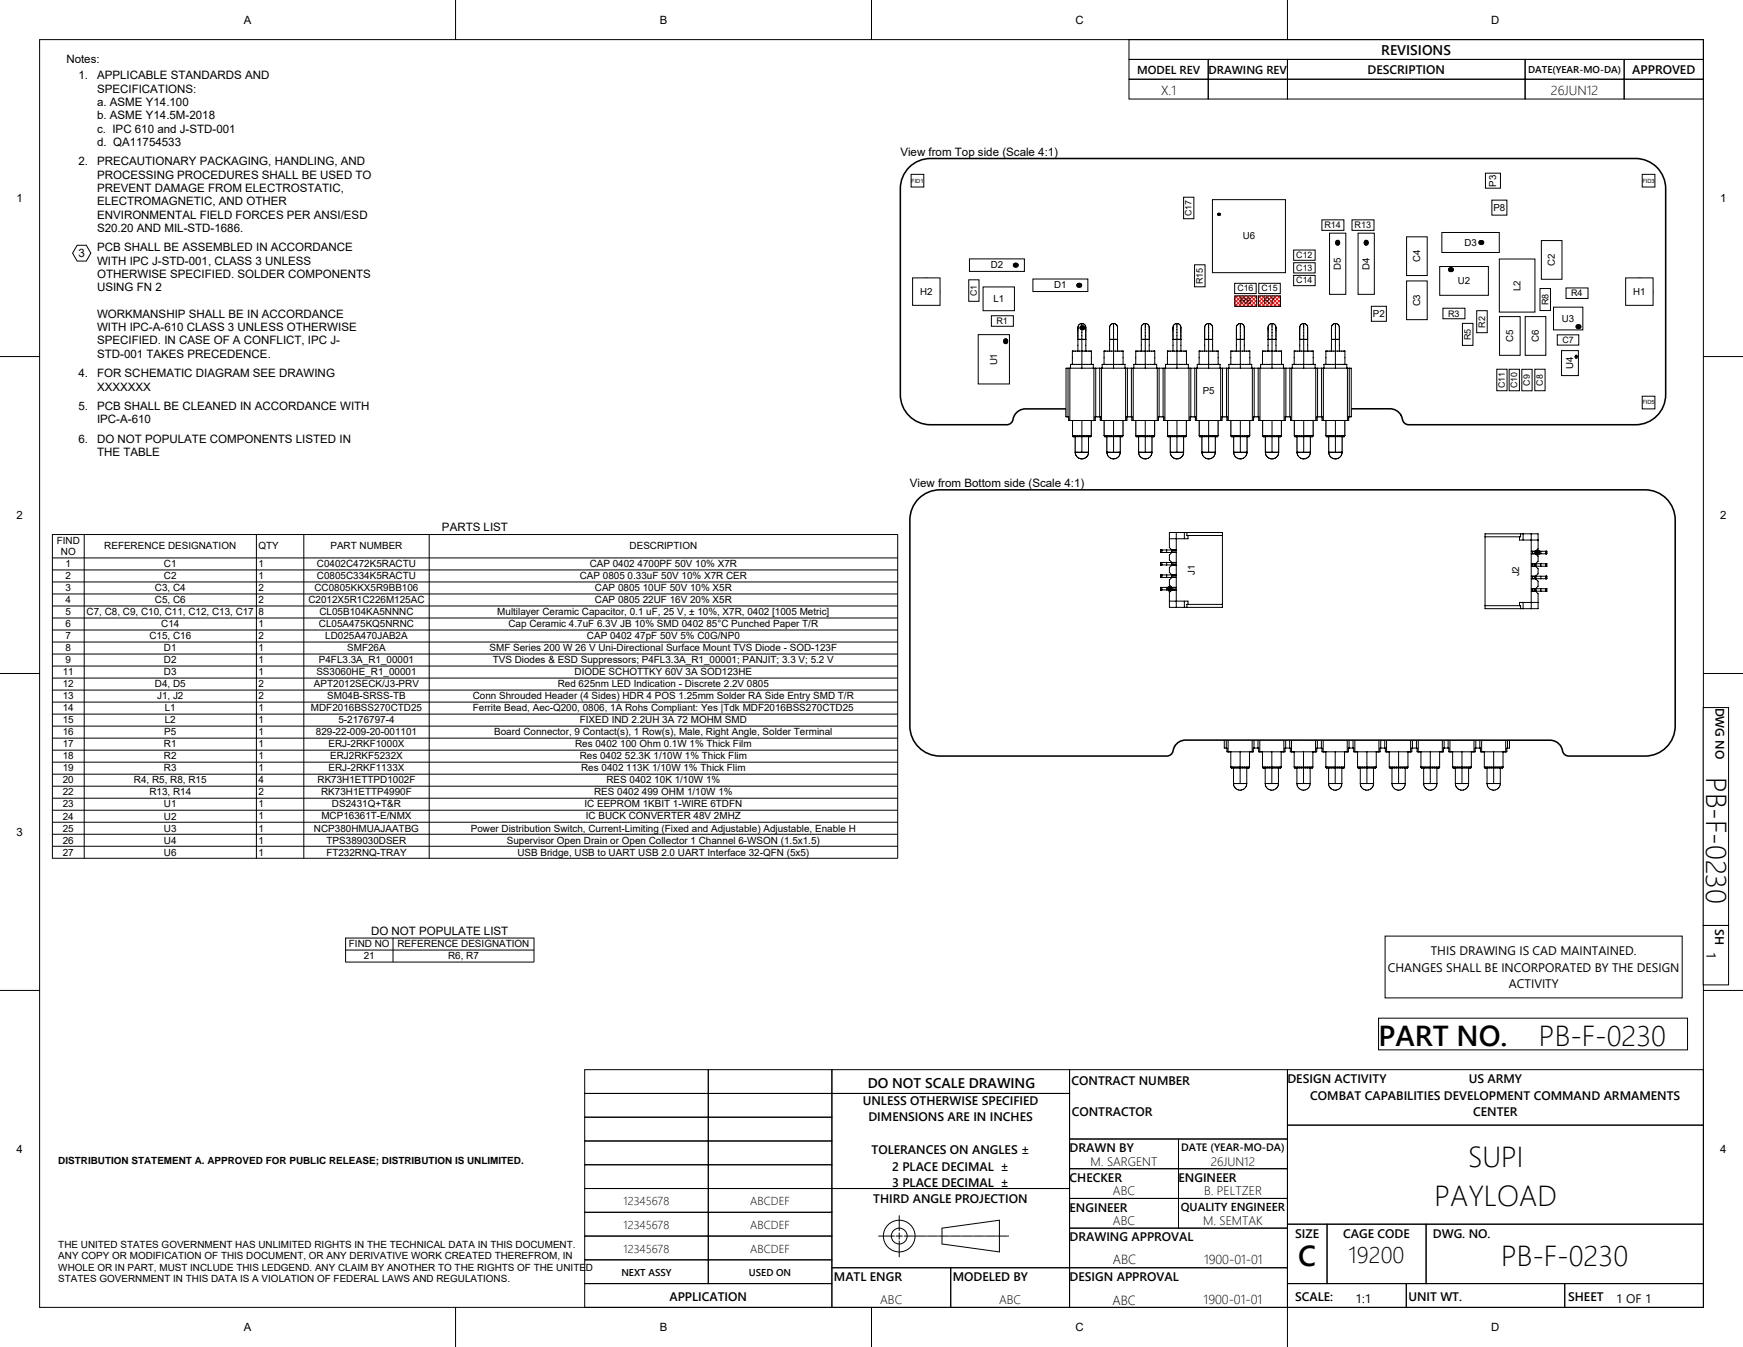
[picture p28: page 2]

Notes:
APPLICABLE STANDARDS AND
SPECIFICATIONS:
a. ASME Y14.100
b. ASME Y14.5M-2018
c. IPC 610 and J-STD-001
PRECAUTIONARY PACKAGING, HANDLING, AND
PROCESSING PROCEDURES SHALL BE USED TO
PREVENT DAMAGE FROM ELECTROSTATIC,
ELECTROMAGNETIC, AND OTHER
ENVIRONMENTAL FIELD FORCES PER ANSI/ESD
S20.20 AND MIL-STD-1686.
PCB SHALL BE ASSEMBLED IN ACCORDANCE
WITH IPC J-STD-001, CLASS 3 UNLESS
OTHERWISE SPECIFIED. SOLDER COMPONENTS
USING FN 2

View from Top side (Scale 4:1)

WORKMANSHIP SHALL BE IN ACCORDANCE
WITH IPC-A-610 CLASS 3 UNLESS OTHERWISE
SPECIFIED. IN CASE OF A CONFLICT, IPC J-
STD-001 TAKES PRECEDENCE.
FOR SCHEMATIC DIAGRAM SEE DRAWING
XXXXXXX
PCB SHALL BE CLEANED IN ACCORDANCE WITH
IPC-A-610
DO NOT POPULATE COMPONENTS LISTED IN
THE TABLE

View from Bottom side (Scale 4:1)

FIND NO | REFERENCE DESIGNATION | QTY | PART NUMBER | DESCRIPTION

1 | C1 | 1 | C0402C472K5RACTU | CAP 0402 4700PF 50V 10% X7R
2 | C2 | 1 | C0805C334K5RACTU | CAP 0805 0.33uF 50V 10% X7R CER
3 | C3, C4 | 2 | CC0805KKX5R9BB106 | CAP 0805 10UF 50V 10% X5R
4 | C5, C6 | 2 | C2012X5R1C226M125AC | CAP 0805 22UF 16V 20% X5R
5 | C7, C8, C9, C10, C11, C12, C13, C17 | 8 | CL05B104KA5NNNC | Multilayer Ceramic Capacitor, 0.1 uF, 25 V, ± 10%, X7R, 0402 [1005 Metric]
6 | C14 | 1 | CL05A475KQ5NRNC | Cap Ceramic 4.7uF 6.3V JB 10% SMD 0402 85°C Punched Paper T/R
7 | C15, C16 | 2 | LD025A470JAB2A | CAP 0402 47pF 50V 5% C0G/NP0
8 | D1 | 1 | SMF26A | SMF Series 200 W 26 V Uni-Directional Surface Mount TVS Diode - SOD-123F
9 | D2 | 1 | P4FL3.3A_R1_00001 | TVS Diodes & ESD Suppressors; P4FL3.3A_R1_00001; PANJIT; 3.3 V; 5.2 V
11 | D3 | 1 | SS3060HE_R1_00001 | DIODE SCHOTTKY 60V 3A SOD123HE
12 | D4, D5 | 2 | APT2012SECK/J3-PRV | Red 625nm LED Indication - Discrete 2.2V 0805
13 | J1, J2 | 2 | SM04B-SRSS-TB | Conn Shrouded Header (4 Sides) HDR 4 POS 1.25mm Solder RA Side Entry SMD T/R
14 | L1 | 1 | MDF2016BSS270CTD25 | Ferrite Bead, Aec-Q200, 0806, 1A Rohs Compliant: Yes |Tdk MDF2016BSS270CTD25
15 | L2 | 1 | 5-2176797-4 | FIXED IND 2.2UH 3A 72 MOHM SMD
16 | P5 | 1 | 829-22-009-20-001101 | Board Connector, 9 Contact(s), 1 Row(s), Male, Right Angle, Solder Terminal
17 | R1 | 1 | ERJ-2RKF1000X | Res 0402 100 Ohm 0.1W 1% Thick Film
18 | R2 | 1 | ERJ2RKF5232X | Res 0402 52.3K 1/10W 1% Thick Flim
19 | R3 | 1 | ERJ-2RKF1133X | Res 0402 113K 1/10W 1% Thick Flim
20 | R4, R5, R8, R15 | 4 | RK73H1ETTPD1002F | RES 0402 10K 1/10W 1%
22 | R13, R14 | 2 | RK73H1ETTP4990F | RES 0402 499 OHM 1/10W 1%
23 | U1 | 1 | DS2431Q+T&R | IC EEPROM 1KBIT 1-WIRE 6TDFN
24 | U2 | 1 | MCP16361T-E/NMX | IC BUCK CONVERTER 48V 2MHZ
25 | U3 | 1 | NCP380HMUAJAATBG | Power Distribution Switch, Current-Limiting (Fixed and Adjustable) Adjustable, Enable H
26 | U4 | 1 | TPS389030DSER | Supervisor Open Drain or Open Collector 1 Channel 6-WSON (1.5x1.5)
27 | U6 | 1 | FT232RNQ-TRAY | USB Bridge, USB to UART USB 2.0 UART Interface 32-QFN (5x5)

1 DWG NO PB-F-0230 SH

DO NOT POPULATE LIST

FIND NO | REFERENCE DESIGNATION
21 | R6, R7

THIS DRAWING IS CAD MAINTAINED.
CHANGES SHALL BE INCORPORATED BY THE DESIGN
PART NO. PB-F-0230

UNLESS OTHERWISE SPECIFIED
DIMENSIONS ARE IN INCHES

DESIGN ACTIVITY
COMBAT CAPABILITIES DEVELOPMENT COMMAND ARMAMENTS

DISTRIBUTION STATEMENT A. APPROVED FOR PUBLIC RELEASE; DISTRIBUTION IS UNLIMITED.

THE UNITED STATES GOVERNMENT HAS UNLIMITED RIGHTS IN THE TECHNICAL DATA IN THIS DOCUMENT.
ANY COPY OR MODIFICATION OF THIS DOCUMENT, OR ANY DERIVATIVE WORK CREATED THEREFROM, IN
WHOLE OR IN PART, MUST INCLUDE THIS LEDGEND. ANY CLAIM BY ANOTHER TO THE RIGHTS OF THE UNITED
STATES GOVERNMENT IN THIS DATA IS A VIOLATION OF FEDERAL LAWS AND REGULATIONS.

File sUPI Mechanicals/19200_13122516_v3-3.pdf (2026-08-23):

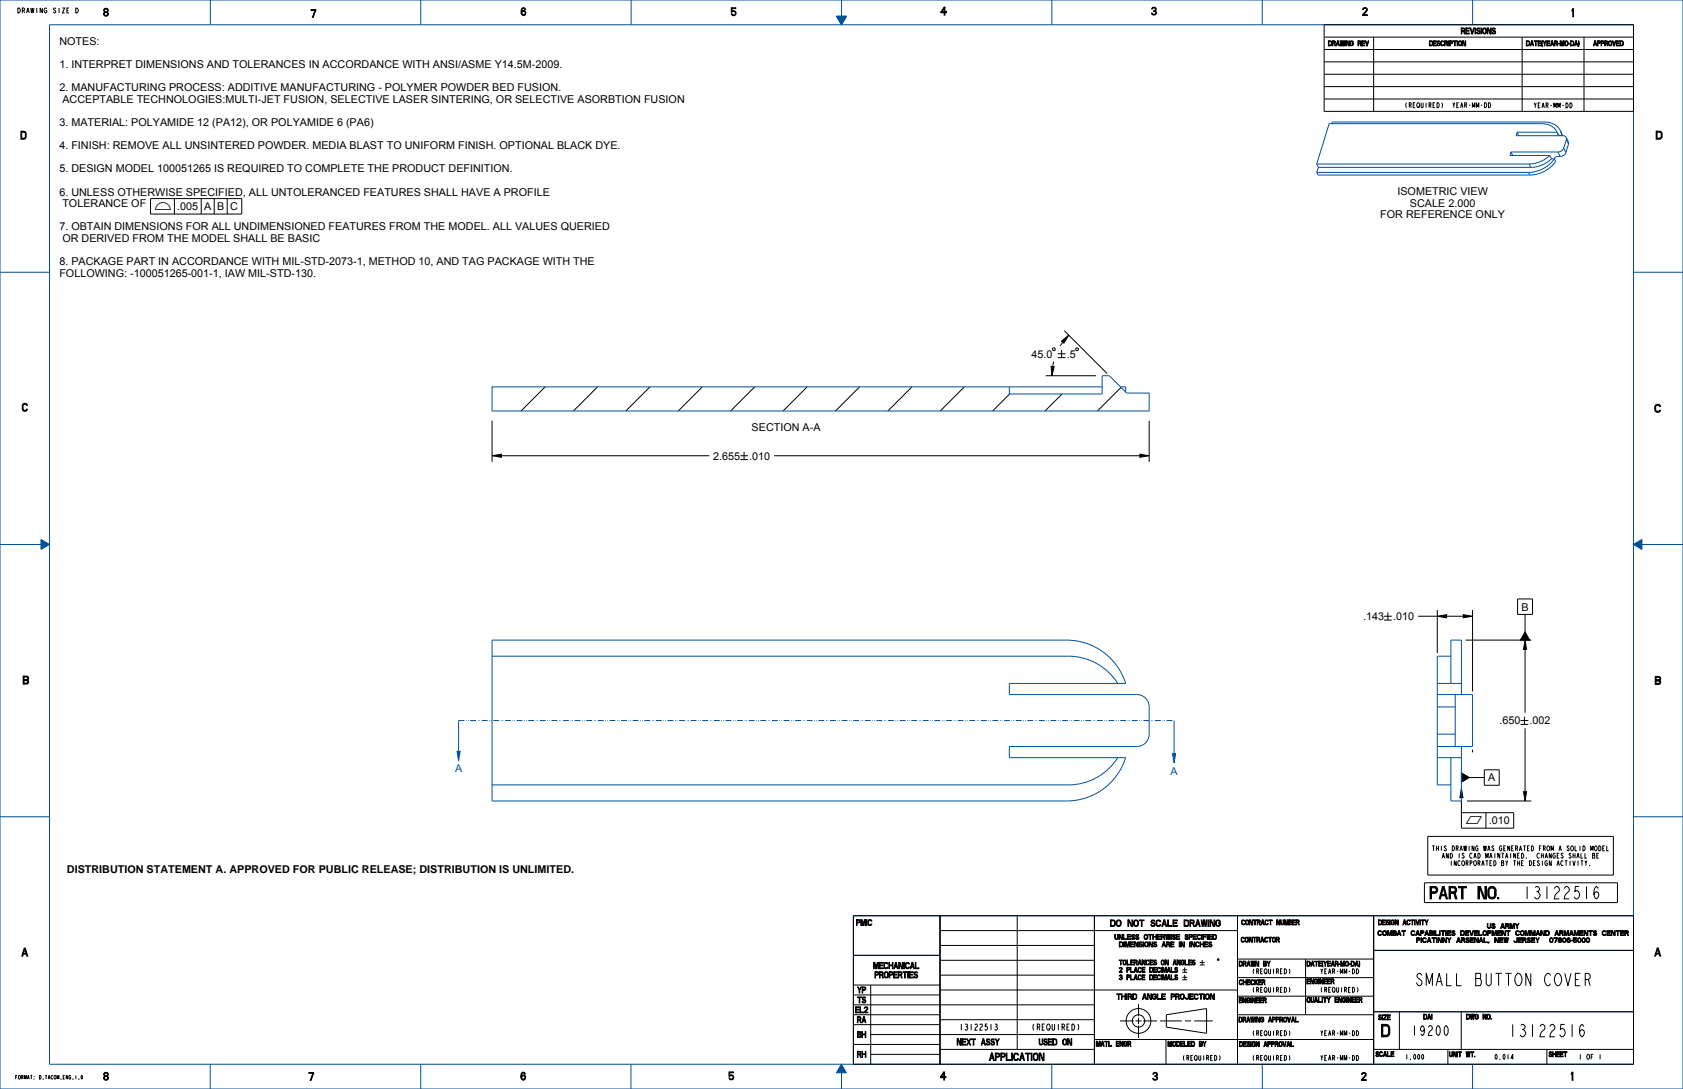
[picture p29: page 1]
SIZE; DAI; SCALE; UNIT WT.; DRAWN; DATE(YEAR-MO-DA); CHECKER; ENGINEER; QUALITY; DRAWING APPROVAL; MATL ENGR; MODELED; DESIGN APPROVAL; CONTRACT; NUMBER; CONTRACTOR; SHEET; DRAWING SIZE D; PLACE; DECIMALS; FORMAT: D_TACOM_ENG_1_0; DWG NO.; REVISIONS; DRAWING; REV; DESCRIPTION; APPROVED; (REQUIRED) YEAR-MM-DD; YEAR-MM-DD; US ARMY; COMBAT; CAPABILITIES; DEVELOPMENT COMMAND; ARMAMENTS CENTER; PICATINNY ARSENAL,; NEW JERSEY 07806-5000; (REQUIRED); APPLICATION; NEXT ASSY; USED ON; PMIC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

NOTES:
1. INTERPRET DIMENSIONS AND TOLERANCES IN ACCORDANCE WITH ANSI/ASME Y14.5M-2009.
2. MANUFACTURING PROCESS: ADDITIVE MANUFACTURING - POLYMER POWDER BED FUSION.
ACCEPTABLE TECHNOLOGIES:MULTI-JET FUSION, SELECTIVE LASER SINTERING, OR SELECTIVE ASORBTION FUSION
3. MATERIAL: POLYAMIDE 12 (PA12), OR POLYAMIDE 6 (PA6)
4. FINISH: REMOVE ALL UNSINTERED POWDER. MEDIA BLAST TO UNIFORM FINISH. OPTIONAL BLACK DYE.
5. DESIGN MODEL 100051265 IS REQUIRED TO COMPLETE THE PRODUCT DEFINITION.
6. UNLESS OTHERWISE SPECIFIED, ALL UNTOLERANCED FEATURES SHALL HAVE A PROFILE
TOLERANCE OF
7. OBTAIN DIMENSIONS FOR ALL UNDIMENSIONED FEATURES FROM THE MODEL. ALL VALUES QUERIED
OR DERIVED FROM THE MODEL SHALL BE BASIC
8. PACKAGE PART IN ACCORDANCE WITH MIL-STD-2073-1, METHOD 10, AND TAG PACKAGE WITH THE
FOLLOWING: -100051265-001-1, IAW MIL-STD-130.

ISOMETRIC VIEW
SCALE 2.000
FOR REFERENCE ONLY

THIS DRAWING WAS GENERATED FROM A SOLID MODEL
INCORPORATED BY THE DESIGN ACTIVITY.
PART NO. 13122516

DISTRIBUTION STATEMENT A. APPROVED FOR PUBLIC RELEASE; DISTRIBUTION IS UNLIMITED.

DO NOT SCALE DRAWING
UNLESS OTHERWISE SPECIFIED
TOLERANCES ON ANGLES

DESIGN ACTIVITY
SMALL BUTTON COVER

(REQUIRED) | YEAR-MM-DD
(REQUIRED) | (REQUIRED)

YP
TS
EL2
RA

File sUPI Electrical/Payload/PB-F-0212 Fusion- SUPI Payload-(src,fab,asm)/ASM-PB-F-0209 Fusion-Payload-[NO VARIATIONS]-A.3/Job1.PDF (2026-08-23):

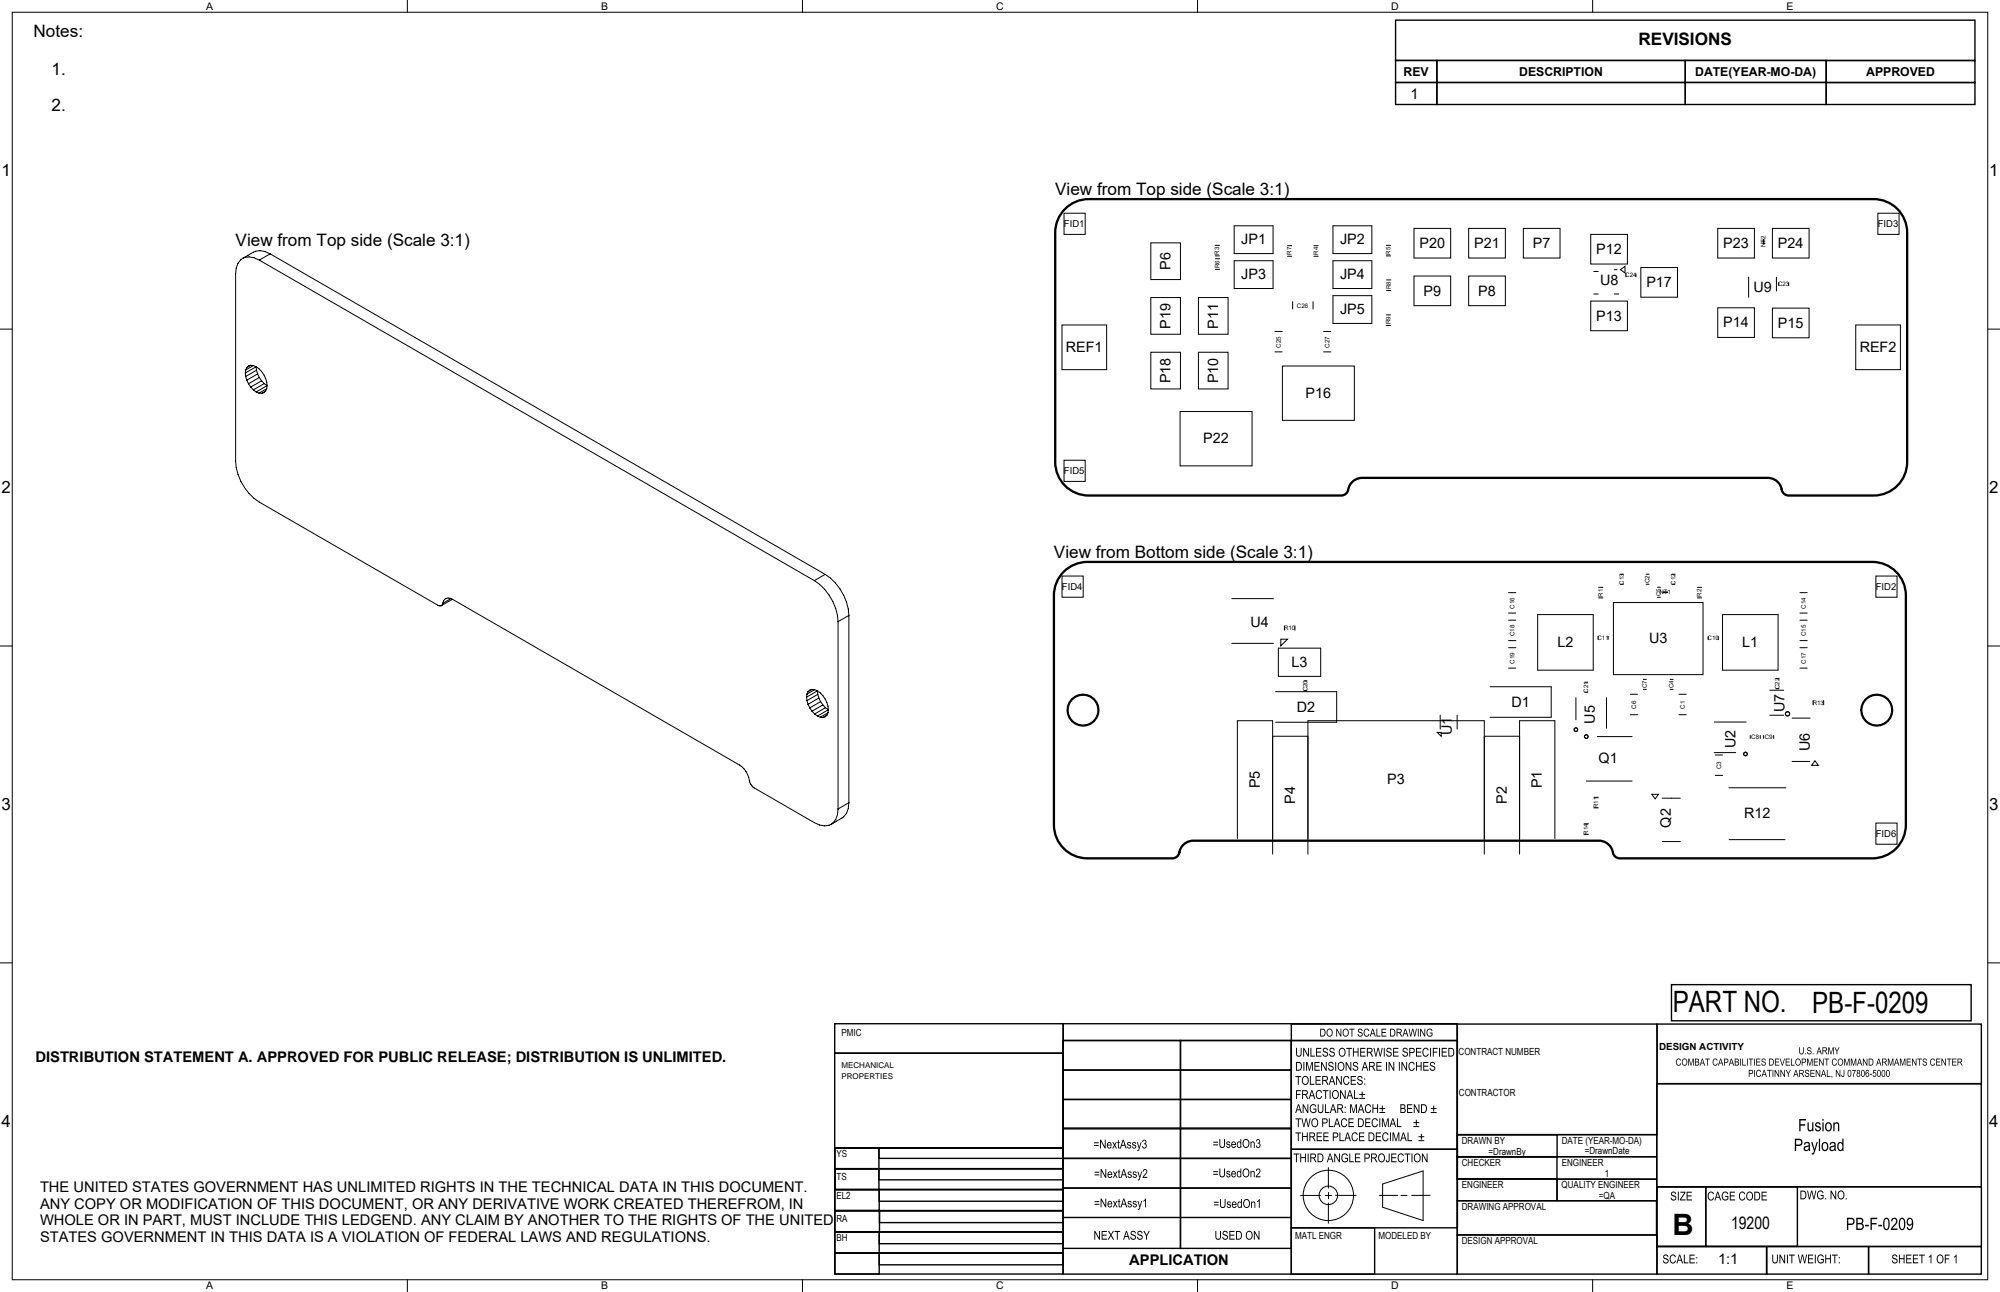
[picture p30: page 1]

View from Top side (Scale 3:1)

View from Bottom side (Scale 3:1)

DISTRIBUTION STATEMENT A. APPROVED FOR PUBLIC RELEASE; DISTRIBUTION IS UNLIMITED.

DATE (YEAR-MO-DA)
=DrawnDate

THE UNITED STATES GOVERNMENT HAS UNLIMITED RIGHTS IN THE TECHNICAL DATA IN THIS DOCUMENT.
ANY COPY OR MODIFICATION OF THIS DOCUMENT, OR ANY DERIVATIVE WORK CREATED THEREFROM, IN
WHOLE OR IN PART, MUST INCLUDE THIS LEDGEND. ANY CLAIM BY ANOTHER TO THE RIGHTS OF THE UNITED

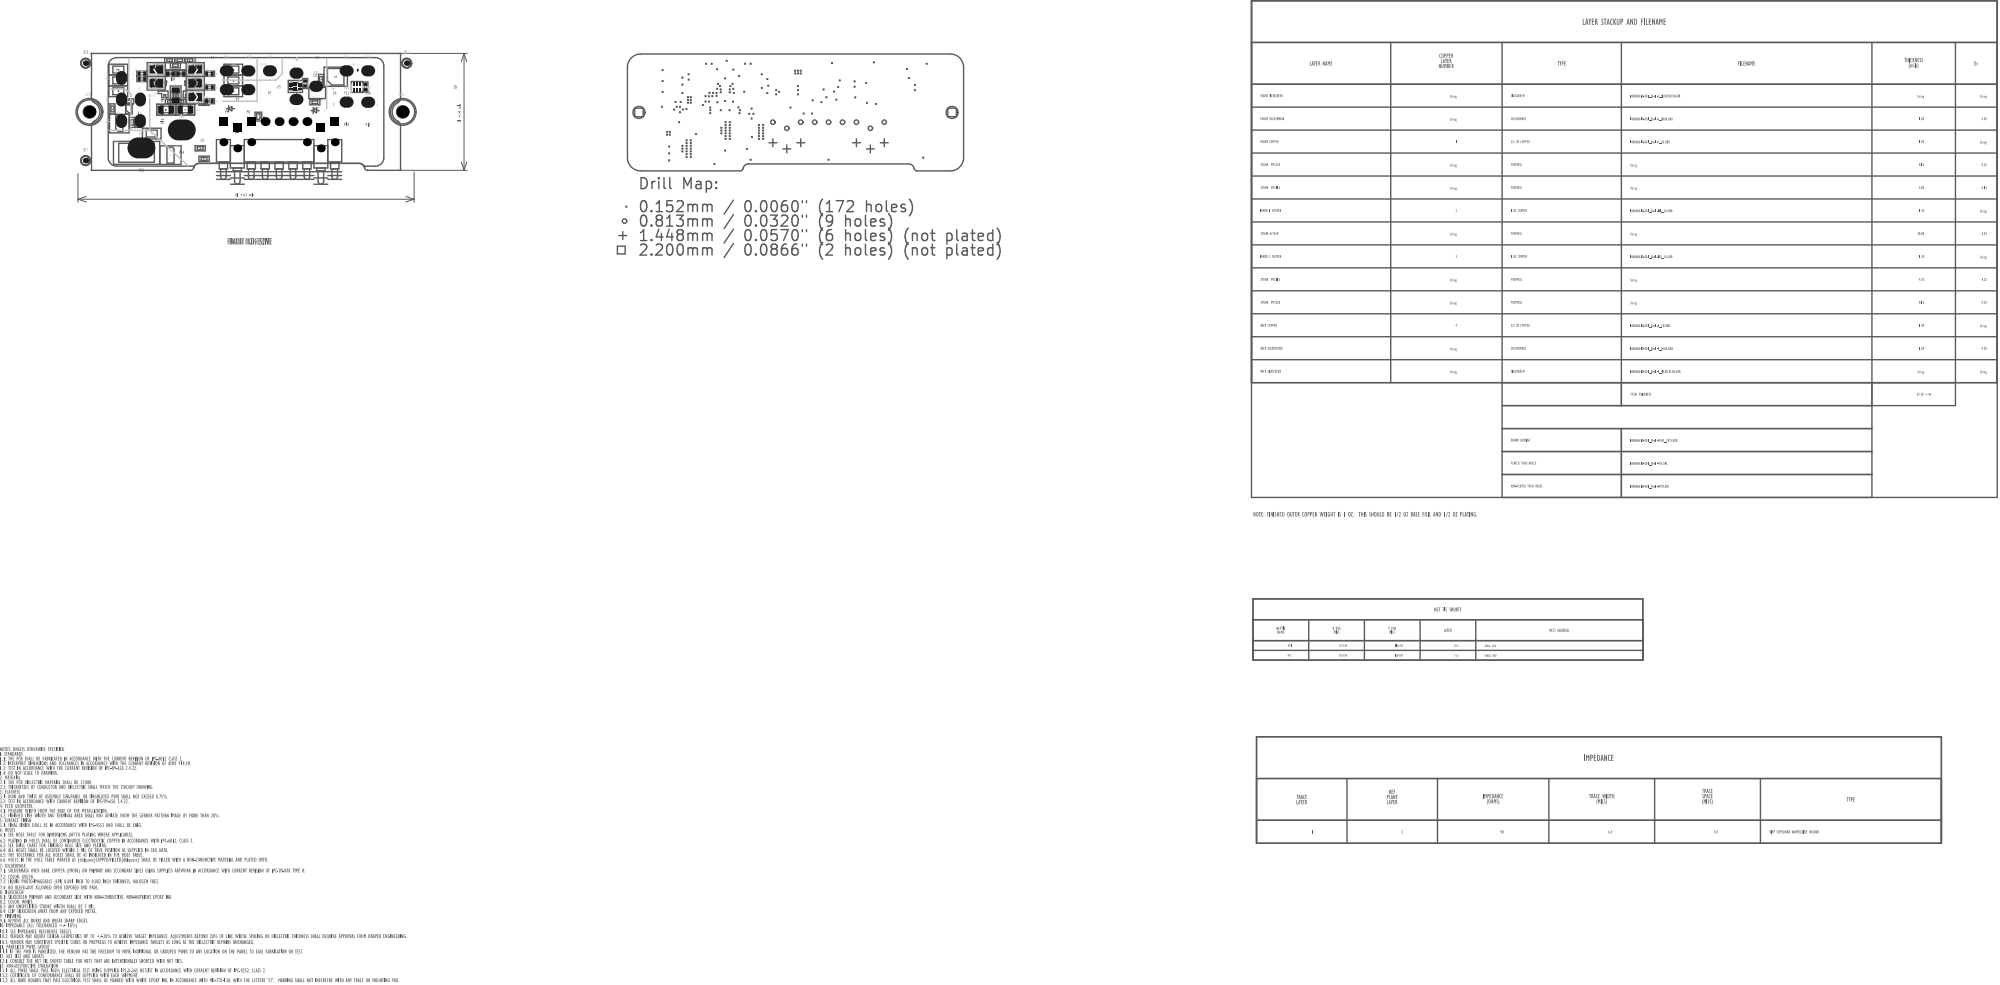
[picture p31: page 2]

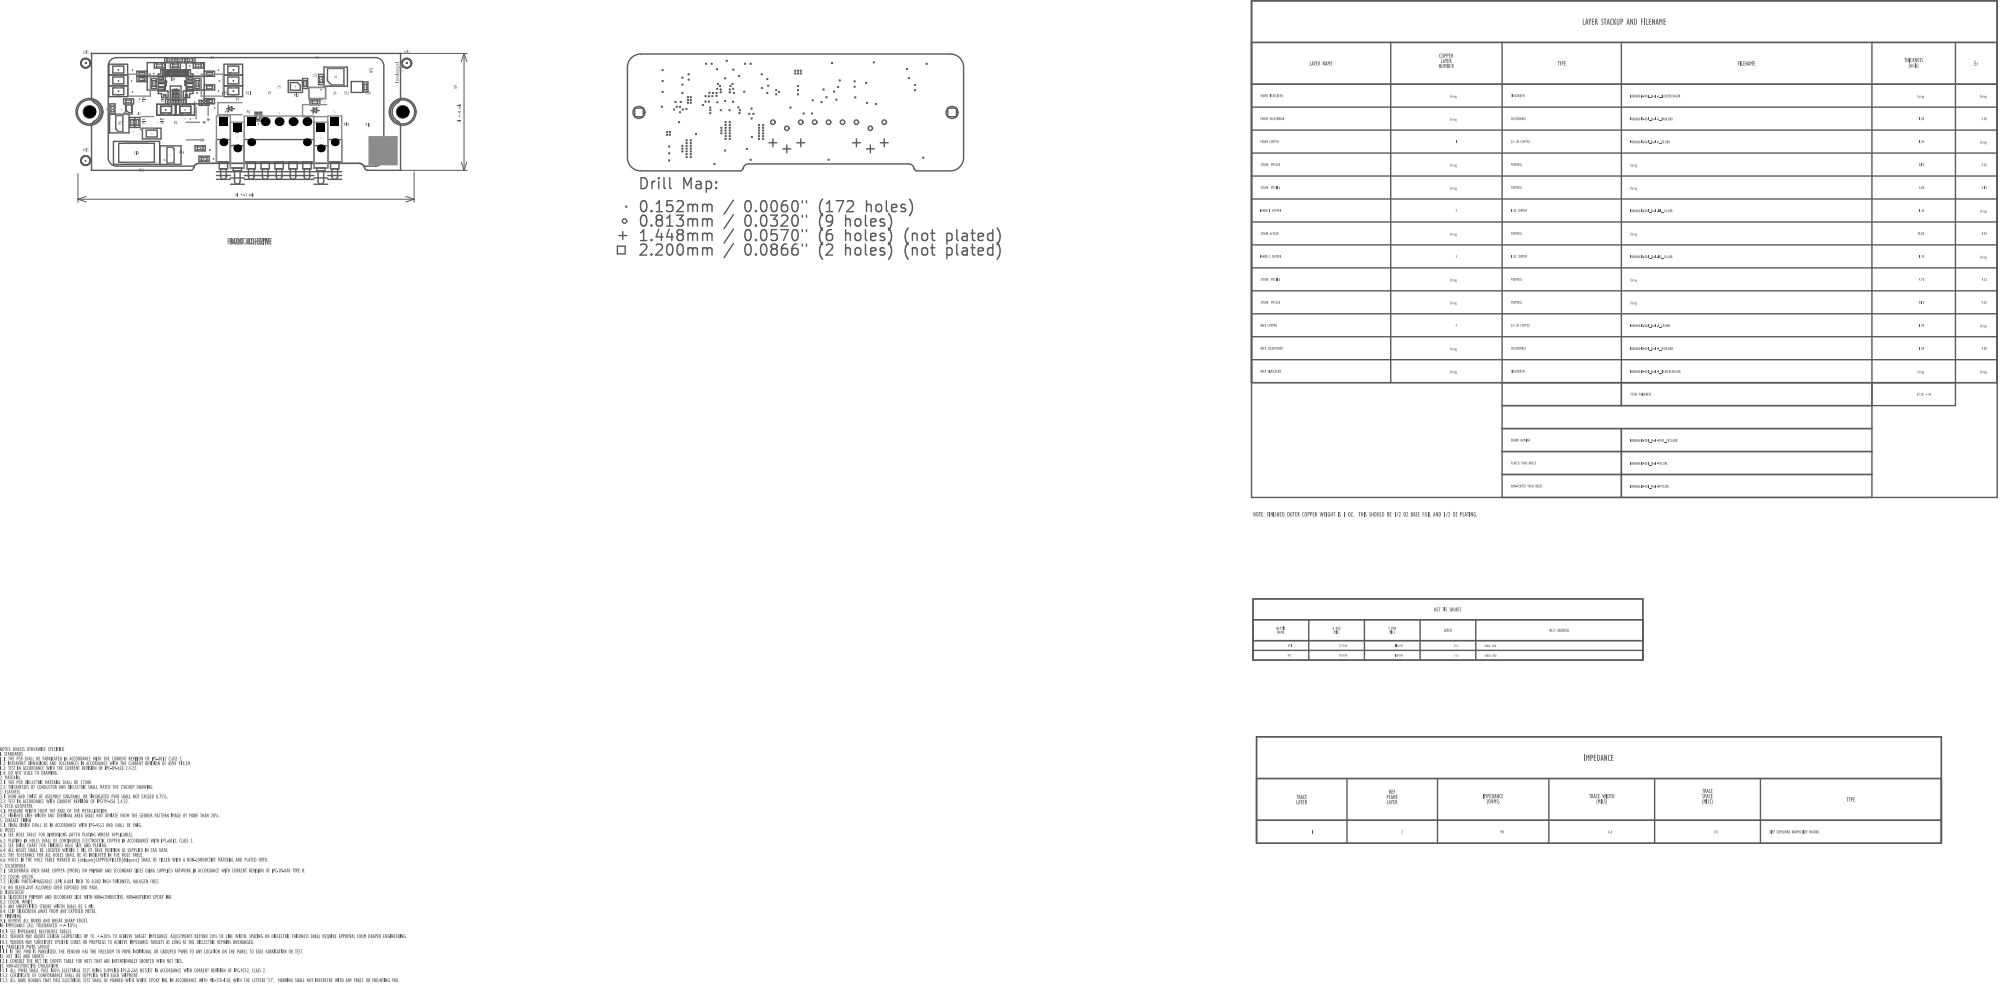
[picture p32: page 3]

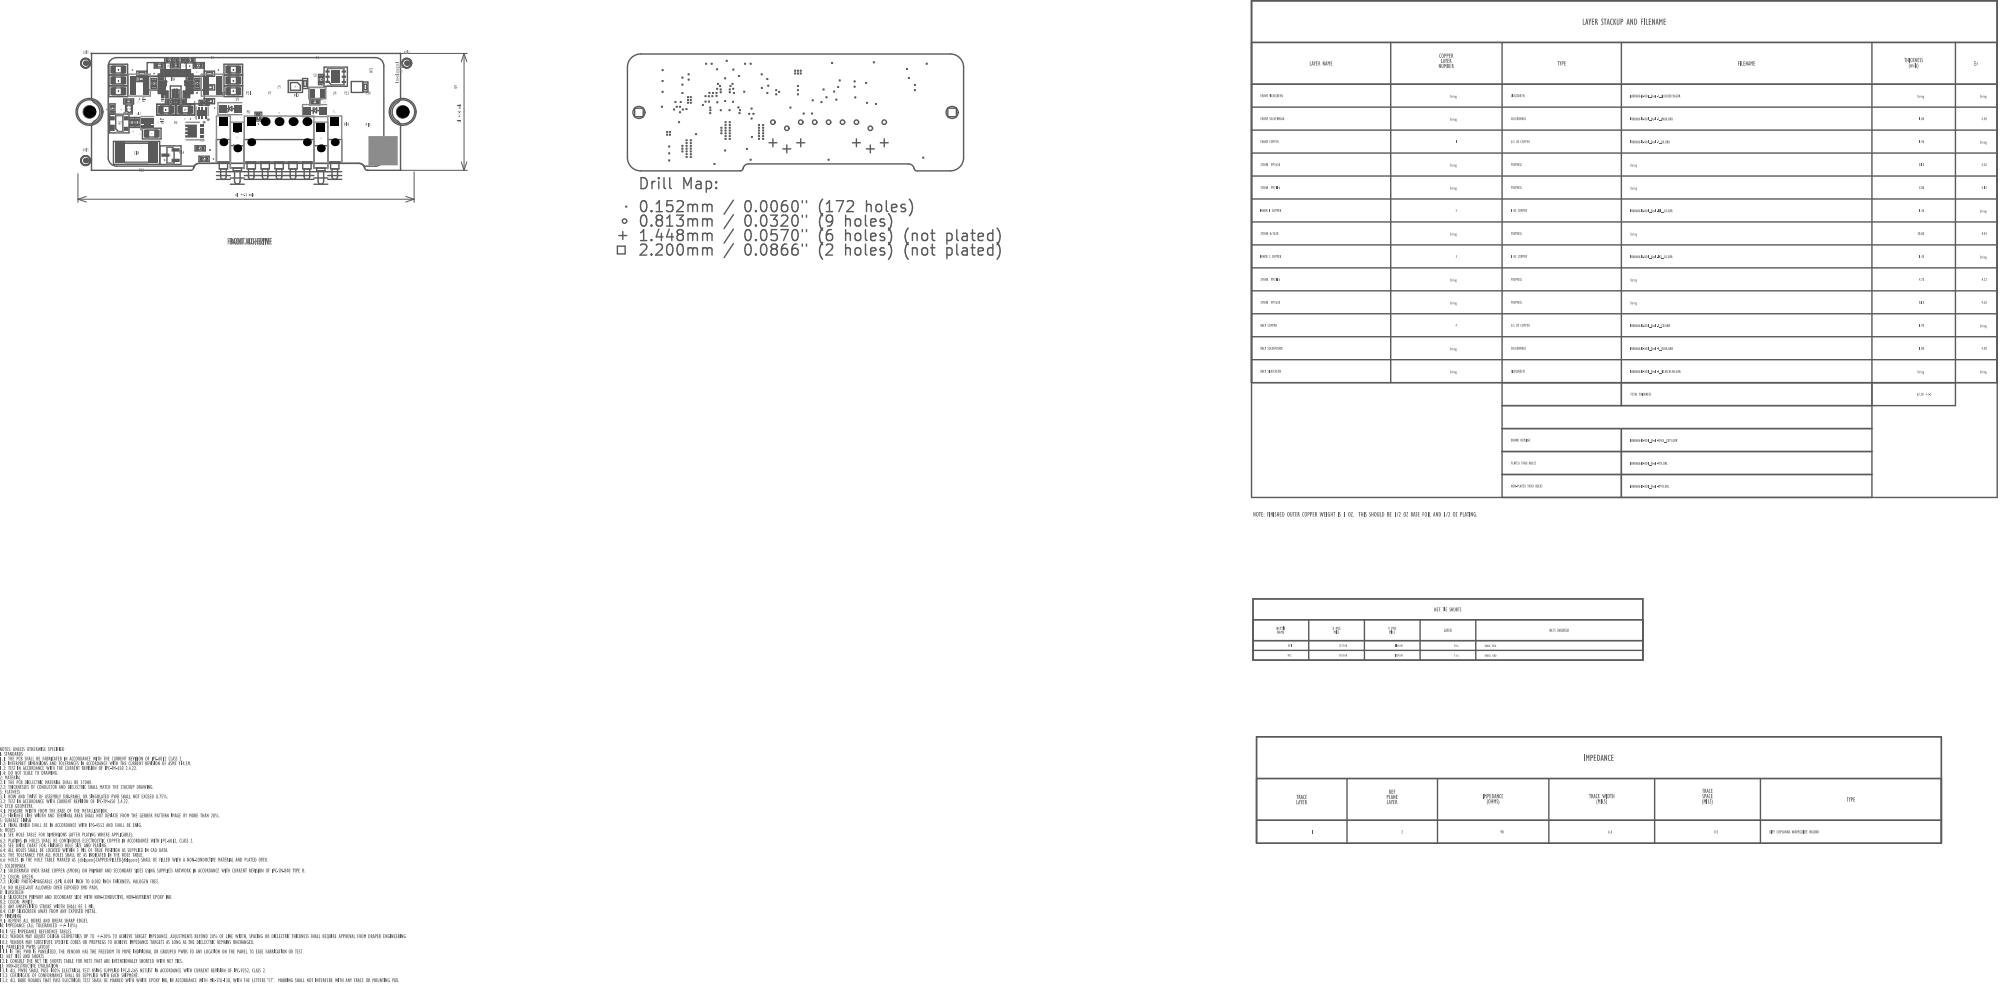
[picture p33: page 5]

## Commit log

2026-08-23 Initial distro A commit
    [100046138_block_diagram.SchDoc, 100046138_block_diagram.SchLib, 100046138_data_switches.SchDoc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]
2026-09-01 readme pwm spec update
